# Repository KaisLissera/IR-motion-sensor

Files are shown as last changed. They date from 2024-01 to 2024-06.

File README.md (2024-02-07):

# IR-motion-sensor
*University graduation work*  

Система электронного хронометража для конных соревнований, временные засечки определяются по моменту пересечения луча

## TODO:
### HW
- Заменить SX1276 на аналогичный модуль без интегрированной антенны или RFM95W
- Добавить на плате земляной полигон без маски для тестирования
- ZQ3 - дорожки от кварца должны быть на верхней части платы
- Заменить все резисторы и конденсаторы 0402 на 0603
- Заменить индуктивности в фильтре аналогового питания на дроссели BLM18AG102 0603
### 3d Model
- Переделать отверстие под USB порт
- ~~Подобрать размер кнопки на передней панели~~
- Облегчить корпус

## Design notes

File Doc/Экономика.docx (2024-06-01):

# 5 Организационно-экономическая часть

## 5.1 Расчёт сметных затрат

Разработка системы электронного хронометража состоит из научно-исследовательской (НИР) и опытно-конструкторской частей (ОКР).

В ходе НИР был проведен анализ технических требований. На их основе с учётом имеющихся производственных возможностей сформировано техническое задание и проведены необходимые теоретические исследования.

ОКР по разработке системы электронного хронометража включал в себя три основных этапа – техническое проектирование, изготовление опытного образца и его испытания. В ходе технического проектирования подготовлена конструкторская документация для изготовления опытного образца и разработано необходимое для его работы программное обеспечение. На этапе изготовления опытного образца выполнено физическое производство и настройка изделия. Было интегрировано и отлажено программного обеспечение необходимое для его работы. В ходе испытаний опытного образца проверено его соответствие требуемым техническим требованиям.

После завершения всех этапов НИОКР, расчёт сметных затрат производится по формуле:

| S_(НИОКР) =S_(пр.мат.) +S_(о.т.) +S_(с.в.) +S_(ар.) +S_(накл.) +S_(исп.об.) , | (5.1)

где S_(пр.мат.) – прямые материальные расходы, S_(о.т.) – расходы на оплату труда, S_(с.в.) – расходы на страховые взносы,
S_(о. х.р.) – общехозяйственные расходы, S_(исп.об.) – расходы на амортизацию оборудования.

## 5.2 Прямые материальные расходы

Прямые материальные расходы на проведение НИОКР складываются из стоимости сырья, материалов, радиоэлектронных компонентов (РЭК), используемых для разработки и производства опытных образцов, а также транспортных издержек, связанных с доставкой этих ресурсов.

Расчёт затрат на основные и вспомогательные материалы S_(мат.) производится по формуле:

| S_(мат.) =∑_(i=1)^m X_i ∙M_i , | (5.2)

где X_i – цена покупки единицы i–го вида материальных ресурсов,
M_i – число материальных ресурсов i–го вида, m – число различных материальных ресурсов.

Транспортные затраты рассчитываются с учетом коэффициента транспортных расходов k_(тр) =1,1 . Таким образом прямые материальные расходы рассчитываются по формуле:

| S_(пр.мат.) =k_(тр) ∙S_(мат.) . | (5.3)

Прямые материальные затраты на этапе технического проектирования НИОКР включают в себя расходы, связанные с разработкой конструкторской документации, в соответствии с требованиями к ее комплектности. Затраты на этапе изготовления опытного образца состоят из затрат на радиоэлектронные компоненты, производство печатных плат, изготовление корпуса, крепежные изделия, а также расходные материалы, необходимые для проведения монтажных работ.

Материальные ресурсы, их цена (с учётом НДС) и требуемое количество для этапов технического проектирования и изготовления опытного образца представлены в таблицах 5.1 и 5.2 соответственно.

Таблица 5.1 – Материальные ресурсы этапа технического проектирования

№ п/п | Наименование | Средняя цена за шт., руб. | Кол-во, шт. | Сумма, руб.
1 | Лист формата А4 | 0,8 | 19 | 15,2
2 | Лист формата А3 | 18 | 11 | 198
3 | Лист формата А2 | 30 | 2 | 60
5 | Ручка гелиевая черная 0.5 мм | 50 | 1 | 50
9 | Штрих-корректор | 50 | 1 | 50
| Картридж лазерный для принтера А3 | 1569 | 1 | 1596
| | | Итого: | 1 969,2

Таблица 5.2 – Материальные ресурсы этапа изготовления опытного образца

Наименование | Цена за шт., руб. | Кол-во, шт. | Сумма, руб.

Конденсаторы
1 пФ | 10 | 1 | 10
5,6 пФ | 10 | 3 | 30
18 пФ | 0,4 | 12 | 4,8
100 пФ | 7 | 3 | 21
680 пФ | 0,4 | 1 | 0,4
100 нФ | 0,4 | 42 | 16,8
10 мкФ | 0,4 | 9 | 3,6

Микросхемы
MCP1700-3300 | 9 | 3 | 27
MCP6001 | 33 | 1 | 33
STM32F072RBT6 | 127 | 3 | 381
TSOP4836 | 37 | 1 | 37

Индуктивности
1,2 нГн | 12 | 1 | 12
BLM18AG102SN1D | 3 | 6 | 18

Резисторы
0 Ом | 0,4 | 1 | 0,4
10 Ом | 0,4 | 1 | 0,4
100 Ом | 0,4 | 1 | 0,4
1 кОм | 0,4 | 19 | 7,6
5,1 кОм | 0,4 | 6 | 2,4
10 кОм | 0,4 | 3 | 1,2
100 кОм | 0,4 | 8 | 3,2

Переключатели кнопочные
KLS7-TS6601-5.0-180 | 9 | 3 | 27
KLS7-P8.5x8.5-1 | 21 | 2 | 32

Диоды
USBLC6-2SC6 | 10 | 3 | 30
ESDA5V3L | 10 | 2 | 20
BAT760 | 9 | 3 | 27
SFH213FA | 110 | 1 | 110
SMD05050C6 | 1,1 | 3 | 3,3

Разъёмы
PLS-2R тип D | 1,7 | 3 | 5,1
PLS-6R тип D | 5,1 | 3 | 15,3
USB Type-C 213716-0001 | 17 | 3 | 51

Резонаторы кварцевые
12MHz SMD03225C4 | 9,5 | 3 | 28,5
32.768kHz SMD03215C2 | 18,6 | 3 | 55,8

Прочие РЭК
MF-MSMF050 0,5А | 5 | 3 | 15
HC0905A | 10 | 3 | 30
RFM95W | 350 | 3 | 1050
SI2302A | 4 | 7 | 28
Наименование | Цена за шт., руб. | Кол-во, шт. | Сумма, руб.

Крепёж
Винт М2х5 | 2,2 | 12 | 26,4
Винт М3х5 | 1,4 | 12 | 16,8
Вставка резьбовая М2хL3 | 2,1 | 12 | 25,2
Вставка резьбовая М3хL3 | 2,5 | 12 | 30

Материалы
Провод гибкий 24AWG красный | 1 | 1 шт., 200 мм | 119
Провод гибкий 24AWG чёрный | 1 | 1 шт., 200 мм | 119
Пластик АВС-2802-31 | 1 | 1 шт., 1 кг | 1794
Припой ПОС-61 | 1 | 1 шт., 100 г | 597
Флюс ЛТИ-120 | 1 | 1 шт., 20 мл | 350
Жидкость для очистки бензин «Галоша» | 1 | 1 шт., 500мл | 407

Прочее
Платы печатные | - | 3 | 819
Контакт отрицательный для батареи типа АА | 3,4 | 6 | 20,6
Контакт положительный для батареи типа АА | 3,4 | 6 | 20,6
Элемент питания АА | 70 | 6 | 420
Вилка на кабель HU-02 | 2 | 3 | 6
| | | Итого: | 6 908,8

Согласно формуле 5.2, затраты на основные и вспомогательные материалы на всех этапах НИОКР составляют:

S_(мат.) =S_(мат.(проект.)) +S_(мат.(изготовл.)) =1 969,2+6 908,8=8 878 руб .

С учётом транспортных затрат по формуле 5.3 прямые материальные расходы на НИОКР составят:

S_(пр.мат.) =k_(тр) ∙S_(мат.) =1,1∙8 878=9 765,8.

## 5.3 Расчёт трудоёмкости проекта и расходов на заработную плату

Согласно техническому заданию НИОКР должны быть выполнены в период с 4 марта 2024 года по 31 мая 2024 года, что составляет 60 рабочих дней. При 40-часовой рабочей неделе длительность рабочего дня составляет 8 часов, таким образом на выполнение НИОКР отводится 480 часов.

Трудоёмкость проекта рассчитывается с учётом норм времени, установленных ШИФР 13.01.01 «Типовые нормативы времени на разработку конструкторской документации».

Таблица 5.4 – Перечень разработанной конструкторской документации

Документ | | Формат | Число листов | Норма времени, ч
МГТУ.403443.001 | Спецификация | А4 | 1 | 0,3
МГТУ.403443.001 Э1 | Схема электрическая структурная | А3 | 1 | 3,36
МГТУ.464415.001 | Спецификация | А4 | 2 | 0,7
МГТУ.464415.001 CБ | Чертёж сборочный | А3 | 1 | 1,7
МГТУ.464415.002 | Спецификация | А4 | 3 | 1,6
МГТУ.464415.002 СБ | Чертёж сборочный | А3 | 2 | 2,4
МГТУ.469335.001 | Спецификация | А4 | 5 | 4
МГТУ.469335.001 СБ | Чертёж сборочный | А3 | 2 | 4
МГТУ.469335.001 Э3 | Схема электрическая принципиальная | А2 | 1 | 25,92
МГТУ.469335.001 ПЭ3 | Перечень элементов | А4 | 5 | 4,7
МГТУ.713621.001 | Чертёж | А4 | 1 | 0,53
МГТУ.731146.001 | Чертёж | А3 | 2 | 1,2
МГТУ.741316.001 | Чертёж | А4 | 1 | 0,35
МГТУ.741344.001 | Чертёж | А3 | 2 | 2,92
МГТУ.758741.001 | Чертёж | А3 | 2 | 1,43
| | | Итого: | 55,11

Последовательность этапов НИОКР, исполнитель и длительность приведены в таблице 5.5.

Таблица 5.5 – Последовательность этапов НИОКР

№ этапа | Содержание этапа работ | Исполнитель | Длительность этапа
1 | НИР | | 28% | 136 ч.
1.1 | Разработка технического задания | Инженер-конструктор | 2% | 8
1.2 | Теоретические исследования | Инженер-конструктор | 26% | 128
2 | ОКР | | 72% | 344 ч.
2.1 | Разработка конструкторской документации | Инженер-конструктор | 12% | 56
2.2 | Разработка программного обеспечения | Инженер-программист | 17% | 80
2.3 | Изготовление опытного образца | Монтажник РЭА | 8% | 40
2.4 | Испытания опытного образца | Инженер-конструктор | 10% | 48
2.5 | Оформление расчётно-пояснительной записки | Инженер-конструктор | 25% | 120
Итого | | | 100% | 480 ч.

Требуемые для выполнения этапов НИОКР сотрудники, количество их рабочих часов и приведены в таблице 5.6.

Таблица 5.6 – Требуемые сотрудники

Категория сотрудника | Число сотрудников, чел. | Рабочие часы, ч. | Часовая тарифная ставка, руб./ч.

НИР
Инженер–конструктор | 1 | 136 | 620

ОКР
Инженер–конструктор | 1 | 224 | 620
Инженер-программист | 1 | 80 | 940
Монтажник РЭА и печатных плат | 1 | 40 | 250

Затраты на оплату труда сотрудников S_(о.т.) рассчитываются по формуле:

| S_(о.т.) =S_(з.п.) +S_(з.п.доп) . | (5.4)

где S_(з.п.) – затраты по основной заработной плате, S_(з.п.доп.) – затраты по дополнительной заработной плате.

Затраты по основной заработной плате рассчитываются по формуле:

| S_(з.п.) =∑_(i=1)^k N_i ·T_(р.ч. i) ·L_(ч. i) . | (5.5)

где N_i – число работников, T_(р.ч. i) – число рабочих часов на одного сотрудника, L_(ч. i) – часовая тарифная ставка, k – число различных категорий сотрудников.

Согласно формуле 5.5 затраты по основной заработной плате для реализации каждого из этапов составят:

S_(з.п.(НИР)) =(620∙136) руб.=79 360 руб,

S_(з.п.(ОКР)) =(620∙224+80∙940+40∙250) руб.=224 080 руб,

S_(з.п.) =S_(з.п.(НИР)) +S_(з.п.(ОКР)) =303 440 руб.

Затраты по дополнительной заработной плате вычисляются по формуле:

| S_(з.п.доп) =α·S_(з.п.осн) , | (5.6)

где α –отношение дополнительной заработной платы к основной.

Пусть затраты по дополнительной заработной плате составляют 10% от основной заработной платы, тогда по формуле 5.6 для каждого из этапов затраты составят:

S_(з.п.доп.(НИР)) =(79 360 ·0,1) руб.=7 936 руб,

S_(з.п.доп.(ОКР)) =(224 080 ·0,1) руб.=22 408 руб,

S_(з.п.доп.) =(7 936+22 408) руб.=30 344 руб.

Согласно формуле 5.4 затраты на оплату труда для реализации каждого из этапов и для НИОКР в целом составят:

S_(о.т.(проект.)) =(79 360+7 936) руб=87 296 руб,

S_(о.т.(прозв.)) =(224 080+22 408) руб.=246 488руб,

S_(о.т.) =(303 440+30 344) руб. =333 784 руб.

## 5.4 Расходы на страховые взносы

Страховые взносы состоят из:

- страховых взносов на пенсионное страхование – 22%;
- страховых взносов на медицинское страхование – 5,1%;
- страховые взносы на социальное страхование – 2,9%;
- страховые взносы на случай несчастных случаев и профессиональных заболеваний – 0,2%.

Поскольку разработка системы электронного хронометража — это разовые краткосрочные работы, с работниками можно заключить договор гражданско-правового характера (ГПХ), без оформления их в штат. Оплата труда будет производиться на основании выполненных работ, а не в виде заработной платы. В случае заключения договора ГПХ работодатель не платит страховые взносы на социальное страхование и взносы на случай несчастных случаев и профессиональных заболеваний.

Таким образом суммарно затраты на страховые взносы k_c равны 27,1% от всей заработной платы и рассчитываются по формуле:

S_(с.в.) =k_c ·S_(о.т.) . | (5.7)

Согласно формуле 5.7 суммарные затраты на страховые взносы составят

S_(с.в.) =(0,271∙333 784) руб.=90 456 руб.

## 5.5 Расходы на аренду

Помещение для проведения НИОКР имеет площадь достаточную для размещения рабочих мест для всех работников необходимых для его реализации, площади 25 м^2 достаточно для размещения трёх рабочих мест, план рабочей комнаты приведён в разделе 6. Средняя стоимость аренды одного квадратного метра производственной площади, с учётом коммунальных услуг, в Москве составляет около 12 000 руб. в год или 1 000 руб. в месяц. Учитывая соотношения длительностей этапов, затраты на аренду для реализации каждого из этапов и для НИОКР в целом составят:

S_(ар.(НИР)) =(1 000∙3∙ 0,27∙25) руб.=20 250 руб,

S_(ар.(ОКР)) =(1 000∙3∙0,73∙ 25) руб.=54 750 руб,

S_(ар) =(1 000∙3∙ 25) руб.=75 000 руб.

## 5.6 Накладные расходы

Накладные расходы связаны с организацией, обслуживанием и управлением производством. Они включают в себя расходы на содержание управленческого аппарата, бухгалтерию, юридическое сопровождение, содержание информационной инфраструктуры, закупку офисных принадлежностей. Для обеспечения накладных затрат выделена сумма в 50% от основной заработной платы. Тогда накладные расходы для реализации каждого из этапов и для НИОКР в целом:

S_(накл.(НИР)) =(79 360 ·0,5) руб.=39 680 руб,

S_(накл.(ОКР)) =(224 080 ·0,5) руб.=112 040 руб,

S_(накл.) =(39 680+112 040) руб.=151 720 руб.

## 5.7 Расходы на использование оборудования

Использованное в процессе выполнения НИОКР оборудование приведено в таблице 5.7.

Таблица 5.7 – Используемое оборудование

Наименование | Балансовая стоимость, руб. | Кол-во, шт.
Персональный компьютер | 110 000 | 3
Лазерное МФУ HP LaserJet M442dn | 67 000 | 1
Лабораторный блок питания ELEMENT 1502D | 2 500 | 1
Паяльная станция ELMENT 878D | 5 500 | 1
Цифровой осциллограф FNIRSI 1014D | 13 000 | 1
Мультиметр цифровой DT-830B | 250 | 1
Векторный анализатор цепей NanoRFE VNA6000 | 150 000 | 1

На объекты основных средств стоимостью до 10 000 рублей включительно амортизация не начисляется. На объекты основных средств стоимостью от 10 000 до 100 000 рублей амортизация начисляется в размере 100% первоначальной стоимости при выдаче его в эксплуатацию. Имущество дороже 100 000 рублей со сроком полезного использования (СПИ) более 12 месяцев включается в состав основных средств и амортизируется. СПИ определяется в соответствии с постановлением правительства РФ от 01.01.2002 N 1 (ред. от 18.11.2022) "О Классификации основных средств, включаемых в амортизационные группы". Согласно постановлению СПИ персонального компьютера составляет 3 года, а векторного анализатора цепей 10 лет.

Годовые амортизационные отчисления A_i рассчитываются по формуле:

| A_i =a_i ·Ц_i , | (5.8)

где a_i – норма амортизации, Ц_i – балансовая стоимость оборудования.

По формуле 5.8 амортизационные отчисления за 3 месяца НИОКР составят:

A=3(0,1∙150 000)/12+3(0,33∙110 000)/12=12 825 руб.

Затраты на ремонтное обслуживание примем равными 1,5%, а на электроэнергию – 10% от величины амортизационных отчислений.

Затраты на использование оборудования включают в себя амортизацию, затраты на энергию и ремонт, и для реализации каждого из этапов и для НИОКР в целом составят:

S_(исп.об.) =(1,115∙12 825) руб.=14 300 руб.,

S_(исп.об.(НИР)) =(14 300 ·0,27) руб.=3 861 руб,

S_(исп.об.(ОКР)) =(14 300 ·0,73) руб.=10 439 руб.

## 5.8 Расчёт сметной себестоимости НИОКР

Рассчитанные ранее расходы для реализации каждого из этапов НИОКР сведены в таблицу 5.8.

Таблица 5.8 – Смета затрат на выполнение НИОКР

Статья расходов | Затраты на реализацию НИР, руб. | Затраты на реализацию ОКР, руб.
Прямые материальные расходы | 1 970 | 6 909
Расходы на оплату труда | 87 296 | 246 488
Расходы на страховые взносы | 24 423 | 66 033
Расходы на аренду | 20 250 | 54 750
Накладные расходы | 39 680 | 112 404
Расходы на использование оборудования | 3 861 | 10 439
Итого | 177 480 | 497 023

Затраты на проведение НИОКР составляют:

S_(НИОКР) =S_(НИР) +S_(ОКР) =674 503 руб.

Планируемая цена разработки и изготовления одной единицы системы электронного хронометража рассчитывается с учётом 20% прибыли:

Ц=1,2∙674 503 руб. =773 908 руб.

Ленточный план-график выполнения работ приведён на рисунке 5.1.

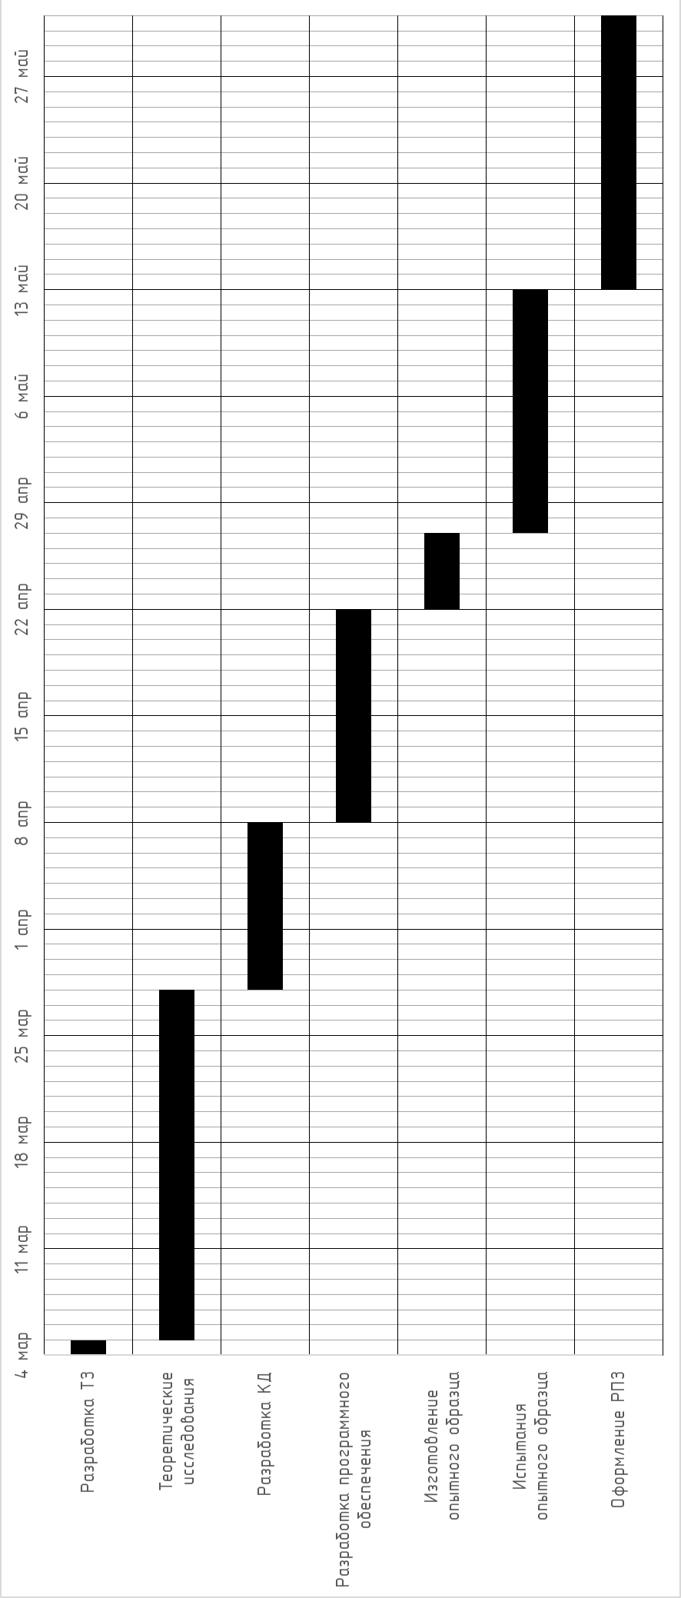
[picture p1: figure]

| Рисунок 5.1 - Ленточный план-график выполнения работ

Подп. и дата Инв. № дубл. Взам. Инв. № Подп. и дата Инв. № подл. ГОСТ 2.106-96 ф. 9а Копировал Формат А4 Изм Лист № докум. Подп. Дата Лист

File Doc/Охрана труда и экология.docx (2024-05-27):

# 6 Охрана труда и экология

## 6.1 Анализ опасных и вредных факторов

Целью выпускной квалификационной работы является разработка системы электронного хронометража. Составной частью разработанной системы является печатная плата с ИК излучателем и радиопередатчиком.

При ручном монтаже и регулировке печатных плат могут возникать потенциально опасные и вредные факторы, воздействие которых на организм человека может принести ему вред и привести к травматизму. Их список приведён в таблице 6.1.

Таблица 6.1 – Перечень основных опасных и вредных факторов

Фактор | Нормирующий документ | Возможные последствия
Чрезмерное загрязнение воздушной среды в зоне дыхания | СанПиН 1.2.3685-21 | Раздражение воздушных путей, отравление
Химическое воздействие на организм человека (токсическое, раздражающее, канцерогенное) | СанПиН 1.2.3685-21 | Ингаляционные и кожные заболевания, аллергические реакции
Микроклиматические параметры среды на местонахождении работающего | СанПиН 1.2.3685-21 | Ухудшение продуктивности и эффективности
Чрезмерно высокая или низкая температура материальных объектов производственной среды, способных вызвать ожоги | СанПиН 1.2.3685-21 | Ожоги
Наличие электромагнитных полей радиодиапазона | СанПиН 1.2.3685-21 | Профессиональные заболевания, электротравмы
Наличие некогерентного инфракрасного излучения | СанПиН 1.2.3685-21 | Ухудшение зрительной функции, профессиональные заболевания
Световая среда и чрезмерные характеристики световой среды, затрудняющие безопасное ведение трудовой и производственной деятельности | СанПиН 1.2.3685-21, СП 52.13330.2016 | Ухудшение зрительной функции, ухудшение продуктивности и эффективности
Электрический ток, вызываемый разницей электрических потенциалов, под действие которого попадает работающий | ГОСТ 12.1.038-82 | Электротравмы
Пожар | ГОСТ 12.1.004-15 | Ожоги, отравление угарным газом

К условиям труда предъявляются требования, предписанные санитарными правилами и нормами (СанПин), санитарными нормами (СН) и ГОСТ. Рассмотрим предписанные ими требования к вредным и потенциально опасным факторам, воздействующим на работника.

Предельно допустимые концентрации загрязняющих веществ в воздухе рабочей зоны их агрегатное состояние и класс опасности в соответствии с СанПин 1.2.3685-21 приведены в таблице 6.2.

Таблица 6.2 – Предельно допустимые концентрации загрязняющих веществ в воздухе рабочей зоны

Наименование вещества | Величина ПДК мг/м³ | Преимущественное агрегатное состояние в воздухе в условиях производства | Класс опасности | Особенности воздействия на организм
Канифоль | 4 | Смесь пара и аэрозоля | 3 | Аллерген
Свинцово-оловянные припои | 0,05 | Аэрозоль | 1 | -
Спирт этиловый | 2000 | Пары | 4 | -
Бензин | 300 | Пары | 4 | -

По уровню энергозатрат монтаж и регулировка печатных плат относится к категории работ Ia с энергозатратами до 139 Вт. Для данной категории работ СанПин 1.2.3685-21 устанавливает следующие параметры микроклимата:

- перепад температуры воздуха по высоте от уровня пола не более 3°С;
- перепад температуры воздуха по горизонтали, а также её изменение в течении смены не должны превышать 4°С.

Допустимые температура воздуха, поверхностей, относительная влажность и скорость движения воздуха на рабочем месте приведены в таблице 6.3.

Таблица 6.3 – Допустимые параметры микроклимата на рабочем месте

Период года | Температура воздуха | Температура поверхностей | Относительная влажность воздуха | Скорость движения воздуха
Холодный | 20-25 | 19,0-26,0 | 15-75 | 0,1
Тёплый | 21-28 | 20,0-29,0 | 15-75 | 0,1

На рабочем месте используется паяльная станция с паяльником, разогретым до температуры 300 градусов, необходимая для осуществления ручного монтажа печатных плат. В таблице 6.4 приведены допустимые величины интенсивности теплового облучения поверхности тела от производственных источников, нагретых до температуры не более 600 °C.

Таблица 6.4 – Допустимые величины интенсивности теплового облучения

Облучаемая поверхность тела, % | Интенсивность теплового облучения, Вт/м2, не более
50 и более | 35
25 - 50 | 70
не более 25 | 100

Система электронного хронометража имеет в своём составе радиопередатчик с печатной антенной, работающий на частоте 868 МГц. При регулировке платы производится согласование антенны и при этом возможно облучение работника электромагнитным полем радиочастотного диапазона. В соответствии с СанПин 1.2.3685-21 предельно допустимый уровень энергетической экспозиции ЭМП для данного диапазона ЭЭ_(ППЭ) =200 мкВт∙ч/см^2 . Энергетическая экспозиция рассчитывается по формуле:

ЭЭ_(ППЭ) =ППЭ∙Т,

где ППЭ – плотность потока энергии мкВт/см^2 , Т – время воздействия за смену, ч.

Для кратковременных воздействий плотность потока энергии не должна превышать предельно допустимые уровни плотности потока энергии электромагнитного поля, для данного диапазона частот это 1000 мкВт/см^2 , или в случае локального облучения кистей рук 5000 мкВт/см^2 .

В случае локального облучения рук при работе с микрополосковыми устройствами предельно допустимый уровень плотности потока энергии для соответствующего времени облучения (ППЭпду) рассчитывается по формуле:

ППЭ_(ПДУ) =К∙ЭЭ_(ПДУ) /Т,

где К=12,5 – коэффициент снижения биологической активности воздействия, Т – время воздействия за смену, ч.

Печатный узел, использующийся в системе электронного хронометража, содержит ИК излучатель, работающий с длиной волны 940 нм. СанПин 1.2.3685-21 содержит требования к значения энергетической экспозиции Н_(ПДУ) и энергетической освещенности Е_(ПДУ) ИК-излучения в зависимости от длительности воздействия на глаза и кожу, приведённые в таблице 6.5.

Таблица 6.5 - Предельные значения энергетической экспозиции и освещенности рассеянного ИК-излучения длиной волны 940 нм

Время действия Т, с | Н_(ПДУ) , Дж/м^2 | Е_(ПДУ) , Вт/м^2
10^(-10) <Т≤ 1 | 2·10^4 ·⁵√Т | -
10^(-10) <Т≤ 1 | - | 2·10^4 /⁵√(Т^4)
10^(-10) <Т≤ 1 | - | 5∙10^2

Рассмотрим нормативные показатели световой среды согласно СанПин 1.2.3685-21. Площадь рабочей поверхности при пайке больше 0,1 м^2 , при этом наибольшая допустимая яркость рабочей поверхности составляет 500 кд/м^2 . Работы по монтажу печатных плат относятся к III разряду зрительной работы (работы высокой точности), поскольку наименьший размер объекта различения находится в диапазоне 0,3..0,5 мм. Установленные требования к освещённости рабочих мест на промышленных предприятиях для данного класса работ приведены в таблице 6.6.

Таблица 6.6 - Требования к освещению рабочего места

Подразряд зрительной работы | Контраст объекта с фоном | Характеристика фона | Освещенность, лк
| | | Комбинированное освещение | | Общее освещение
| | | всего | от общего
а | малый | тёмный | 2000-1500 | 200 | 500-400
б | малый | средний | 1000-750 | 200 | 300-200
| средний | тёмный
в | малый | светлый | 750-600 | 200 | 300-200
| средний | средний
| большой | тёмный
г | средний | светлый | 400 | 200 | 200
| большой | светлый
| большой | средний

Коэффициент пульсации освещённости не должен превышать 15 %, в случае если рабочее место оборудовано ПЭВМ не должен превышать 5 %. Объединенный показатель дискомфорта, UGR, не более 22. Для общего искусственного освещения следует использовать источники света с индексом цветопередачи Ra ≥ 85%.

Напряжения прикосновения и токи, протекающие через тело человека при нормальном (неаварийном) режиме электроустановок, устанавливаются ГОСТ 12.1.038-82 и не должны превышать значений, указанных в таблице 6.7.

Таблица 6.7 – Предельно допустимые значения напряжений прикосновения и токов

Род тока | U, В | I, мА
| не более
Переменный, 50Гц | 2,0 | 0,3
Переменный, 400Гц | 3,0 | 0,4
Постоянный | 8,0 | 1,0

## 6.2 Расчёт искусственного освещения

Для расчёта искусственного освещения использовался программный пакет позволяющий создать модель производственного помещения с использованием существующих коммерческих моделей светильников. Модель помещения с учётом расстановки мебели приведена на рисунке 6.1.

Для освещения используются светодиодные светильники, поскольку они обеспечивают низкое энергопотребление, высокую долговечность и экологичность. В рабочем помещении используются встраиваемые потолочные светильники для общего освещения и подвесной светильник для создания дополнительной освещённости в зоне проведения электромонтажных работ. Характеристики использованных светильников приведены на рисунке 6.2.

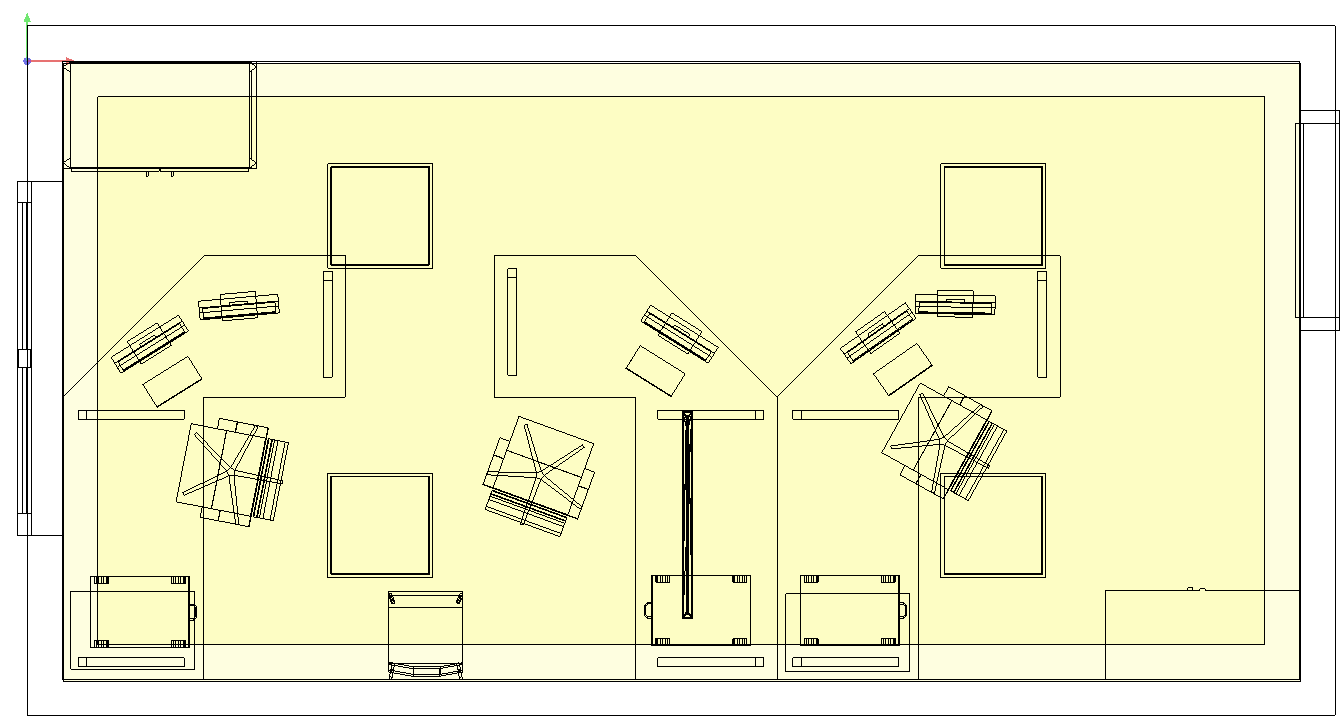
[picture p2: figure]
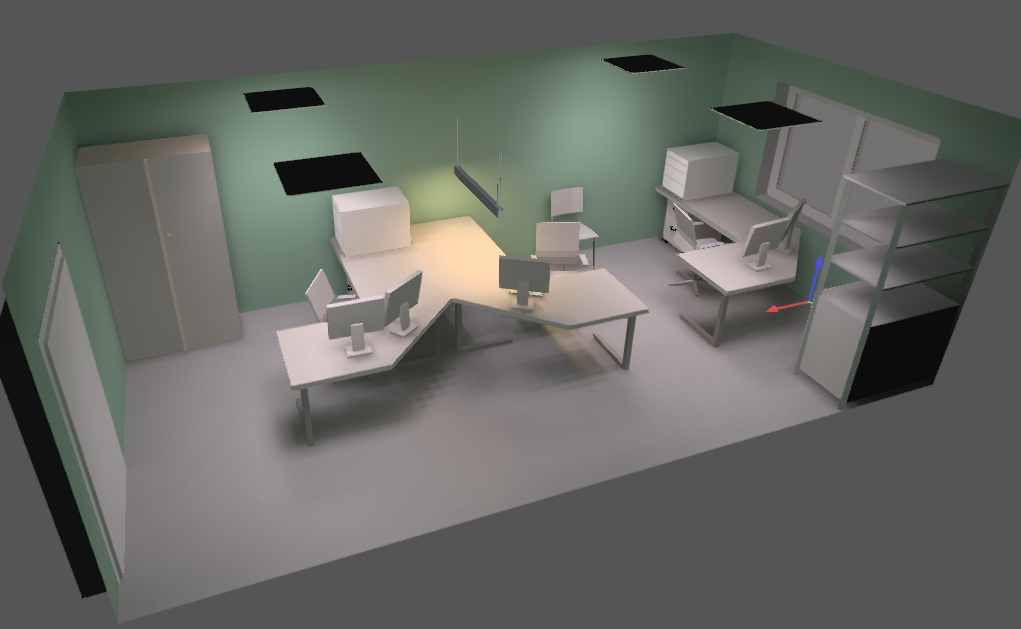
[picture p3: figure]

Рисунок 6.1 – Модель исследуемого помещения и её трёхмерный вид

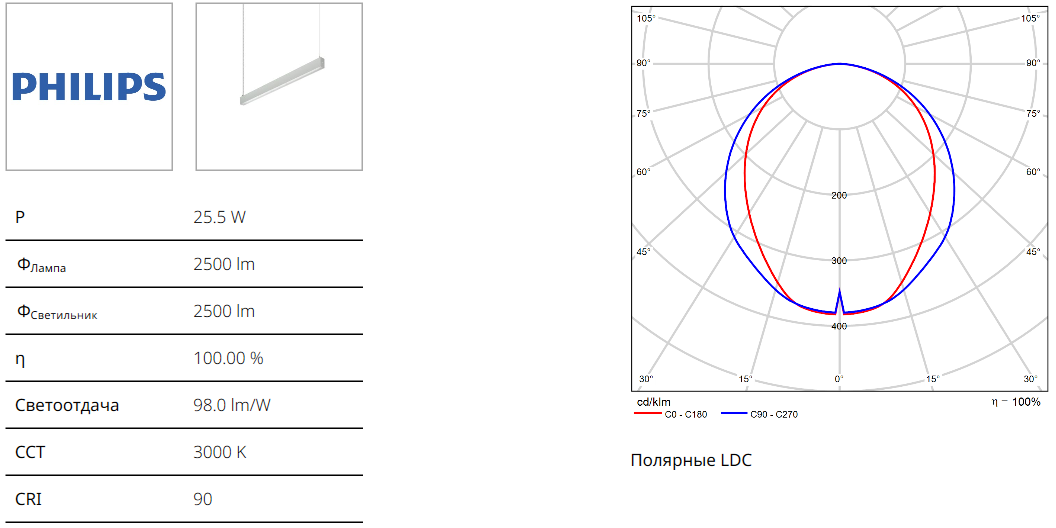
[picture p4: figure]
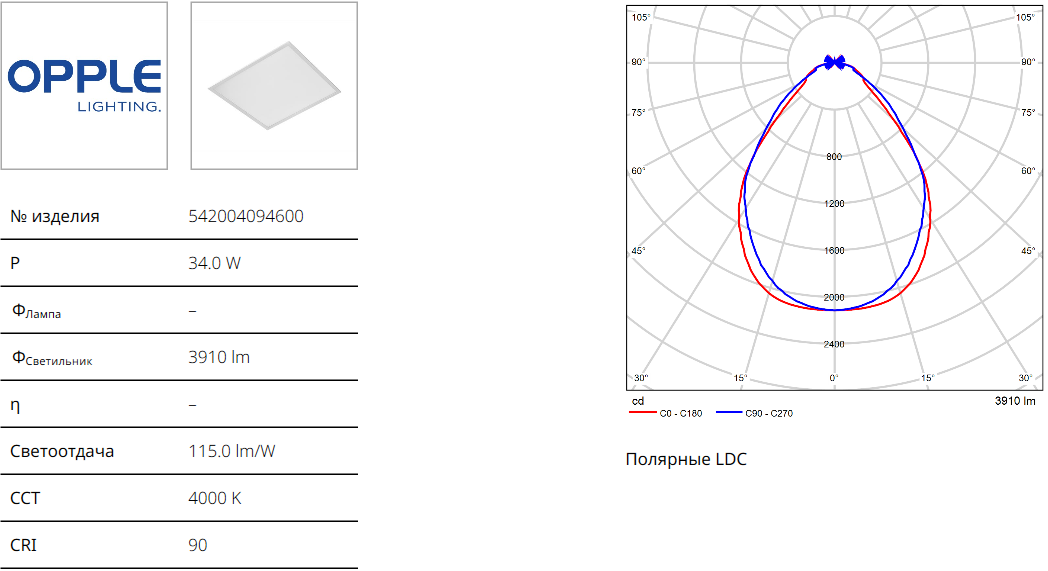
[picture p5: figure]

Рисунок 6.2 – Характеристики выбранных светильников

Основные параметры освещённости, полученные после расчёта приведены в таблице 6.8.

Таблица 6.8 – Параметры освещённости

Поверхность | Е_(ср) , лк | Е_(мин) , лк | Е_(макс) , лк | Е_(мин) /Е_(ср)
Помещение | 531 | 0,6 | 1511 | 0
Зона электромонтажных работ | 1116 | 750 | 1394 | 0,67
Пол | 260 | 0,11 | 558 | 0

В результате моделирования в получено распределение освещённости рабочего помещения. На рисунке 6.3 показано распределение изолиний освещенности в горизонтальной плоскости на уровне рабочей поверхности, а на рисунке 6.4 – в зоне проведения монтажа печатных плат.

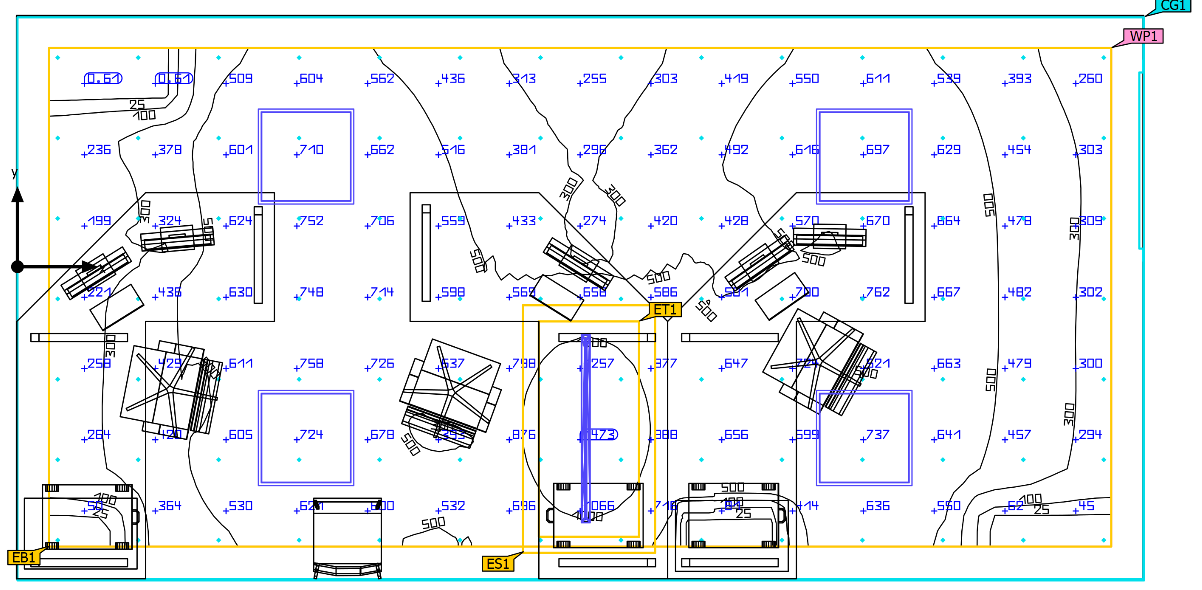
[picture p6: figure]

Рисунок 6.3 – Общий вид комнаты, уровень освещённости на уровне рабочих поверхностей

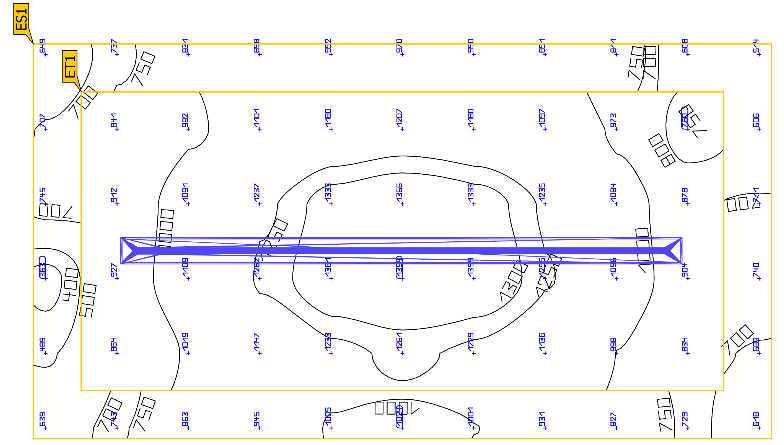
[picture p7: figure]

Рисунок 6.4 – Уровень освещённости в зоне проведения электромонтажных работ

Потребляемая для освещения помещения мощность 162 Вт, удельная мощность освещения 6,6 Вт/м^2 .

## 6.3 Экологическая экспертиза проекта

Целью экологической экспертизы является оценка возможного воздействия на окружающую среду в процессе разработки и изготовления системы электронного хронометража. Основное воздействие на окружающую среду связано с производственным процессом:

- электропотребление оборудования на этапе изготовления опытного образца;
- отходы производства: электронные компоненты, бракованные печатные платы, промывочная жидкость, обтирочная ветошь.

Федеральный закон от 24.06.1998 N 89-ФЗ "Об отходах производства и потребления" устанавливает общие требования к обращению с отходами, включая порядок их сбора, накопления, транспортирования, обработки, утилизации, обезвреживания и размещения. Дополняет его Федеральный классификационный каталог отходов (ФККО), содержащий единую систему классификации и кодирования отходов. Класс опасности и коды ФККО для отходов, возникающих при производстве перечислены в таблице 6.9.

Таблица 6.9 – Основные отходы производства

Наименование | Код ФККО | Класс опасности
Светодиодные лампы | 4 82 415 01 52 4 Светодиодные лампы, утратившие потребительские свойства | IV
Остатки флюсов | 3 71 122 31 10 4 Воды промывки печатных плат после их химической и гальванической обработки | III
Промывочная жидкость | 3 71 122 43 10 3 Спирт этиловый, загрязненный канифолью при обезжиривании печатных плат после пайки в их производстве | III
Обтирочная ветошь | 3 71 125 12 60 3 Обтирочный материал, загрязненный свинцом и оловом при изготовлении печатных плат | III

Подп. и дата Инв. № дубл. Взам. Инв. № Подп. и дата Инв. № подл. ГОСТ 2.106-96 ф. 9а Копировал Формат А4 Изм Лист № докум. Подп. Дата Лист

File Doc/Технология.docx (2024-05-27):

# 3 Технологическая часть

## 3.1 Разработка стенда проверки характеристик радиоподсистемы устройств системы электронного хронометража

Одной из важнейших подсистем устройств системы электронного хронометража является радиоподсистема. С помощью радиосвязи устройства системы обмениваются данными между собой, и от характеристик радиоподсистемы этих устройств зависит качество передачи данных.

Для проверки технических характеристик радиоподсистемы устройств необходим специальный стенд. В рамках технологической части выпускной квалификационной работы разработан стенд для проверки характеристик радиоподсистемы устройств.

Структурная схема стенда представлена на рисунке 3.1.

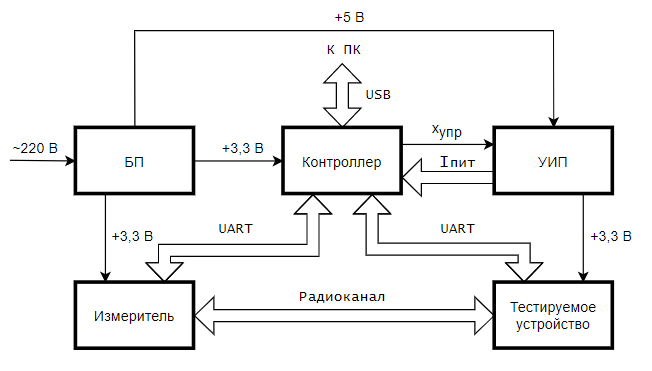
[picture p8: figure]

Рисунок 3.1 – Структурная схема стенда

На рисунке 3.1 присутствуют следующие обозначения: БП – блок питания, УИП – управляемый источник питания, ПК – персональный компьютер.

В состав стенда входят:

● блок питания (БП), подключенный к сети 220 В;

● контроллер;

● управляемый источник питания (УИП);

● измеритель;

● тестируемое устройство.

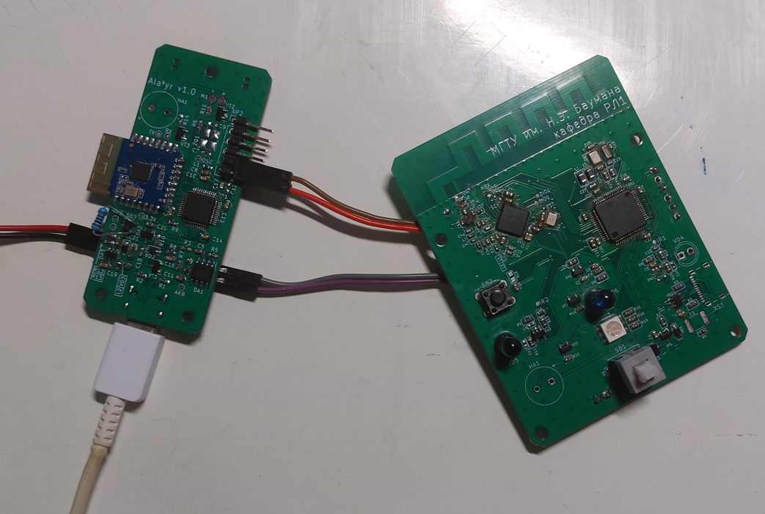
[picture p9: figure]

Рисунок 3.2 – Тестируемое устройство подключённое к контроллеру

Головным элементом стенда является контроллер, который основан на микроконтроллере STM32 и управляет всем стендом. Устройство контроллер подключено к ПК через USB. На компьютере может быть написана специальная программа для управления стендом. Также можно использовать обычный терминал, посылая по USB на контроллер символьные команды, а в ответ получая результаты проверки характеристик радиоподсистемы тестируемых устройств. Основа взаимодействия ПК и контроллера заключается в обмене командами и данными между ними.

Контроллер управляет УИП, управляющим воздействием x_(упр) , и получает от него значение потребляемого тока I_(пит) тестируемым устройством. УИП питает напряжением 3,3 В тестируемое устройство. Контроллер может отключать питание тестируемого устройства, если потребляемый ток является слишком низким или слишком высоким. В таких критических ситуациях контроллер сигнализирует о неисправности, отправляя на ПК ошибку или уведомление.

Измерителем является откалиброванное устройство, основанное на плате, используемой в устройствах системы электронного хронометража

Измеритель подключен к контроллеру по интерфейсу UART. Контроллер может отправлять команды на измеритель (команда на излучение контрольного радиосообщения, прием сигнала от тестируемого устройства и т.д.) и получать от него измеренные данные, например, уровень мощности принимаемого сигнала от тестируемого устройства или корректность принятых данных.

Контроллер, измеритель и УИП получают питание от БП. Необходим такой блок питания, который имеет несколько выходных клемм и регулируемое выходное напряжение, так как для измерителя и контроллера требуется напряжение питания 3,3 В, а для управляемого источника питания требуется 5 В.

Также контроллер подключается по интерфейсу UART к тестируемому устройству. Для включения режима тестирования отправляется специальная команда на устройство. После чего могут быть отправлены команды на излучение или прием контрольного радиосообщения мощности 0,1 мВт. При излучении тестируемым устройством радиосигнала измеритель отправляет данные об уровне принятого сигнала на контроллер, т.е. измеряется исправность радиотракта на излучение. При приеме тестируемым устройством радиосигнала проверяется чувствительность трансивера СС1101, и данные отправляются на контроллер для последующего анализа.

Полный алгоритм работы стенда описан в пункте 3.1.2.

Стенд помещен в мини-камеру с радиопоглощающим покрытием. Такая мини-камера необходима для более точного измерения уровня принимаемого сигнала как измерителем, так и тестируемым устройством, так как будут минимизированы отражения излучаемого сигнала и внешние помехи.

Внешний вид мини-камеры представлен на рисунке 3.2.

Внутри мини-камеры устанавливается неподвижно измеритель с одной стороны и тестируемое устройство с специальный держатель с другой стороны параллельно друг другу на одинаковой высоте. Если измеритель, контроллер и УИП не соединены жестко между собой и не являются одним устройством, то контроллер и УИП могут быть расположены вне мини-камеры и соединяться с измерителем и тестируемым устройством с помощью гибких проводов через отверстия в мини-камере. Блок питания обычно имеет немаленькие размеры и металлический корпус, поэтому он располагается вне мини-камеры. Тестируемое устройство устанавливается в стенд без корпуса, только плата.

## 3.1.2 Разработка алгоритма работы стенда проверки технических характеристик радиоподсистемы устройств

Последовательный алгоритм работы стенда:

1) Подключение контроллера стенда к персональному компьютеру по USB;

2) Включение питания контроллера, измерителя и управляемого источника питания от блока питания;

3) Установка тестируемого устройства на специальный держатель внутрь мини-камеры с радиопоглощающим покрытием и подключение тестируемого устройства к контроллеру и к УИП;

4) Отправка управляющего воздействия x_(упр) , сигнализирующего о необходимости включения питания тестируемого устройства, на УИП и измерение тока питания I_(пит) тестируемого устройства, обработка полученного значения тока питания: если значение тока превышает граничное значение, т.е. присутствует короткое замыкание, то незамедлительное отключение питания тестируемого устройства, также отключается устройство от питания, если значение потребляемого тока ниже граничного или равно нулю, окончание проверки, вывод отчета о проведенной проверке характеристик радиоподсистемы устройства на компьютер;

5) Закрытие мини-камеры крышкой и подключение контроллера к тестируемому устройству по UART, а при отсутствии подключения или некорректной работе окончание проверки, вывод отчета о проведенной проверке характеристик радиоподсистемы устройства на компьютер;

6) Отправка по UART на измеритель команды включения режима приема радиосообщения, а на тестируемое устройство передается по UART команда включения режима отправки контрольного радиосообщения мощностью 0,1 мВт, получение результатов измерения уровня мощности принимаемого радиосообщения и его обработка;

7) Отправка на измеритель команды включения режима отправки контрольного радиосообщения мощностью 0,1 мВт, а на тестируемое устройство отправляется команда включения режима приема радиосообщения, получение результатов измерения чувствительности трансивера тестируемого устройства и его обработка;

8) Отправка на измеритель и тестируемое устройство команды перехода в обычный режим работы, обработка результатов тестирования и вывод на экран персонального компьютера отчета о проведенной проверке характеристик радиоподсистемы устройства;

9) При окончании проверки отключение контроллера от тестируемого устройства по UART и отправка управляющего воздействия на УИП с целью отключения питания тестируемого устройства, отключение контроллера от ПК, отключение питания от БП всех устройств стенда, окончание тестирования.

В отчете о проведенной проверке характеристик радиоподсистемы устройств представляется заключение с результатами проверки с измеренными значениями уровня мощности принятого контрольного радиосообщения (по этому уровню судится качество излучаемой способности тестируемого устройства) и чувствительности трансивера в дБ. Если результаты проверки не соответствуют требуемым, в отчете представляется заключение об этом факте с измеренными значениями уровня мощности принятого контрольного радиосообщения и чувствительности трансивера и с предполагаемыми неисправностями, описанными в таблице 3.1.

Таблица 3.1 – Предполагаемые неисправности радиоподсистемы устройств

Описание проблемы | Предполагаемая неисправность
Отсутствие потребляемого тока | Возможное отсутствие компонентов в цепях питания, отсутствие контакта выводов элементов питания с контактными площадками, неисправность компонентов.
Слишком высокий потребляемый ток | Короткое замыкание.
Отсутствие подключения по UART к устройству | Неисправность микроконтроллера, отсутствие контакта выводов микроконтроллера к контактным площадкам, неисправность разъема.
Некорректная работа UART | Возможна проблема с питанием микроконтроллера, установлены компоненты с несоответствующими номиналами в цепях питания.
Несоответствующий уровень излучаемого устройством радиосигнала или его отсутствие | Неисправность трансивера СС1101, отсутствие компонентов радиотракта, отсутствие контакта выводов компонентов радиотракта с контактными площадками.
Несоответствующий уровень чувствительности трансивера устройства | Неисправность трансивера СС1101

Обобщенный алгоритм работы стенда представлен на рисунке 3.3.

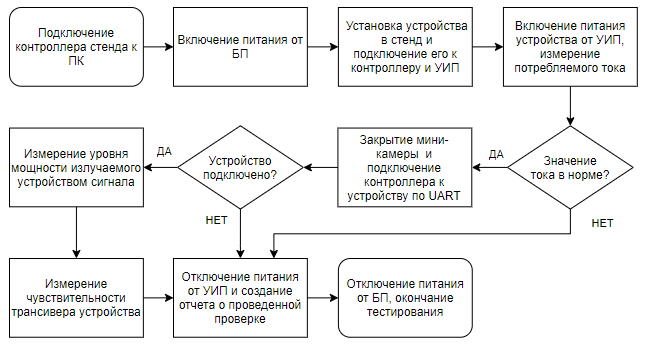
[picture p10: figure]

Рисунок 3.3 – Обобщенный алгоритм работы стенда

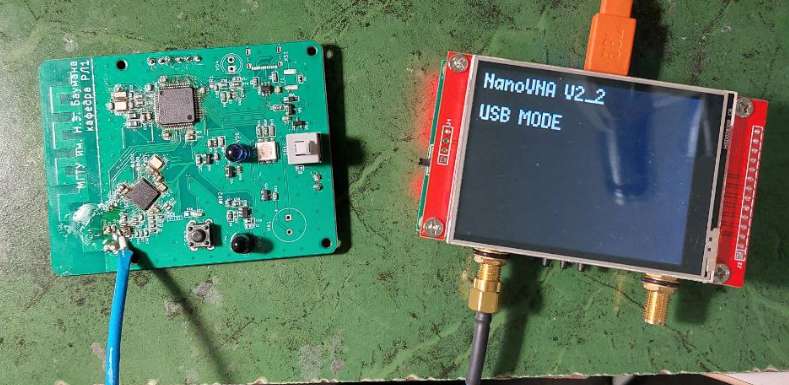
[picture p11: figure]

Рисунок 3.4 – Стенд для тестирования и настройки радиопередатчика устройства

Таким образом, разработан стенд для проверки характеристик радиоподсистемы устройств системы электронного хронометража. Разработаны структурная схема и алгоритм работы стенда. Даны типичные неисправности, которые могут возникнуть в ходе проверки устройств на стенде.

Подп. и дата Инв. № дубл. Взам. Инв. № Подп. и дата Инв. № подл. ГОСТ 2.106-96 ф. 9а Копировал Формат А4 Изм Лист № докум. Подп. Дата Лист

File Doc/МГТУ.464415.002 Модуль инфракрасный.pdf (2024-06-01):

Формат
Кол.
А3 | | МГТУ.464415.002 СБ | Чертёж сборочный
* | | МГТУ.713621.001 МД | Модель детали электронная | | *)CD
| * | | | МГТУ.731146.001-01 МД | Модель детали электронная | *)CD
| * | | | МГТУ.741316.001 МД | Модель детали электронная | *)CD
А4 | 1 | МГТУ.713621.001 | Кнопка | 1
А3 | 2 | МГТУ.731146.001-01 | Корпус | 1
А4 | 3 | МГТУ.741316.001 | Крышка задвижная | 1
4 | Винт с цилиндрической головкой | 4
| и шестигранным углублением
| под ключ
| | | ГОСТ Р ИСО 4762-2012-М2х5
| 5 | | Винт с цилиндрической головкой | 4
| | | и шестигранным углублением
| | | под ключ
| | | ГОСТ Р ИСО 4762-2012-М3х5
Изм. | Лист | № докум. | Подп. | Дата
| | Разраб. | | | Спецификация | Лит. | Лист | Листов
Пров. | | | | | | | | 3

# МГТУ.464415.002

Подп. и дата Взам. инв. №

Инв. № подл.
МГТУ им Н.Э. Баумана
кафедра РЛ1

Н. контр.
Утв. | Круглов

### 1 Модуль инфракрасный

Инв. № дубл. Подп. дата

Документация

Зона
Обозначение

Наименование

Примечание

Стандартные изделия

| Детали

Краснинский Поз.

Перв. примен.

МГТУ.403443.001

Справ. №

Копировал

Формат А4

Прочие изделия

6 | Вставка резьбовая | 4
| термоустановочная М2хL3xOD3
7 | Вставка резьбовая | 4
| термоустановочная М3хL3xOD4
8 | Контакт отрицательный для | 3
| батареи типа АА
9 | Контакт положительный для | 3
| батареи типа АА
10 | Розетка на кабель HU-2 | 1
| Connfly
11 | Провод гибкий 24AWG (0,2 мм кв) | 1 | 100мм
| красный ГОСТ 22483-2012
12 | Провод гибкий 24AWG (0,2 мм кв) | 1 | 100мм
| чёрный ГОСТ 22483-2012
Переменные данные | для исполнений
| | МГТУ.463415.002-00

Документация

* | Модель детали электронная
| Сборочные единицы
А3 | 13 | МГТУ.469335.001-01 | Узел печатный | 1
| | | | МГТУ.463415.002 | Лист 2
Подп. | Дата
Копировал

Приме-

Формат А4

*)CD

№ докум.

Обозначение

Материалы

Поз.

Инв. № подл.

# Изм. Лист Зона

Подп. и дата Взам. инв. № Инв. № дубл. Подп. дата

МГТУ.741344.001-01 МД

Детали

А3 | Крышка | 1
| МГТУ.463415.002-01
| Документация
* | Модель детали электронная
| Сборочные единицы
А3 | Узел печатный | 1
| Детали
А3 | Крышка | 1
Лист | № докум. | Подп. | Дата
Копировал | Формат А4
МГТУ.463415.002 | Лист 3 Изм.

Взам. инв. № Подп. и дата Инв. № подл.

Инв. № дубл. Подп. дата
14 | МГТУ.741344.001-02
13 | МГТУ.469335.001-02
МГТУ.741344.001-02 МД | *)CD

Зона
Поз.
Обозначение | Приме-
14 | МГТУ.741344.001-01

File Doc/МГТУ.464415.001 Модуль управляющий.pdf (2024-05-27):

Формат
Кол.
А3 | | МГТУ.464415.001 СБ | Чертёж сборочный
* | | МГТУ.731146.001-00 МД | Модель детали электронная | | *)CD
| * | | | МГТУ.741344.001-00 МД | Модель детали электронная | *)CD
А3 | 1
А3 | 2 | МГТУ.731146.001-00 | Корпус | 1
А3 | 3 | МГТУ.741344.001-00 | Крышка | 1
4 | Винт с цилиндрической головкой | 4
| | | и шестигранным углублением
| | | под ключ
| | | ГОСТ Р ИСО 4762-2012-М2х5
| 5 | | Винт с цилиндрической головкой | 4
| | | и шестигранным углублением
| | | под ключ
| | | ГОСТ Р ИСО 4762-2012-М3х5
Изм. | Лист | № докум. | Подп. | Дата
| | Разраб. | Краснинский | | Спецификация | Лит. | Лист | Листов
Пров. | | | | | | | | 2

Перв. примен.

МГТУ.403443.001

Справ. №

Копировал
Формат А4

Примечание

Зона
Обозначение

Наименование

Документация

Узел печатный

Детали

Сборочные единицы

Поз.

МГТУ.469335.001-00

Инв. № дубл. Подп. дата

1

Инв. № подл.
МГТУ им Н.Э. Баумана
кафедра РЛ1

Н. контр.
Утв. | Круглов

### 1 Модуль управляющий

Подп. и дата Взам. инв. №

# МГТУ.464415.001

Стандартные изделия

Формат
Наименование

Кол.

Прочие изделия

6 | Вставка резьбовая | 4
| термоустановочная М2хL3xOD3
7 | Вставка резьбовая | 4
| термоустановочная М3хL3xOD4
Подп. | Дата
Копировал

Зона

Подп. и дата Взам. инв. № Инв. № дубл. Подп. дата Инв. № подл.

Изм. Лист

Поз.
Обозначение

Формат А4

№ докум.

# МГТУ.464415.001 2

Примечание

Лист

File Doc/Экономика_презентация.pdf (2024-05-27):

Прямые материальные расходы 1%

Расходы на оплату труда
50% Расходы на страховые
взносы
13%

Расходы на аренду
11%

Накладные расходы
23%

Расходы на использование оборудования 2%

Н. Контр. Н. Контр. Н. Контр.
Утвердил Утвердил Утвердил | Круглов Г.В.

Инв. № подл. Подп. И дата Взам. инв.

№ Инв. № дубл. Справочный

№ Перв. примен.

Инв. № подл. Подп. И дата Взам. инв.

№ Инв. № дубл. Справочный

№ Перв. примен. Подп. И дата

Инв. № подл. Подп. И дата Взам. инв.

№ Инв. № дубл. Справочный

№ Перв. примен. Подп. И дата

4 мар 11 мар 18 мар 25 мар 1 апр 8 апр 15 апр 22 апр 29 апр 6 май 13 май 20 май 27 май

1.1
1.2
2.1
2.2
2.3
2.4

Номер этапа согласно

# 2.5 таблице ¹

Ленточный план-график выполнения НИОКР

| | | Таблица 1 – Последовательность выполнения НИОКР
№ этапа | Содержание этапа работ | Исполнитель | Дата начала этапа | Длительность этапа
1 | НИР | 04.03.24 | 28% | 136 ч.
1.1 | Разработка технического задания | Инженер-конструктор | 04.03.24 | 2% | 8
1.2 | Теоретические исследования | Инженер-конструктор | 05.03.2024 | 26% | 128
2 | ОКР | | 28.03.2024 | 72% | 344 ч.
2.1 | Разработка конструкторской документации | Инженер-конструктор | 28.03.2024 | 12% | 56
2.2 | Разработка программного обеспечения | Инженер-программист | 08.04.2024 | 17% | 80
2.3 | Изготовление опытного образца | Монтажник РЭА | 22.04.2024 | 8% | 40
2.4 | Испытания опытного образца | Инженер-конструктор | 27.04.2024 | 10% | 48
2.5 | Оформление расчётно-пояснительной записки | Инженер-конструктор | 13.05.2024 | 25% | 120
Итого | | | | 100% | 480 ч.

Таблица 2 – Смета затрат на выполнение НИОКР

Статья расходов | Затраты на реализацию НИР, руб. | Затраты на реализацию ОКР, руб.
Прямые материальные расходы | 1 970 | 6 909
Расходы на оплату труда | 87 296 | 246 488
Расходы на страховые взносы | 24 423 | 66 033
Расходы на аренду | 20 250 | 54 750
Накладные расходы | 39 680 | 112 404
Расходы на использование оборудования | 3 861 | 10 439
Итого | 177 480 | 497 023
| | | | Организационно-экономическая часть
| | | | Система электронного хронометража | Лит. Лит. Лит. | Масса Масса Масса | Масштаб Масштаб Масштаб
Изм Изм Изм | Лист Лист Лист | № докум. № докум. № докум. | Подпись Дата Подпись Дата Подпись Дата
Разраб. Разраб. Разраб. | | Краснинский К.А.
Проверил Проверил Проверил | | Сажин Ю.Б.
Т. Контр. Т. Контр. Т. Контр. | | | | Лист Лист Лист | Листов Листов Листов
| | | | МГТУ им. Н.Э. Баумана кафедра РЛ1

Сроки выполнения НИОКР: 04.03.2024г. – 11.06.2024г. или 60 рабочих дней, 480 рабочих часов при 40-дневной рабочей неделе.
Исполнители НИОКР: Инженер-конструктор, инженер-программист и монтажник РЭА.

Расходы на проведение НИОКР: 674 503 руб.
Цена проведения НИОКР: 773 908 руб.
Себестоимость производства опытного образца: 19 619 руб.

Применимость устройства: использование в качестве замены импортному оборудованию при проведении соревнований и сдаче нормативов по беговым дисциплинам лёгкой атлетики, при проведении конных соревнований.
Заказчик: конно-спортивный клуб «Созвездие»

Диаграмма расходов

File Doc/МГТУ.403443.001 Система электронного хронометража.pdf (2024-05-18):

Формат
Кол.
А3 | МГТУ.403443.001 Э1 | Схема электрическая
| | структурная
А3 | 1 | МГТУ.464415.001 | Модуль управляющий | 1
А3 | Краснинский Поз. 2 | МГТУ.464415.002-00 | Модуль инфракрасный | 1
А3 | 3 | МГТУ.464415.002-01 | Модуль инфракрасный | 1
Изм. | Лист | № докум. | Подп. | Дата
| | Разраб. | | | Система электронного хронометража Спецификация | Лит. | Лист | Листов
Пров. | | | | | | | 1 | 1

# МГТУ.403443.001

Подп. и дата

Взам. инв. №

Инв. № подл.
МГТУ им Н.Э. Баумана
кафедра РЛ1

Н. контр.
Утв. | Круглов

Инв. № дубл. Подп. дата

Документация

Зона
Обозначение | Наименование

Сборочные единицы

Примечание

Перв. примен. Справ. №

Копировал

Формат А4

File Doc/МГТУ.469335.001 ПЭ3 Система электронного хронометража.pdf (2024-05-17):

Изм. Лист | № докум. | Подп. | Дата
| Разраб. | Краснинский | | Система электронного хронометража Перечень элементов | Лит. | Лист | Листов
Пров. | | | | | | 1 | 5

Подп. и дата Взам. инв. №

Формат А4

Инв. № подл.

МГТУ им Н.Э. Баумана
кафедра РЛ1

Н. контр.
Утв. | Круглов
Копировал

1

HL1 SMD05050C6

# МГТУ.469335.001 ПЭ3

Поз. | Наименование

Светодиоды

C1-C5 | К10-90-1608-10В-100нФ+-10%-Н30 | 5 | Кулон
C8-C15 | К10-90-1608-10В-100нФ+-10%-Н30 | 8 | Кулон
| | C16-C18 | К10-90-1608-10В-10мкФ+-10%-Н30 | 3 | Кулон
| | C19 | К10-90-1608-50В-100пФ+-5%-МП0 | 1 | Кулон
| | | ШУКР.673511.002 ТУ
| | C20* | 04025U5R6CAT2A 5,6пФ+-0,25пФ 50В NP0 | 1 | AVX
| | C21* | 04025U1CAT2A 1пФ+-0,25пФ 50В NP0 | 1 | AVX
| | C23-C26 | 06032U18CAT2A 18пФ+-0,25пФ 200В NP0 | 4 | AVX
Кол. | Примечание

Микросхемы

Инв. № дубл. Подп. дата

МГТУ.469335.001
Перв. примен. Справ. №

Предохранители

DA2 | MCP1700T-3300E/TT | 1 | Microchip
DD1 | STM32F072RBT6 | 1 | STM

Конденсаторы

1

HA1 | HC0905A | | JL World
F1 | MF-MSMF050 0,5А 1812 | 1 | Bourns
| Приборы звуковой сигнализации

Изм. Лист | Подп. | Дата
L1* | КИК 1005-1,2 нГн +-5% О-Л | 1 | Эркон
| РКМУ.671340.002 ТУ
L2,L3 | BLM18AG102SN1D, 0603 | 2 | Murata
Поз. | Наименование | Кол. | Примечание
| Катушки индуктивности

Резисторы

R1,R2 | Р1-8В-0,1-5,1 кОм+-10% Л-П-М | 2 | Эркон
R3 | Р1-8В-0,1-10 кОм+-10% Л-П-М | 1 | Эркон
R6,R7 | Р1-8В-0,1-100 кОм+-10% Л-П-М | 2 | Эркон
R9-R14 | Р1-8В-0,1-1 кОм+-10% Л-П-М | 6 | Эркон
| ОЖО.467.164 ТУ

Выключатели кнопочные

Подп. дата

SB2 | KLS7-TS6601-5.0-180 | 1 | KLS Electronics

Инв. № дубл.

U1 | RFM95W 868МГц | 1 | Hope RF

Модуляторы

Диоды

Взам. инв. №
VD1 | USBLC6-2SC6 | 1 | STM
VD2 | BAT760 | 1 | NXP
VT1, VT3 | SI2302A | 2 | UMV

Подп. и дата

Транзисторы

Копировал | Формат А4
№ докум. | 2

Инв. № подл.

# МГТУ.469335.001 ПЭ3 Лист

Инв. № дубл. Подп. дата

R17 | Р1-8В-0,1-0 Ом+-10% Л-П-М | 1 | Эркон
| ОЖО.467.164 ТУ

Резонаторы кварцевые

Розетки

Ruichi

BL1 | SFH213FA | 1 | Osram
BL2 | TSOP4836 | 1 | Vishay

№ докум.

ZQ1 | 12MHz SMD03225C4 | 1
ZQ2 | 32.768kHz SMD03215C2 | 1

Вилки

XS1 | USB Type-C 213716-0001 16pin | 1

Переменные данные для исполнений МГТУ.464415.001-00

Резисторы

Формат А4

3

Копировал

XP1 | PLS-2R тип D | 1 | Connfly
XP2 | PLS-6R тип D | 1 | Connfly

Лист

Инв. № подл. Взам. инв. №

Фотоэлементы

МГТУ.464415.001-01

Подп. и дата

# МГТУ.469335.001 ПЭ3

Конденсаторы

C6,C7 | К10-90-1608-10В-100нФ+-10%-Н30 | 2 | Кулон
C22 | К10-90-1608-6,3В-680пФ+-10%-Н30 | 1 | Кулон
| ШУКР.673511.002 ТУ
C27* | 04025U1CAT2A 1пФ+-0,25пФ 50В NP0 | 1 | AVX
DA1 | MCP6001RT-I/OT | 1 | Microchip

Микросхемы

R4,R5 | Р1-8В-0,1-100 кОм+-10% Л-П-М | 2 | Эркон
R8 | Р1-8В-0,1-1 кОм+-10% Л-П-М | 1 | Эркон
R15 | Р1-8В-0,1-100 Ом+-10% Л-П-М | 1 | Эркон
| ОЖО.467.164 ТУ

Резисторы

Подп. дата

Инв. № дубл.
SB1 | KLS7-P8.5x8.5-1 | 1 | KLS Electronics
| Выключатели кнопочные
VD3 | ESDA5V3L | 1 | STM

Взам. инв. №

Диоды

Подп. и дата

Инв. № подл.

МГТУ.464415.001-02

R16 | Р1-8В-0,1-10 Ом+-10% Л-П-М | 1 | Эркон
| ОЖО.467.164 ТУ

Резисторы

SB1 | KLS7-P8.5x8.5-1 | 1 | KLS Electronics
| Выключатели кнопочные
| Диоды
VD3 | ESDA5V3L | 1 | STM
VD4 | TSAL6200 | 1 | Vishay

Подп. дата

Транзисторы

Инв. № дубл.

VT2 | SI2302A | 1 | UMV

Взам. инв. № Подп. и дата

Инв. № подл.

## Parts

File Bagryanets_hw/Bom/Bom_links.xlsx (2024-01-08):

Обозначение | Наименование | Примечание | На плате | Всего | Заказ | Цена | Стоимость | Ссылка
Количество плат: |  | 5
C11, C12 | Настройка | 0402 - не паять | 0 | 0 |  |  | 0.00
C45, C46 | Настройка | 0402 - не паять | 0 | 0 |  |  | 0.00
C35 | 1.5 пФ | 0402 | 1 | 5 | 10 | 7.00 | 70.00 | https://www.chipdip.ru/product/grm1535c1h1r5c
C41 | 1.8 пФ | 0402 | 1 | 5 | 10 | 5.00 | 50.00 | https://www.chipdip.ru/product/grm1535c1h1r8c
C37 | 3 пФ | 0402 | 1 | 5 |  |  | 0.00
C40 | 4.7 пФ | 0402 | 1 | 5 |  |  | 0.00
C38 | 6.2 пФ | 0402 | 1 | 5 |  |  | 0.00
C19, C24, C9, C14 | 8.2 пФ | 0402 | 4 | 20 |  |  | 0.00
C18, C23 | 9.1 пФ | 0402 | 2 | 10 |  |  | 0.00
C36 | 33 пФ | 0402 | 1 | 5 | 10 | 7.00 | 70.00 | https://www.chipdip.ru/product/grm1535c1h330j
C39 | 39 пФ | 0402 | 1 | 5 | 10 | 7.00 | 70.00 | https://www.chipdip.ru/product/grm1535c1h390j
C33 | 47 пФ | 0402 | 1 | 5 | 10 | 7.00 | 70.00 | https://www.chipdip.ru/product/grm1535c1h470j
C44 | 100 пФ | 0402 | 1 | 5 | 10 | 7.00 | 70.00 | https://www.chipdip.ru/product/grm1555c1h101ja01d
C15, C16 | 680 пФ | 0402 | 2 | 10 | 20 | 7.00 | 140.00 | https://www.chipdip.ru/product/grm1535c1h681j
C42, C43 | 1 нФ | 0402 | 2 | 10 | 20 | 7.00 | 140.00 | https://www.chipdip.ru/product/grm1555c1h102j
C29, C34 | 10 нФ | 0402 | 2 | 10 | 20 | 6.00 | 120.00 | https://www.chipdip.ru/product/grm155r71c103ka01d
C1, C2, C3, C5, C6, C8, C10, C13, C17, C20, C22, C25, C26, C28, C30, C31, C32 | 100 нФ | 0402 | 17 | 85 | 100 | 0.60 | 60.00 | https://www.chipdip.ru/product0/8016016068
C4, C7, C21, C27 | 10 мкФ | 0603 | 4 | 20 | 50 | 3 | 150.00 | https://www.chipdip.ru/product0/8016016313
R4, R5 | 0 Ом | 0402 - не паять | 0 | 0 |  |  | 0.00
R18 | 10 Ом | 0402 - исправить в новой версии | 1 | 5 | 20 | 6.00 | 120.00 | https://www.chipdip.ru/product/0.062w-0402-10-om-5
R22 | 510 Ом | 0402 - исправить в новой версии | 1 | 5 | 20 | 6.00 | 120.00 | https://www.chipdip.ru/product/0.062w-0402-510-om-5
R17 | 1 кОм | 0402 | 1 | 5 | 20 | 6.00 | 120.00 | https://www.chipdip.ru/product/0.062w-0402-1-kom-1
R12, R13, R14, R15, R19, R20, R21 | 1 кОм | 0603 | 7 | 35 | 60 | 6.00 | 360.00 | https://www.chipdip.ru/product/0.1w-0603-1-kom-5
R2, R3 | 5.1 кОм | 0603 | 2 | 10 | 40 | 6.00 | 240.00 | https://www.chipdip.ru/product/0.1w-0603-5.1-kom-5
R1 | 10 кОм | 0603 | 1 | 5 | 40 | 6.00 | 240.00 | https://www.chipdip.ru/product/0.1w-0603-10-kom-5
R16 | 10 кОм | 0603 - не паять | 0 | 0 |  |  | 0.00
R6, R7, R8, R9, R10, R11 | 100 кОм | 0603 | 6 | 30 | 40 | 6.00 | 240.00 | https://www.chipdip.ru/product/0.1w-0603-100-kom-5
F1 | 500 мА | 1812 - предохранитель | 1 | 5 | 5 | 44.00 | 220.00 | https://www.chipdip.ru/product/mf-msmf050
L8 | Настройка | 0402 - не паять | 0 | 0 |  |  | 0.00
L7 | 7.5 нГн | 0402 | 1 | 5 | 10 | 7.00 | 70.00 | https://www.chipdip.ru/product/lqg15hn7n5j
L6 | 8.2 нГн | 0402 | 1 | 5 | 10 | 3.00 | 30.00 | https://www.chipdip.ru/product/lqg15hn8n2j02d
L4 | 9.1 нГн | 0402 | 1 | 5 | 10 | 3.00 | 30.00 | https://www.chipdip.ru/product/lqg15hn9n1j02d
L5 | 12 нГн | 0402 | 1 | 5 | 10 | 8.00 | 80.00 | https://www.chipdip.ru/product/lqg15hn12nj
L3 | 33 нГн | 0402 | 1 | 5 | 10 | 22.00 | 220.00 | https://www.chipdip.ru/product/lqg15hn33nj
L1, L2 | 10 мкГн | 0805 | 2 | 10 | 10 | 15.00 | 150.00 | https://www.chipdip.ru/product/lqm21fn100n
VD1 | PMEG3010BEA | SOD323 диод Шоттки | 1 | 5 | 10 | 9.00 | 90.00 | https://www.chipdip.ru/product/bat760-slkor
VD2 | USBLC6-2SC6 | SOT23-6 | 1 | 5 | 10 | 10.00 | 100.00 | https://www.chipdip.ru/product/usblc6-2sc6-umw
VD3 | ESDA5V3L | SOT-23 | 1 | 5 | 5 | 22.00 | 110.00 | https://www.chipdip.ru/product/esda5v3l-2
VD4 | TSAL6200 | 5 мм - ИК светодиод | 1 | 5 |  |  | 0.00 | В наличии 50 шт
VD4, VD5 | SFH213 | 5мм - ИК фотодиод | 2 | 10 |  |  | 0.00 | В наличии 50 шт
VD6 |  | 5050 - RGB LED | 1 | 5 |  |  | 0.00 | KL
VT1, VT2, VT3 | SI2302 | SOT23-3 - MOSFET, управление логическим уровнем I>500мА | 3 | 15 | 20 | 4.00 | 80.00 | https://www.chipdip.ru/product/si2302a
U1 | SX1276 | QFN28 - LoRa | 1 | 5 |  |  | 0.00 | KL
DA1 | MCP-1700-3302 | SOT23-3 - Линейный стабилизатор 3.3 В | 1 | 5 |  |  | 0.00 | В наличии 5 шт/KL
DA2, DA3 | LMV721 | SOT23-5 - ОУ Rail-to-rail | 2 | 10 | 10 | 48.00 | 480.00 | https://www.chipdip.ru/product/lmv721m5x-p
DA4 | PE4259 | SC70 - ВЧ переключатель | 1 | 5 |  |  | 0.00 | https://aliexpress.ru/item/32967855337.html
DD1 | STM32F072R8T6 | LQFP64 - Микроконтроллер | 1 | 5 |  |  | 0.00 | KL
ZQ1 | 32 МГц | 03225C4 | 1 | 5 | 10 | 20.00 | 200.00 | https://www.chipdip.ru/product0/8010532100
ZQ2 | 32.768 кГц | 03215 | 1 | 5 | 2 | 98.00 | 196.00 | https://www.chipdip.ru/product/32.768-khz-smd-3.2mmx1.5mm
ZQ3 | 24 МГц | 03225C4 | 1 | 5 | 5 | 15.00 | 75.00 | https://www.chipdip.ru/product0/9001130951
SB1 | KLS7 | 8.5х8.5 мм - Кнопка с фиксацией | 1 | 5 | 5 | 21.00 | 105.00 | https://www.chipdip.ru/product/ps850l-pb22e09
SB2 |  | 6мм - тактовая кнопка | 1 | 5 | 10 | 9.00 | 90.00 | https://www.chipdip.ru/product/kls7-ts6601-5.0-180
HA1 | HC0903A | 9.5 мм - Спикер без генератора | 1 | 5 | 5 | 44.00 | 220.00 | https://www.promelec.ru/product/325804/
XS1 | USB-C 10PF-074 | USB-C 10PF-074 - 16 контактный USB-C | 1 | 5 |  |  | 0.00 | KL
XP1 | PLS-6 | PLS-6 |  | 0 |  |  | 0.00 | В наличии
XP2 | PLS-2 | PLS-2 |  | 0 |  |  | 0.00 | В наличии
Итог: |  |  |  |  |  |  | 4996.00

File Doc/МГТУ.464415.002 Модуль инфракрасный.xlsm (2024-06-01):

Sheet: С Л1
Перв. примен. | МГТУ.403443.001 | Формат | Зона |  | Поз. |  | Обозначение |  |  |  | Наименование |  |  | Кол. | Приме- чание
 |  |  |  |  |  |  |  |  |  |  | Документация
 |  | А3 |  |  |  |  | МГТУ.464415.002 СБ |  |  |  | Чертёж сборочный
 |  | * |  |  |  |  | МГТУ.713621.001 МД |  |  |  | Модель детали электронная |  |  |  | *)CD
Справ. № |  | * |  |  |  |  | МГТУ.731146.001-01 МД |  |  |  | Модель детали электронная |  |  |  | *)CD
 |  | * |  |  |  |  | МГТУ.741316.001 МД |  |  |  | Модель детали электронная |  |  |  | *)CD
 |  |  |  |  |  |  |  |  |  |  | Детали
 |  | А4 |  |  | 1 |  | МГТУ.713621.001 |  |  |  | Кнопка |  |  | 1
 |  | А3 |  |  | 2 |  | МГТУ.731146.001-01 |  |  |  | Корпус |  |  | 1
 |  | А4 |  |  | 3 |  | МГТУ.741316.001 |  |  |  | Крышка задвижная |  |  | 1
 |  |  |  |  |  |  |  |  |  |  | Стандартные изделия
Подп. дата
 |  |  |  |  | 4 |  |  |  |  |  | Винт с цилиндрической головкой |  |  | 4
 |  |  |  |  |  |  |  |  |  |  | и шестигранным углублением
 |  |  |  |  |  |  |  |  |  |  | под ключ
Инв. № дубл. |  |  |  |  |  |  |  |  |  |  | ГОСТ Р ИСО 4762-2012-М2х5
 |  |  |  |  | 5 |  |  |  |  |  | Винт с цилиндрической головкой |  |  | 4
 |  |  |  |  |  |  |  |  |  |  | и шестигранным углублением
 |  |  |  |  |  |  |  |  |  |  | под ключ
Взам. инв. №
 |  |  |  |  |  |  |  |  |  |  | ГОСТ Р ИСО 4762-2012-М3х5
Подп. и дата
 |  |  |  |  |  |  |  |  |  | МГТУ.464415.002
 |  | Изм. |  | Лист |  | № докум. |  | Подп. | Дата
Инв. № подл. |  | Разраб. |  |  |  | Краснинский |  |  |  | Модуль инфракрасный |  | Лит. | Лист |  |  | Листов
 |  | Пров. |  |  |  |  |  |  |  |  |  |  | 1 |  |  | 3
 |  |  |  |  |  |  |  |  |  |  |  | МГТУ им Н.Э. Баумана кафедра РЛ1
 |  | Н. контр.
 |  | Утв. |  |  |  | Круглов |  |  |  | Спецификация
 |  |  |  |  |  |  |  |  |  | Копировал |  | Формат А4

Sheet: С Л2
 | Формат | Зона |  | Поз. |  | Обозначение |  |  |  | Наименование | Кол. | Приме- чание
 |  |  |  |  |  |  |  |  |  | Прочие изделия
 |  |  |  | 6 |  |  |  |  |  | Вставка резьбовая | 4
 |  |  |  |  |  |  |  |  |  | термоустановочная М2хL3xOD3
 |  |  |  | 7 |  |  |  |  |  | Вставка резьбовая | 4
 |  |  |  |  |  |  |  |  |  | термоустановочная М3хL3xOD4
 |  |  |  | 8 |  |  |  |  |  | Контакт отрицательный для | 3
 |  |  |  |  |  |  |  |  |  | батареи типа АА
 |  |  |  | 9 |  |  |  |  |  | Контакт положительный для | 3
 |  |  |  |  |  |  |  |  |  | батареи типа АА
 |  |  |  | 10 |  |  |  |  |  | Розетка на кабель HU-2 | 1
 |  |  |  |  |  |  |  |  |  | Connfly
 |  |  |  |  |  |  |  |  |  | Материалы
Подп. дата
 |  |  |  | 11 |  |  |  |  |  | Провод гибкий 24AWG (0,2 мм кв) | 1 | 100мм
 |  |  |  |  |  |  |  |  |  | красный ГОСТ 22483-2012
 |  |  |  | 12 |  |  |  |  |  | Провод гибкий 24AWG (0,2 мм кв) | 1 | 100мм
Инв. № дубл.
 |  |  |  |  |  |  |  |  |  | чёрный ГОСТ 22483-2012
 |  |  |  |  |  | Переменные данные |  |  |  | для исполнений
Взам. инв. № |  |  |  |  |  |  |  |  |  | МГТУ.463415.002-00
 |  |  |  |  |  |  |  |  |  | Документация
Подп. и дата
 | * |  |  |  |  | МГТУ.741344.001-01 МД |  |  |  | Модель детали электронная |  | *)CD
 |  |  |  |  |  |  |  |  |  | Сборочные единицы
Инв. № подл.
 | А3 |  |  | 13 |  | МГТУ.469335.001-01 |  |  |  | Узел печатный | 1
 |  |  |  |  |  |  |  |  | МГТУ.463415.002 |  |  |  | Лист
 |  |  |  |  |  |  |  |  |  |  |  |  | 2
 | Изм. |  | Лист |  | № докум. |  | Подп. | Дата
 |  |  |  |  |  |  |  |  | Копировал | Формат А4

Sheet: С Л3
 | Формат | Зона |  | Поз. |  | Обозначение |  |  |  | Наименование | Кол. | Приме- чание
 |  |  |  |  |  |  |  |  |  | Детали
 | А3 |  |  | 14 |  | МГТУ.741344.001-01 |  |  |  | Крышка | 1
 |  |  |  |  |  |  |  |  |  | МГТУ.463415.002-01
 |  |  |  |  |  |  |  |  |  | Документация
 | * |  |  |  |  | МГТУ.741344.001-02 МД |  |  |  | Модель детали электронная |  | *)CD
 |  |  |  |  |  |  |  |  |  | Сборочные единицы
 | А3 |  |  | 13 |  | МГТУ.469335.001-02 |  |  |  | Узел печатный | 1
Подп. дата
 |  |  |  |  |  |  |  |  |  | Детали
 | А3 |  |  | 14 |  | МГТУ.741344.001-02 |  |  |  | Крышка | 1
Инв. № дубл.
Взам. инв. №
Подп. и дата
Инв. № подл.
 |  |  |  |  |  |  |  |  | МГТУ.463415.002 |  |  |  | Лист
 |  |  |  |  |  |  |  |  |  |  |  |  | 3
 | Изм. |  | Лист |  | № докум. |  | Подп. | Дата
 |  |  |  |  |  |  |  |  | Копировал | Формат А4

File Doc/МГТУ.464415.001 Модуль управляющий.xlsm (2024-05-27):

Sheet: С Л1
Перв. примен. | МГТУ.403443.001 | Формат | Зона |  | Поз. |  | Обозначение |  |  |  | Наименование |  |  | Кол. | Приме- чание
 |  |  |  |  |  |  |  |  |  |  | Документация
 |  | А3 |  |  |  |  | МГТУ.464415.001 СБ |  |  |  | Чертёж сборочный
 |  | * |  |  |  |  | МГТУ.731146.001-00 МД |  |  |  | Модель детали электронная |  |  |  | *)CD
Справ. № |  | * |  |  |  |  | МГТУ.741344.001-00 МД |  |  |  | Модель детали электронная |  |  |  | *)CD
 |  |  |  |  |  |  |  |  |  |  | Сборочные единицы
 |  | А3 |  |  | 1 |  | МГТУ.469335.001-00 |  |  |  | Узел печатный |  |  | 1
 |  |  |  |  |  |  |  |  |  |  | Детали
 |  | А3 |  |  | 2 |  | МГТУ.731146.001-00 |  |  |  | Корпус |  |  | 1
 |  | А3 |  |  | 3 |  | МГТУ.741344.001-00 |  |  |  | Крышка |  |  | 1
Подп. дата
 |  |  |  |  |  |  |  |  |  |  | Стандартные изделия
 |  |  |  |  | 4 |  |  |  |  |  | Винт с цилиндрической головкой |  |  | 4
Инв. № дубл. |  |  |  |  |  |  |  |  |  |  | и шестигранным углублением
 |  |  |  |  |  |  |  |  |  |  | под ключ
 |  |  |  |  |  |  |  |  |  |  | ГОСТ Р ИСО 4762-2012-М2х5
 |  |  |  |  | 5 |  |  |  |  |  | Винт с цилиндрической головкой |  |  | 4
Взам. инв. №
 |  |  |  |  |  |  |  |  |  |  | и шестигранным углублением
 |  |  |  |  |  |  |  |  |  |  | под ключ
 |  |  |  |  |  |  |  |  |  |  | ГОСТ Р ИСО 4762-2012-М3х5
Подп. и дата
 |  |  |  |  |  |  |  |  |  | МГТУ.464415.001
 |  | Изм. |  | Лист |  | № докум. |  | Подп. | Дата
Инв. № подл. |  | Разраб. |  |  |  | Краснинский |  |  |  | Модуль управляющий |  | Лит. | Лист |  |  | Листов
 |  | Пров. |  |  |  |  |  |  |  |  |  |  | 1 |  |  | 2
 |  |  |  |  |  |  |  |  |  |  |  | МГТУ им Н.Э. Баумана кафедра РЛ1
 |  | Н. контр.
 |  | Утв. |  |  |  | Круглов |  |  |  | Спецификация
 |  |  |  |  |  |  |  |  |  | Копировал |  | Формат А4

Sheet: С Л2
 | Формат | Зона |  | Поз. |  | Обозначение |  |  |  | Наименование | Кол. | Приме- чание
 |  |  |  |  |  |  |  |  |  | Прочие изделия
 |  |  |  | 6 |  |  |  |  |  | Вставка резьбовая | 4
 |  |  |  |  |  |  |  |  |  | термоустановочная М2хL3xOD3
 |  |  |  | 7 |  |  |  |  |  | Вставка резьбовая | 4
 |  |  |  |  |  |  |  |  |  | термоустановочная М3хL3xOD4
Подп. дата
Инв. № дубл.
Взам. инв. №
Подп. и дата
Инв. № подл.
 |  |  |  |  |  |  |  |  | МГТУ.464415.001 |  |  |  | Лист
 |  |  |  |  |  |  |  |  |  |  |  |  | 2
 | Изм. |  | Лист |  | № докум. |  | Подп. | Дата
 |  |  |  |  |  |  |  |  | Копировал | Формат А4

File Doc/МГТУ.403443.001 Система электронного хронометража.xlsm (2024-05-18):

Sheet: С Л1
Перв. примен. | Формат | Зона |  | Поз. |  | Обозначение |  |  |  | Наименование |  |  | Кол. | Приме- чание
 |  |  |  |  |  |  |  |  |  | Документация
 | А3 |  |  |  |  | МГТУ.403443.001 Э1 |  |  |  | Схема электрическая
 |  |  |  |  |  |  |  |  |  | структурная
Справ. №
 |  |  |  |  |  |  |  |  |  | Сборочные единицы
 | А3 |  |  | 1 |  | МГТУ.464415.001 |  |  |  | Модуль управляющий |  |  | 1
 | А3 |  |  | 2 |  | МГТУ.464415.002-00 |  |  |  | Модуль инфракрасный |  |  | 1
 | А3 |  |  | 3 |  | МГТУ.464415.002-01 |  |  |  | Модуль инфракрасный |  |  | 1
Подп. дата
Инв. № дубл.
Взам. инв. №
Подп. и дата
 |  |  |  |  |  |  |  |  | МГТУ.403443.001
 | Изм. |  | Лист |  | № докум. |  | Подп. | Дата
Инв. № подл. | Разраб. |  |  |  | Краснинский |  |  |  | Система электронного хронометража |  | Лит. | Лист |  |  | Листов
 | Пров. |  |  |  |  |  |  |  |  |  |  | 1 |  |  | 1
 |  |  |  |  |  |  |  |  |  |  | МГТУ им Н.Э. Баумана кафедра РЛ1
 | Н. контр.
 | Утв. |  |  |  | Круглов |  |  |  | Спецификация
 |  |  |  |  |  |  |  |  | Копировал |  | Формат А4

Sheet: С Л2
 | Формат | Зона |  | Поз. |  | Обозначение |  |  |  | Наименование | Кол. | Приме- чание
Подп. дата
Инв. № дубл.
Взам. инв. №
Подп. и дата
Инв. № подл.
 |  |  |  |  |  |  |  |  | МГТУ.403443.001 |  |  |  | Лист
 |  |  |  |  |  |  |  |  |  |  |  |  | 2
 | Изм. |  | Лист |  | № докум. |  | Подп. | Дата
 |  |  |  |  |  |  |  |  | Копировал | Формат А4

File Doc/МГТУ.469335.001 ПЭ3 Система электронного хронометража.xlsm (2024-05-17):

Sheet: ПЭ Л1
Перв. примен. | МГТУ.469335.001 | Поз. |  |  | Наименование |  |  |  | Кол. |  | Примечание
 |  |  |  |  | Конденсаторы
 |  | C1-C5 |  |  | К10-90-1608-10В-100нФ+-10%-Н30 |  |  |  | 5 |  | Кулон
 |  | C8-C15 |  |  | К10-90-1608-10В-100нФ+-10%-Н30 |  |  |  | 8 |  | Кулон
Справ. № |  | C16-C18 |  |  | К10-90-1608-10В-10мкФ+-10%-Н30 |  |  |  | 3 |  | Кулон
 |  | C19 |  |  | К10-90-1608-50В-100пФ+-5%-МП0 |  |  |  | 1 |  | Кулон
 |  |  |  |  | ШУКР.673511.002 ТУ
 |  | C20* |  |  | 04025U5R6CAT2A 5,6пФ+-0,25пФ 50В NP0 |  |  |  | 1 |  | AVX
 |  | C21* |  |  | 04025U1CAT2A 1пФ+-0,25пФ 50В NP0 |  |  |  | 1 |  | AVX
 |  | C23-C26 |  |  | 06032U18CAT2A 18пФ+-0,25пФ 200В NP0 |  |  |  | 4 |  | AVX
 |  |  |  |  | Микросхемы
 |  | DA2 |  |  | MCP1700T-3300E/TT |  |  |  | 1 |  | Microchip
 |  | DD1 |  |  | STM32F072RBT6 |  |  |  | 1 |  | STM
Подп. дата
 |  |  |  |  | Предохранители
 |  | F1 |  |  | MF-MSMF050 0,5А 1812 |  |  |  | 1 |  | Bourns
Инв. № дубл.
 |  |  |  |  | Приборы звуковой сигнализации
 |  | HA1 |  |  | HC0905A |  |  |  | 1 |  | JL World
Взам. инв. №
 |  |  |  |  | Светодиоды
Подп. и дата
 |  | HL1 |  |  | SMD05050C6 |  |  |  | 1
 |  |  |  |  |  |  |  | МГТУ.469335.001 ПЭ3
 |  | Изм. | Лист | № докум. |  | Подп. | Дата
Инв. № подл. |  | Разраб. |  | Краснинский |  |  |  | Система электронного хронометража |  | Лит. |  | Лист | Листов
 |  | Пров. |  |  |  |  |  |  |  |  |  | 1 | 5
 |  |  |  |  |  |  |  |  |  | МГТУ им Н.Э. Баумана кафедра РЛ1
 |  | Н. контр.
 |  | Утв. |  | Круглов |  |  |  | Перечень элементов
 |  |  |  |  |  |  |  | Копировал |  | Формат А4

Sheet: ПЭ Л2
 | Поз. |  |  | Наименование |  |  |  | Кол. |  | Примечание
 |  |  |  | Катушки индуктивности
 | L1* |  |  | КИК 1005-1,2 нГн +-5% О-Л |  |  |  | 1 |  | Эркон
 |  |  |  | РКМУ.671340.002 ТУ
 | L2,L3 |  |  | BLM18AG102SN1D, 0603 |  |  |  | 2 |  | Murata
 |  |  |  | Резисторы
 | R1,R2 |  |  | Р1-8В-0,1-5,1 кОм+-10% Л-П-М |  |  |  | 2 |  | Эркон
 | R3 |  |  | Р1-8В-0,1-10 кОм+-10% Л-П-М |  |  |  | 1 |  | Эркон
 | R6,R7 |  |  | Р1-8В-0,1-100 кОм+-10% Л-П-М |  |  |  | 2 |  | Эркон
 | R9-R14 |  |  | Р1-8В-0,1-1 кОм+-10% Л-П-М |  |  |  | 6 |  | Эркон
 |  |  |  | ОЖО.467.164 ТУ
 |  |  |  | Выключатели кнопочные
Подп. дата
 | SB2 |  |  | KLS7-TS6601-5.0-180 |  |  |  | 1 |  | KLS Electronics
 |  |  |  | Модуляторы
Инв. № дубл.
 | U1 |  |  | RFM95W 868МГц |  |  |  | 1 |  | Hope RF
 |  |  |  | Диоды
Взам. инв. №
 | VD1 |  |  | USBLC6-2SC6 |  |  |  | 1 |  | STM
 | VD2 |  |  | BAT760 |  |  |  | 1 |  | NXP
Подп. и дата
 |  |  |  | Транзисторы
 | VT1, VT3 |  |  | SI2302A |  |  |  | 2 |  | UMV
Инв. № подл.
 |  |  |  |  |  |  | МГТУ.469335.001 ПЭ3 |  |  |  | Лист
 |  |  |  |  |  |  |  |  |  |  | 2
 | Изм. | Лист | № докум. |  | Подп. | Дата
 |  |  |  |  |  |  | Копировал |  | Формат А4

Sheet: ПЭ Л3
 | Поз. |  |  | Наименование |  |  |  | Кол. |  | Примечание
 |  |  |  | Вилки
 | XP1 |  |  | PLS-2R тип D |  |  |  | 1 |  | Connfly
 | XP2 |  |  | PLS-6R тип D |  |  |  | 1 |  | Connfly
 |  |  |  | Розетки
 | XS1 |  |  | USB Type-C 213716-0001 16pin |  |  |  | 1 |  | Ruichi
 |  |  |  | Резонаторы кварцевые
 | ZQ1 |  |  | 12MHz SMD03225C4 |  |  |  | 1
 | ZQ2 |  |  | 32.768kHz SMD03215C2 |  |  |  | 1
 |  |  |  | Переменные данные для исполнений
Подп. дата
 |  |  |  | МГТУ.464415.001-00
 |  |  |  | Резисторы
Инв. № дубл.
 | R17 |  |  | Р1-8В-0,1-0 Ом+-10% Л-П-М |  |  |  | 1 |  | Эркон
 |  |  |  | ОЖО.467.164 ТУ
Взам. инв. № |  |  |  | МГТУ.464415.001-01
 |  |  |  | Фотоэлементы
Подп. и дата
 | BL1 |  |  | SFH213FA |  |  |  | 1 |  | Osram
 | BL2 |  |  | TSOP4836 |  |  |  | 1 |  | Vishay
Инв. № подл.
 |  |  |  |  |  |  | МГТУ.469335.001 ПЭ3 |  |  |  | Лист
 |  |  |  |  |  |  |  |  |  |  | 3
 | Изм. | Лист | № докум. |  | Подп. | Дата
 |  |  |  |  |  |  | Копировал |  | Формат А4

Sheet: ПЭ Л4
 | Поз. |  |  | Наименование |  |  |  | Кол. |  | Примечание
 |  |  |  | Конденсаторы
 | C6,C7 |  |  | К10-90-1608-10В-100нФ+-10%-Н30 |  |  |  | 2 |  | Кулон
 | C22 |  |  | К10-90-1608-6,3В-680пФ+-10%-Н30 |  |  |  | 1 |  | Кулон
 |  |  |  | ШУКР.673511.002 ТУ
 | C27* |  |  | 04025U1CAT2A 1пФ+-0,25пФ 50В NP0 |  |  |  | 1 |  | AVX
 |  |  |  | Микросхемы
 | DA1 |  |  | MCP6001RT-I/OT |  |  |  | 1 |  | Microchip
 |  |  |  | Резисторы
 | R4,R5 |  |  | Р1-8В-0,1-100 кОм+-10% Л-П-М |  |  |  | 2 |  | Эркон
 | R8 |  |  | Р1-8В-0,1-1 кОм+-10% Л-П-М |  |  |  | 1 |  | Эркон
Подп. дата
 | R15 |  |  | Р1-8В-0,1-100 Ом+-10% Л-П-М |  |  |  | 1 |  | Эркон
 |  |  |  | ОЖО.467.164 ТУ
 |  |  |  | Выключатели кнопочные
Инв. № дубл.
 | SB1 |  |  | KLS7-P8.5x8.5-1 |  |  |  | 1 |  | KLS Electronics
Взам. инв. № |  |  |  | Диоды
 | VD3 |  |  | ESDA5V3L |  |  |  | 1 |  | STM
Подп. и дата
Инв. № подл.
 |  |  |  |  |  |  | МГТУ.469335.001 ПЭ3 |  |  |  | Лист
 |  |  |  |  |  |  |  |  |  |  | 4
 | Изм. | Лист | № докум. |  | Подп. | Дата
 |  |  |  |  |  |  | Копировал |  | Формат А4

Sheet: ПЭ Л5
 | Поз. |  |  | Наименование |  |  |  | Кол. |  | Примечание
 |  |  |  | МГТУ.464415.001-02
 |  |  |  | Резисторы
 | R16 |  |  | Р1-8В-0,1-10 Ом+-10% Л-П-М |  |  |  | 1 |  | Эркон
 |  |  |  | ОЖО.467.164 ТУ
 |  |  |  | Выключатели кнопочные
 | SB1 |  |  | KLS7-P8.5x8.5-1 |  |  |  | 1 |  | KLS Electronics
 |  |  |  | Диоды
 | VD3 |  |  | ESDA5V3L |  |  |  | 1 |  | STM
 | VD4 |  |  | TSAL6200 |  |  |  | 1 |  | Vishay
Подп. дата
 |  |  |  | Транзисторы
 | VT2 |  |  | SI2302A |  |  |  | 1 |  | UMV
Инв. № дубл.
Взам. инв. №
Подп. и дата
Инв. № подл.
 |  |  |  |  |  |  | МГТУ.469335.001 ПЭ3 |  |  |  | Лист
 |  |  |  |  |  |  |  |  |  |  | 5
 | Изм. | Лист | № докум. |  | Подп. | Дата
 |  |  |  |  |  |  | Копировал |  | Формат А4

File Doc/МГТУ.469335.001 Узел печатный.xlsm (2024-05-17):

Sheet: С Л1
Перв. примен. | МГТУ.464415.001 | Формат | Зона |  | Поз. |  | Обозначение |  |  |  | Наименование |  |  | Кол. | Приме- чание
 |  |  |  |  |  |  |  |  |  |  | Документация
 |  | А3 |  |  |  |  | МГТУ.469335.001 СБ |  |  |  | Сборочный чертёж
 |  | А2 |  |  |  |  | МГТУ.469335.001 Э3 |  |  |  | Схема электрическая
Справ. № |  |  |  |  |  |  |  |  |  |  | принципиальная
 |  | А4 |  |  |  |  | МГТУ.469335.001 ПЭ3 |  |  |  | Перечень элементов
 |  | * |  |  |  |  | МГТУ.758741.001 ДЗЗ |  |  |  | Данные проектирования |  |  |  | *)CD
 |  |  |  |  |  |  |  |  |  |  | Детали
 |  | А3 |  |  | 1 |  | МГТУ.758741.001 |  |  |  | Плата печатная |  |  | 1
 |  |  |  |  |  |  |  |  |  |  | Прочие изделия
Подп. дата
 |  |  |  |  |  |  |  |  |  |  | Конденсаторы
 |  |  |  |  | 2 |  |  |  |  |  | 04025U1CAT2A |  |  | 1 | С21*
 |  |  |  |  |  |  |  |  |  |  | 1пФ+-0,25пФ 50В NP0
 |  |  |  |  | 3 |  |  |  |  |  | 04025U5R6CAT2A |  |  | 1 | С20*
Инв. № дубл. |  |  |  |  |  |  |  |  |  |  | 5,6пФ+-0,25пФ 50В NP0
 |  |  |  |  | 4 |  |  |  |  |  | 06032U18CAT2A |  |  | 4 | С23-С26
 |  |  |  |  |  |  |  |  |  |  | 18пФ+-0,25пФ 200В NP0
 |  |  |  |  |  |  |  |  |  |  | AVX Corporation
Взам. инв. №
 |  |  |  |  | 5 |  |  |  |  |  | К10-90-1608-50В-100пФ+-5%-МП0 |  |  | 1 | С19
 |  |  |  |  | 6 |  |  |  |  |  | К10-90-1608-10В-100нФ+-10%-Н30 |  |  | 13 | C1-C5,C8-C15
 |  |  |  |  | 7 |  |  |  |  |  | К10-90-1608-10В-10мкФ+-10%-Н30 |  |  | 3 | C16-C18
Подп. и дата
 |  |  |  |  |  |  |  |  |  |  | ШУКР.673511.002 ТУ
 |  |  |  |  |  |  |  |  |  | МГТУ.469335.001
 |  | Изм. |  | Лист |  | № докум. |  | Подп. | Дата
Инв. № подл. |  | Разраб. |  |  |  | Краснинский |  |  |  | Узел печатный |  | Лит. | Лист |  |  | Листов
 |  | Пров. |  |  |  |  |  |  |  |  |  |  | 1 |  |  | 5
 |  |  |  |  |  |  |  |  |  |  |  | МГТУ им Н.Э. Баумана кафедра РЛ1
 |  | Н. контр.
 |  | Утв. |  |  |  | Круглов |  |  |  | Спецификация
 |  |  |  |  |  |  |  |  |  | Копировал |  | Формат А4

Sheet: С Л2
 | Формат | Зона |  | Поз. |  | Обозначение |  |  |  | Наименование | Кол. | Приме- чание
 |  |  |  |  |  |  |  |  |  | Микросхемы
 |  |  |  | 8 |  |  |  |  |  | MCP1700T-3300E/TT | 1 | DA1
 |  |  |  |  |  |  |  |  |  | Microchip Technology
 |  |  |  | 9 |  |  |  |  |  | STM32F072RBT6 | 1 | DD1
 |  |  |  |  |  |  |  |  |  | STMicroelectronics
 |  |  |  |  |  |  |  |  |  | Предохранители
 |  |  |  | 10 |  |  |  |  |  | MF-MSMF050 0,5А, Bourns | 1 | F1
 |  |  |  |  |  |  |  |  |  | Приборы звуковой
 |  |  |  |  |  |  |  |  |  | сигнализации
 |  |  |  | 11 |  |  |  |  |  | HC0905A, JL World | 1 | HA1
 |  |  |  |  |  |  |  |  |  | Светодиоды
Подп. дата
 |  |  |  | 12 |  |  |  |  |  | SMD05050C6 | 1 | HL1
 |  |  |  |  |  |  |  |  |  | Индуктивности
 |  |  |  | 13 |  |  |  |  |  | КИК 1005-1,2 нГн +-5% О-Л | 1 | L1*
Инв. № дубл.
 |  |  |  |  |  |  |  |  |  | РКМУ.671340.002 ТУ
 |  |  |  | 14 |  |  |  |  |  | BLM18AG102SN1D, Murata | 2 | L2,L3
Взам. инв. № |  |  |  |  |  |  |  |  |  | Резисторы
 |  |  |  | 15 |  |  |  |  |  | Р1-8В-0,1-1 кОм+-10% Л-П-М | 6 | R9-R14
 |  |  |  | 16 |  |  |  |  |  | Р1-8В-0,1-5,1 кОм+-10% Л-П-М | 2 | R1,R2
 |  |  |  | 17 |  |  |  |  |  | Р1-8В-0,1-10 кОм+-10% Л-П-М | 1 | R3
Подп. и дата
 |  |  |  | 18 |  |  |  |  |  | Р1-8В-0,1-100 кОм+-10% Л-П-М | 2 | R6,R7
 |  |  |  |  |  |  |  |  |  | ОЖО.467.164 ТУ
Инв. № подл.
 |  |  |  |  |  |  |  |  | МГТУ.469335.001 |  |  |  | Лист
 |  |  |  |  |  |  |  |  |  |  |  |  | 2
 | Изм. |  | Лист |  | № докум. |  | Подп. | Дата
 |  |  |  |  |  |  |  |  | Копировал | Формат А4

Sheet: С Л3
 | Формат | Зона |  | Поз. |  | Обозначение |  |  |  | Наименование | Кол. | Приме- чание
 |  |  |  |  |  |  |  |  |  | Выключатели кнопочные
 |  |  |  | 19 |  |  |  |  |  | KLS7-P8.5x8.5-1 | 1 | SB1
 |  |  |  |  |  |  |  |  |  | Модуляторы
 |  |  |  | 20 |  |  |  |  |  | RFM95W 868МГц, Hope RF | 1 | U1
 |  |  |  |  |  |  |  |  |  | Диоды
 |  |  |  | 21 |  |  |  |  |  | BAT760, NXP | 1 | VD2
 |  |  |  | 22 |  |  |  |  |  | USBLC6-2SC6, STMicroelectronics | 1 | VD1
 |  |  |  |  |  |  |  |  |  | Транзисторы
 |  |  |  | 23 |  |  |  |  |  | SI2302A, UMW | 2 | VT1, VT3
 |  |  |  |  |  |  |  |  |  | Разъёмы
Подп. дата
 |  |  |  | 24 |  |  |  |  |  | PLS-2R тип D, Connfly | 1 | XP1
 |  |  |  | 25 |  |  |  |  |  | PLS-6R тип D, Connfly | 1 | XP2
 |  |  |  | 26 |  |  |  |  |  | USB Type-C 213716-0001, Ruichi | 1 | XS1
Инв. № дубл.
 |  |  |  |  |  |  |  |  |  | Резонаторы кварцевые
 |  |  |  | 29 |  |  |  |  |  | 12MHz SMD03225C4 | 1 | ZQ1
 |  |  |  | 30 |  |  |  |  |  | 32.768kHz SMD03215C2 | 1 | ZQ2
Взам. инв. №
 |  |  |  |  |  | Переменные данные |  |  |  | для исполнений
 |  |  |  |  |  |  |  |  |  | МГТУ.464415.001-00
Подп. и дата
 |  |  |  |  |  |  |  |  |  | Прочие изделия
 |  |  |  |  |  |  |  |  |  | Резисторы
 |  |  |  | 31 |  |  |  |  |  | Р1-8В-0,1-0 Ом+-10% Л-П-М | 1 | R17
Инв. № подл.
 |  |  |  |  |  |  |  |  | МГТУ.469335.001 |  |  |  | Лист
 |  |  |  |  |  |  |  |  |  |  |  |  | 3
 | Изм. |  | Лист |  | № докум. |  | Подп. | Дата
 |  |  |  |  |  |  |  |  | Копировал | Формат А4

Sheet: С Л4
 | Формат | Зона |  | Поз. |  | Обозначение |  |  |  | Наименование | Кол. | Приме- чание
 |  |  |  |  |  | Переменные данные |  |  |  | для исполнений
 |  |  |  |  |  |  |  |  |  | МГТУ.464415.001-01
 |  |  |  |  |  |  |  |  |  | Прочие изделия
 |  |  |  |  |  |  |  |  |  | Фотоэлементы
 |  |  |  | 32 |  |  |  |  |  | SFH213FA, Osram | 1 | BL1
 |  |  |  | 33 |  |  |  |  |  | TSOP4836, Vishay | 1 | BL2
 |  |  |  |  |  |  |  |  |  | Конденсаторы
 |  |  |  | 2 |  |  |  |  |  | 04025U1CAT2A 1пФ+-0,25пФ | 1 | C27*
 |  |  |  |  |  |  |  |  |  | 50В NP0, AVX Corporation
 |  |  |  | 34 |  |  |  |  |  | К10-90-1608-6,3В-680пФ+-10%-Н30 | 1 | C22
 |  |  |  | 6 |  |  |  |  |  | К10-90-1608-10В-100нФ+-10%-Н30 | 2 | C6,C7
Подп. дата
 |  |  |  |  |  |  |  |  |  | ШУКР.673511.002 ТУ
 |  |  |  |  |  |  |  |  |  | Микросхемы
 |  |  |  | 35 |  |  |  |  |  | MCP6001RT-I/OT | 1 | DA1
Инв. № дубл.
 |  |  |  |  |  |  |  |  |  | Microchip Technology
 |  |  |  |  |  |  |  |  |  | Резисторы
Взам. инв. № |  |  |  | 36 |  |  |  |  |  | Р1-8В-0,1-100 Ом+-10% Л-П-М | 1 | R4,R5
 |  |  |  | 15 |  |  |  |  |  | Р1-8В-0,1-1 кОм+-10% Л-П-М | 1 | R8
 |  |  |  | 18 |  |  |  |  |  | Р1-8В-0,1-100 кОм+-10% Л-П-М | 2 | R15
 |  |  |  |  |  |  |  |  |  | ОЖО.467.164 ТУ
Подп. и дата
 |  |  |  |  |  |  |  |  |  | Выключатели кнопочные
 |  |  |  | 37 |  |  |  |  |  | KLS7-TS6601-5.0-180 | 1 | SB2
 |  |  |  |  |  |  |  |  |  | KLS Electronics
Инв. № подл.
 |  |  |  |  |  |  |  |  | МГТУ.469335.001 |  |  |  | Лист
 |  |  |  |  |  |  |  |  |  |  |  |  | 4
 | Изм. |  | Лист |  | № докум. |  | Подп. | Дата
 |  |  |  |  |  |  |  |  | Копировал | Формат А4

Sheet: С Л5
 | Формат | Зона |  | Поз. |  | Обозначение |  |  |  | Наименование | Кол. | Приме- чание
 |  |  |  |  |  |  |  |  |  | Диоды
 |  |  |  | 38 |  |  |  |  |  | ESDA5V3L, STMicroelectronics | 1 | VD3
 |  |  |  |  |  |  |  |  |  | МГТУ.464415.001-02
 |  |  |  |  |  |  |  |  |  | Прочие изделия
 |  |  |  |  |  |  |  |  |  | Резисторы
 |  |  |  | 39 |  |  |  |  |  | Р1-8В-0,1-10 Ом+-10% Л-П-М | 1 | R16
 |  |  |  |  |  |  |  |  |  | ОЖО.467.164 ТУ
 |  |  |  |  |  |  |  |  |  | Выключатели кнопочные
 |  |  |  | 37 |  |  |  |  |  | KLS7-TS6601-5.0-180 | 1 | SB2
 |  |  |  |  |  |  |  |  |  | KLS Electronics
Подп. дата
 |  |  |  |  |  |  |  |  |  | Диоды
 |  |  |  | 38 |  |  |  |  |  | ESDA5V3L, STMicroelectronics | 1 | VD3
 |  |  |  | 40 |  |  |  |  |  | TSAL6200, Vishay | 1 | VD4
Инв. № дубл.
 |  |  |  |  |  |  |  |  |  | Транзисторы
 |  |  |  | 23 |  |  |  |  |  | SI2302A, UMV | 1 | VT2
Взам. инв. №
Подп. и дата
Инв. № подл.
 |  |  |  |  |  |  |  |  | МГТУ.469335.001 |  |  |  | Лист
 |  |  |  |  |  |  |  |  |  |  |  |  | 5
 | Изм. |  | Лист |  | № докум. |  | Подп. | Дата
 |  |  |  |  |  |  |  |  | Копировал | Формат А4

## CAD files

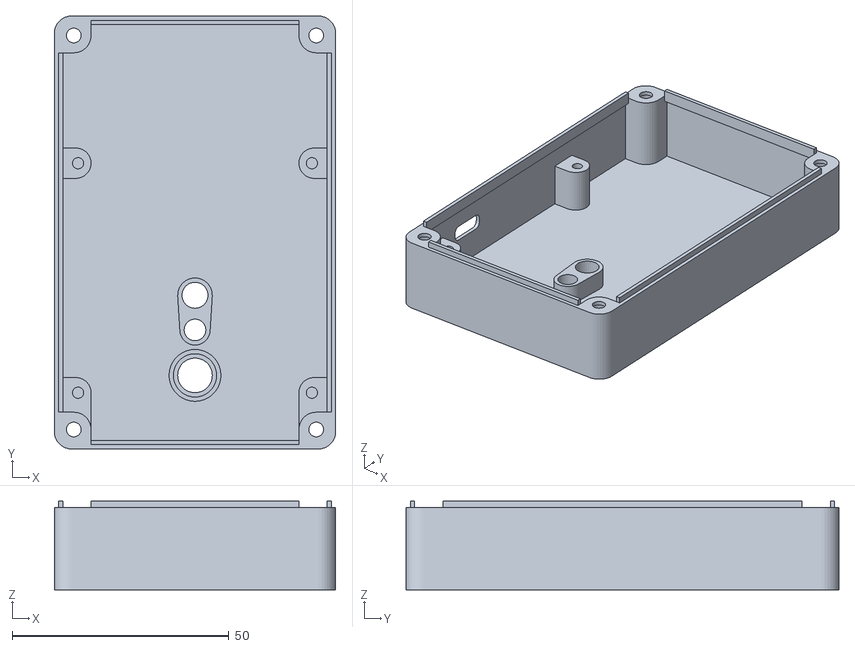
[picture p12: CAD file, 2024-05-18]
Bagryanets_3d/STL/МГТУ.741344.001-02_МД.STL
65.0 x 100.0 x 20.5

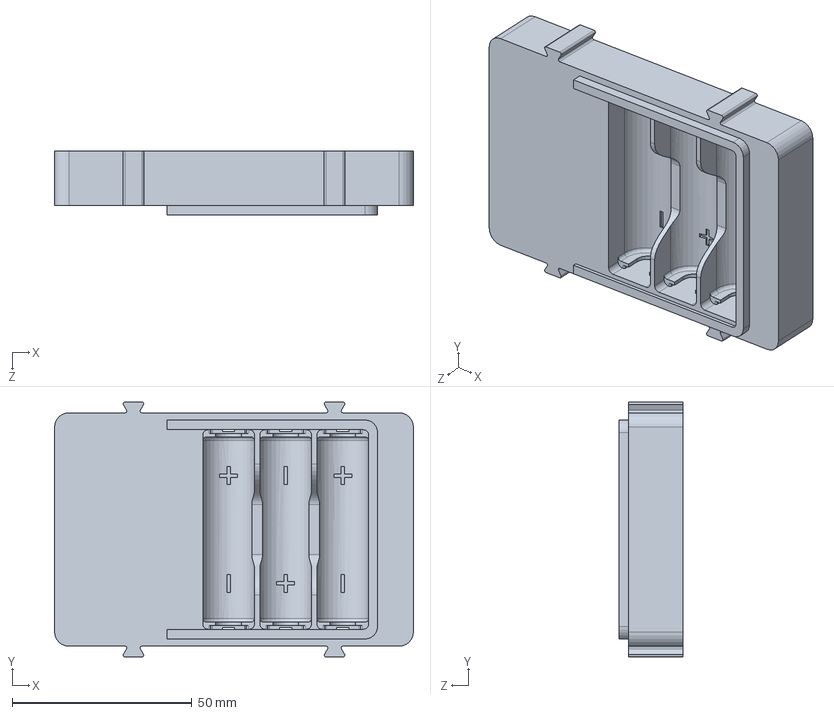
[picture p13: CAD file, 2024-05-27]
Bagryanets_3d/МГТУ.731146.001 Корпус.SLDPRT
100.0 x 71.0 x 18.0 mm

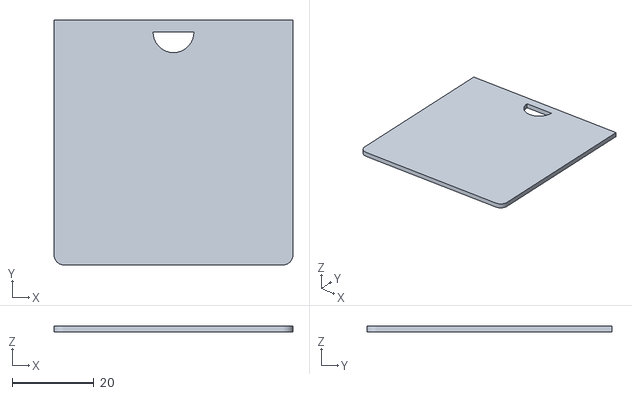
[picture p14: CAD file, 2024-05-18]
Bagryanets_3d/STL/МГТУ.741316.001_МД.STL
58.5 x 60.0 x 1.50

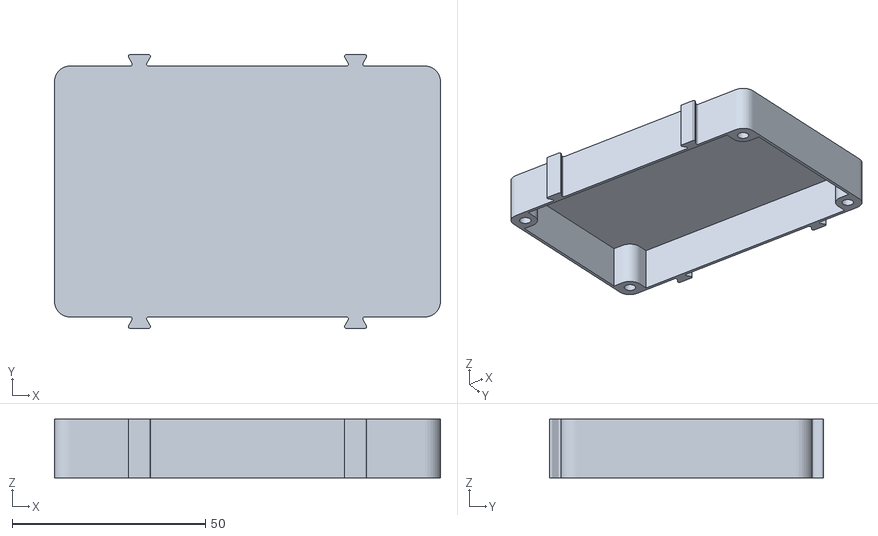
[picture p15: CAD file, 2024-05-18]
Bagryanets_3d/STL/МГТУ.731146.001-00_МД.STL
100.0 x 71.0 x 15.2

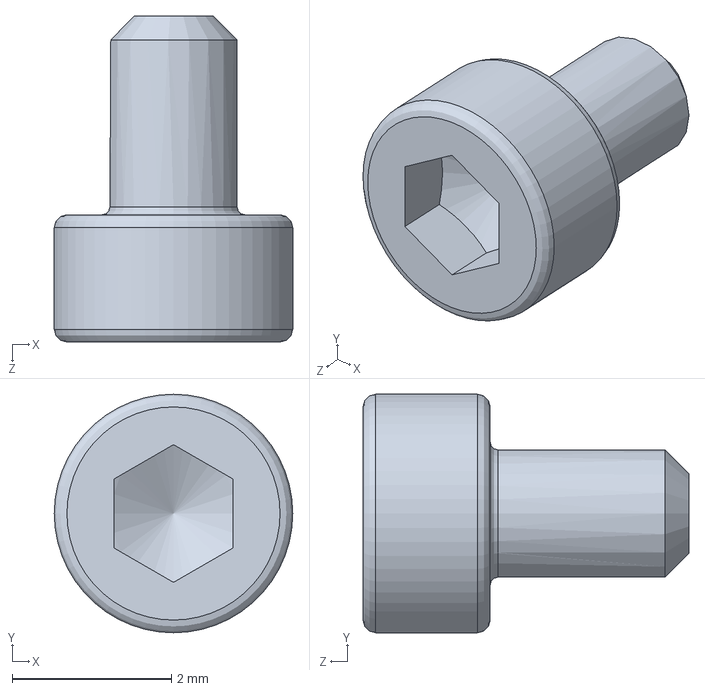
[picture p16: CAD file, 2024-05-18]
Bagryanets_3d/ГОСТ Р ИСО 4762-2012.SLDPRT
3.00 x 3.00 x 4.10 mm

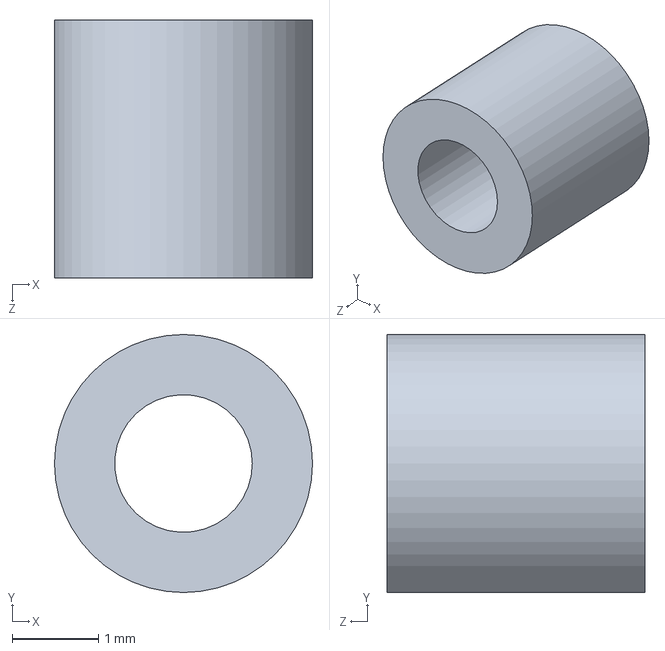
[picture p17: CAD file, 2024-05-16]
Bagryanets_3d/Вставка вплавляемая М2х3х3.SLDPRT
3.00 x 3.00 x 3.00 mm

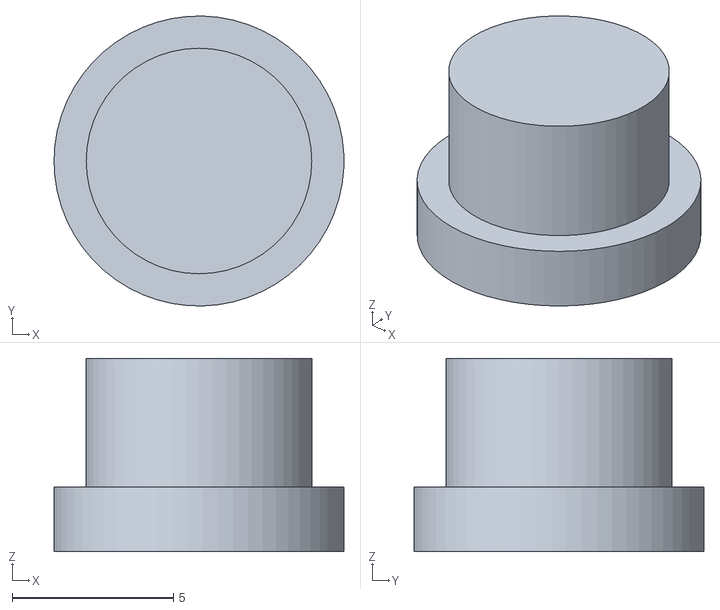
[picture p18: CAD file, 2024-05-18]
Bagryanets_3d/STL/МГТУ.713621.001_МД.STL
9.00 x 9.00 x 6.00

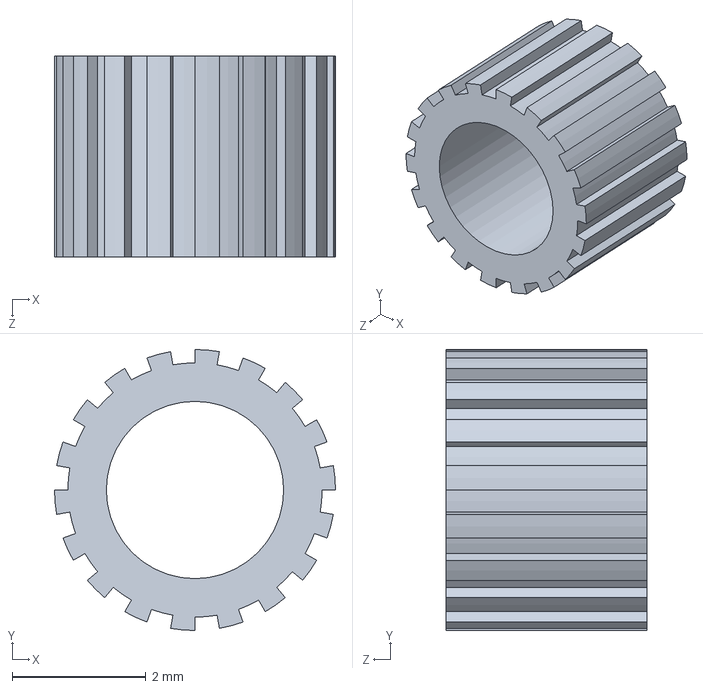
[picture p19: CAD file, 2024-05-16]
Bagryanets_3d/Вставка вплавляемая М3х3х4.2.SLDPRT
4.20 x 4.20 x 3.00 mm

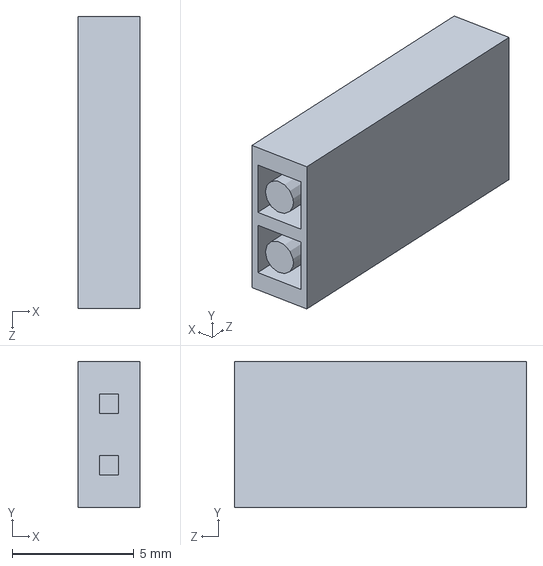
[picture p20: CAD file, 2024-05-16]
Bagryanets_3d/Розетка на кабель.SLDPRT
2.54 x 6.00 x 12.0 mm

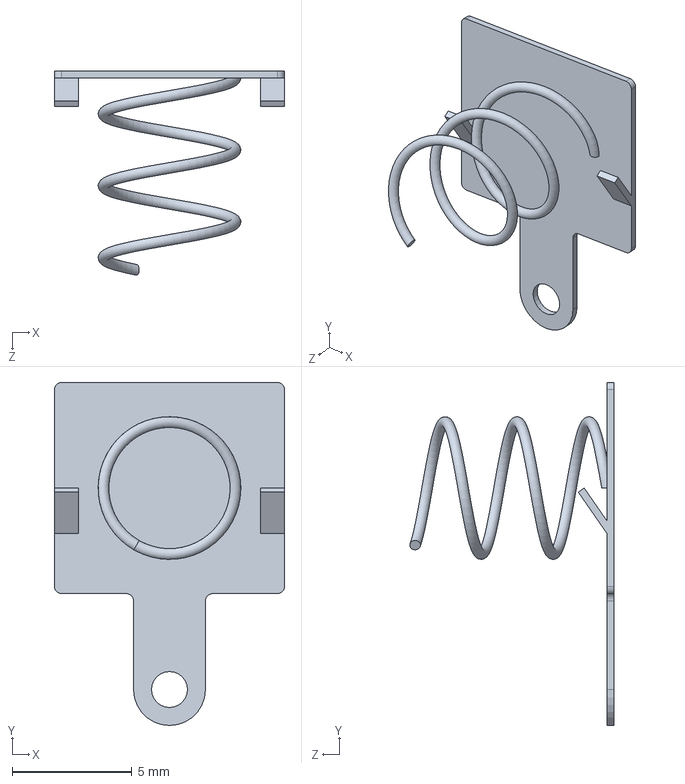
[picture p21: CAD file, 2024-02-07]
Bagryanets_3d/Контакт АА минус.SLDPRT
9.60 x 14.3 x 8.53 mm

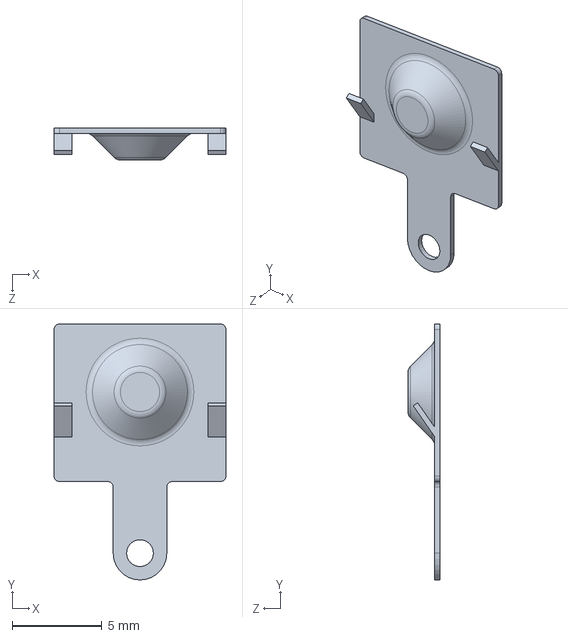
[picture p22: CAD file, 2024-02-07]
Bagryanets_3d/Контакт АА плюс.SLDPRT
9.60 x 14.3 x 1.80 mm

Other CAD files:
Bagryanets_3d/МГТУ.741344.001 Крышка.SLDPRT
Bagryanets_3d/STL/МГТУ.741344.001-01_МД.STL
Bagryanets_3d/МГТУ.741316.001 Крышка задвижная.SLDPRT
Bagryanets_3d/STL/МГТУ.731146.001-01_МД.STL
Bagryanets_3d/STL/МГТУ.741344.001-00_МД.STL
Bagryanets_3d/МГТУ.713621.001 Кнопка.SLDPRT

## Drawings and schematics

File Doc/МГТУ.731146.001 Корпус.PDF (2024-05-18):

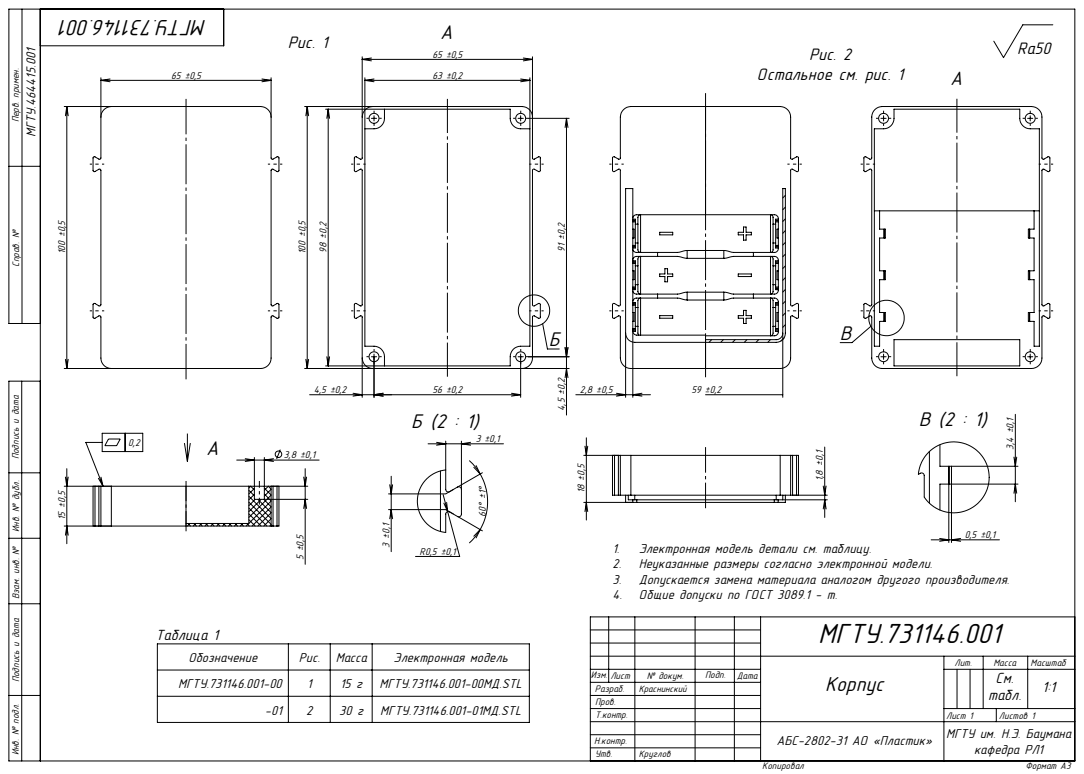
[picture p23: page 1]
Ðèñ. 1; Òàáëèöà 1; МГТУ.731146.001-00; МГТУ.731146.001-00МД.STL; МГТУ.731146.001-01МД.STL; Êîïèðîâàë; Ôîðìàò À3; Èçì. Ëèñò; ¹ äîêóì.; Ïîäï.; Äàòà

Ðèñ. 2
Îñòàëüíîå ñì. ðèñ. 1

Ñïðàâ. ¹ Ïåðâ. ïðèìåí. Ïîäïèñü è äàòà Èíâ. ¹ äóáë. Âçàì. èíâ. ¹ Ïîäïèñü è äàòà Èíâ. ¹ ïîäë.

1. Ýëåêòðîííàÿ ìîäåëü äåòàëè ñì. òàáëèöó.
2. Íåóêàçàííûå ðàçìåðû ñîãëàñíî ýëåêòðîííîé ìîäåëè.
3. Äîïóñêàåòñÿ çàìåíà ìàòåðèàëà àíàëîãîì äðóãîãî ïðîèçâîäèòåëÿ.
4. Îáùèå äîïóñêè ïî ÃÎÑÒ 3089.1 - m.

ÌÃÒÓ.731146.001

Обозначение | Рис. | Масса | Электронная модель

Êîðïóñ | Ëèò. | Ìàññà | Ìàñøòàá

Ò.êîíòð. | | Ëèñò 1 | Ëèñòîâ 1

ÀÁÑ-2802-31 ÀÎ «Ïëàñòèê» | ÌÃÒÓ èì. Í.Ý. Áàóìàíà êàôåäðà ÐË1

Í.êîíòð.
Óòâ. | Êðóãëîâ

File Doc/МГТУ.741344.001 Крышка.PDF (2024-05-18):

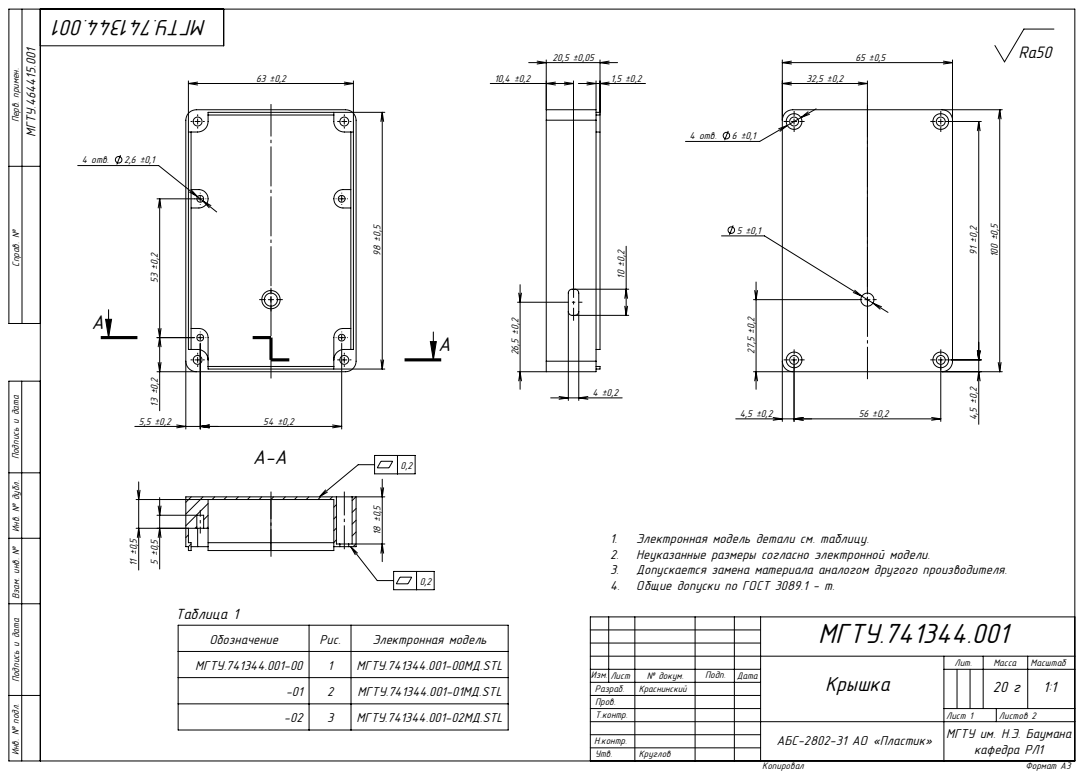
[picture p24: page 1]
4 отв. 6 ±0,1; 4 отв. 2,6 ±0,1; Òàáëèöà 1; Êîïèðîâàë; Ôîðìàò À3

Ñïðàâ. ¹ Ïåðâ. ïðèìåí. Ïîäïèñü è äàòà Èíâ. ¹ äóáë. Âçàì. èíâ. ¹ Ïîäïèñü è äàòà Èíâ. ¹ ïîäë.

1. Ýëåêòðîííàÿ ìîäåëü äåòàëè ñì. òàáëèöó.
2. Íåóêàçàííûå ðàçìåðû ñîãëàñíî ýëåêòðîííîé ìîäåëè.
3. Äîïóñêàåòñÿ çàìåíà ìàòåðèàëà àíàëîãîì äðóãîãî ïðîèçâîäèòåëÿ.
4. Îáùèå äîïóñêè ïî ÃÎÑÒ 3089.1 - m.

ÌÃÒÓ.741344.001

Обозначение | Рис. | Электронная модель
МГТУ.741344.001-00 | 1 | МГТУ.741344.001-00МД.STL

Êðûøêà | Ëèò. | Ìàññà | Ìàñøòàá

Èçì. Ëèñò | ¹ äîêóì. | Ïîäï. | Äàòà | | | | | 20 ã | 1:1
Ðàçðàá. | Êðàñíèíñêèé
Ïðîâ.
Ò.êîíòð. | | | | Ëèñò 1 | Ëèñòîâ 2

-01 | 2 | МГТУ.741344.001-01МД.STL
-02 | 3 | МГТУ.741344.001-02МД.STL

ÀÁÑ-2802-31 ÀÎ «Ïëàñòèê» | ÌÃÒÓ èì. Í.Ý. Áàóìàíà êàôåäðà ÐË1

Í.êîíòð.
Óòâ. | Êðóãëîâ

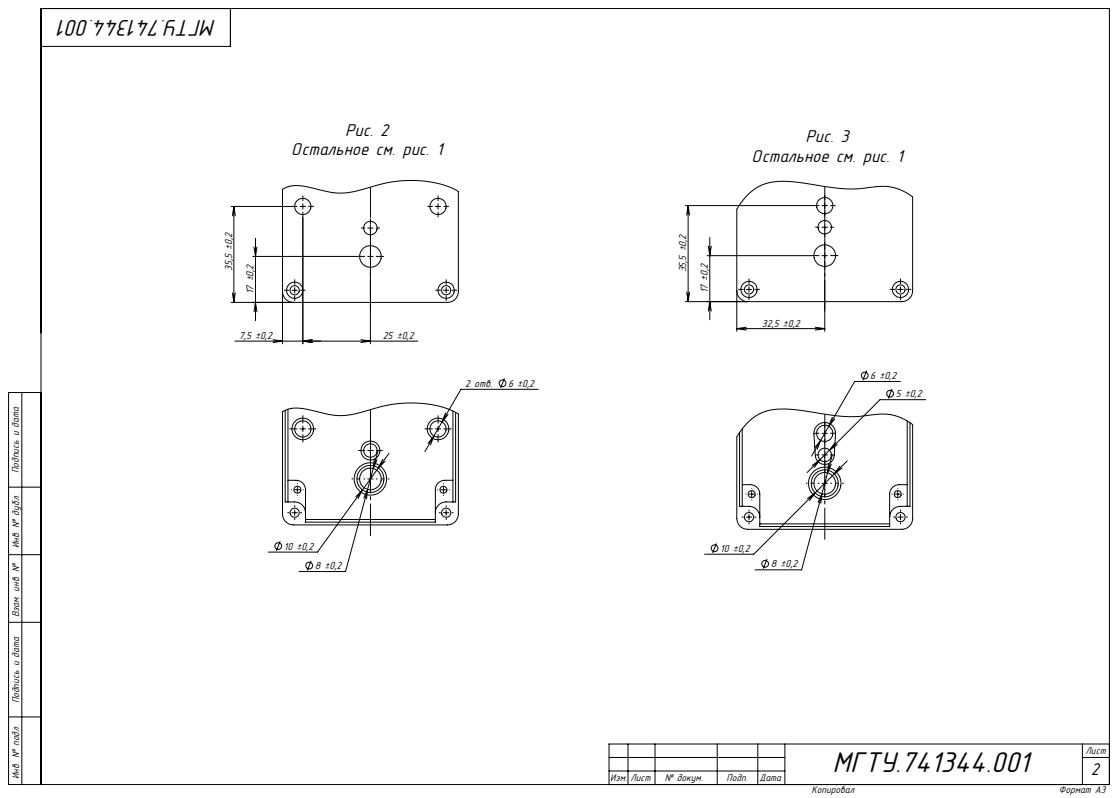
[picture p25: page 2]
2 отв. 6 ±0,2; Êîïèðîâàë; Ôîðìàò À3; Èçì. Ëèñò; ¹ äîêóì.; Ïîäï.; Äàòà

Ðèñ. 2
Îñòàëüíîå ñì. ðèñ. 1

Ðèñ. 3

Ïîäïèñü è äàòà Èíâ. ¹ äóáë. Âçàì. èíâ. ¹ Ïîäïèñü è äàòà Èíâ. ¹ ïîäë.

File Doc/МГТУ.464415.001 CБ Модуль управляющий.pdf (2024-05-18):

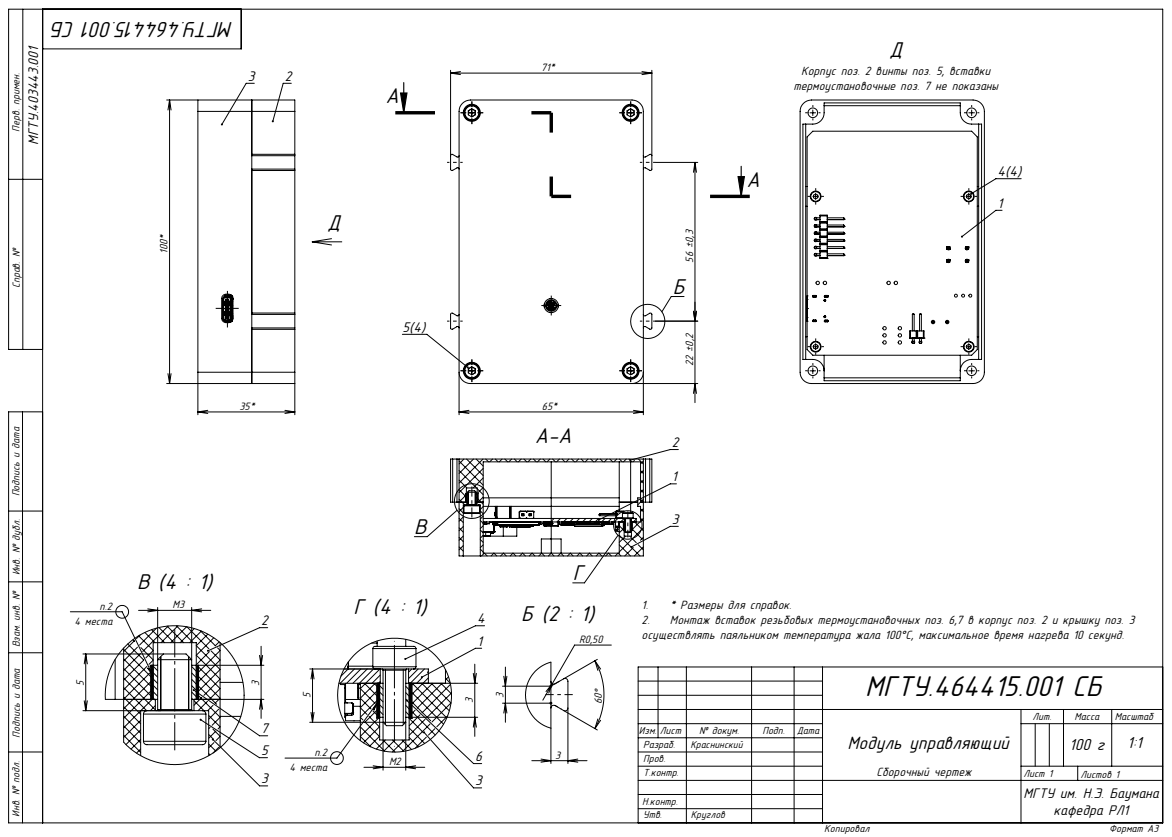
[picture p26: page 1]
4 места; Êîïèðîâàë; Ôîðìàò À3; Èçì. Ëèñò; ¹ äîêóì.; Ïîäï.; Äàòà

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

Корпус поз. 2 винты поз. 5, вставки
термоустановочные поз. 7 не показаны

1. * Размеры для справок.
2. Монтаж вставок резьбовых термоустановочных поз. 6,7 в корпус поз. 2 и крышку поз. 3
осуществлять паяльником температура жала 100°C, максимальное время нагрева 10 секунд.

ÌÃÒÓ.464415.001 ÑÁ

Ìîäóëü óïðàâëÿþùèé Ñáîðî÷íûé ÷åðòåæ | Ëèò. | Ìàññà | Ìàñøòàá

Ðàçðàá. | Êðàñíèíñêèé
Ïðîâ.
Ò.êîíòð. | | Ëèñò 1 | Ëèñòîâ 1

ÌÃÒÓ èì. Í.Ý. Áàóìàíà êàôåäðà ÐË1

Í.êîíòð.
Óòâ. | Êðóãëîâ

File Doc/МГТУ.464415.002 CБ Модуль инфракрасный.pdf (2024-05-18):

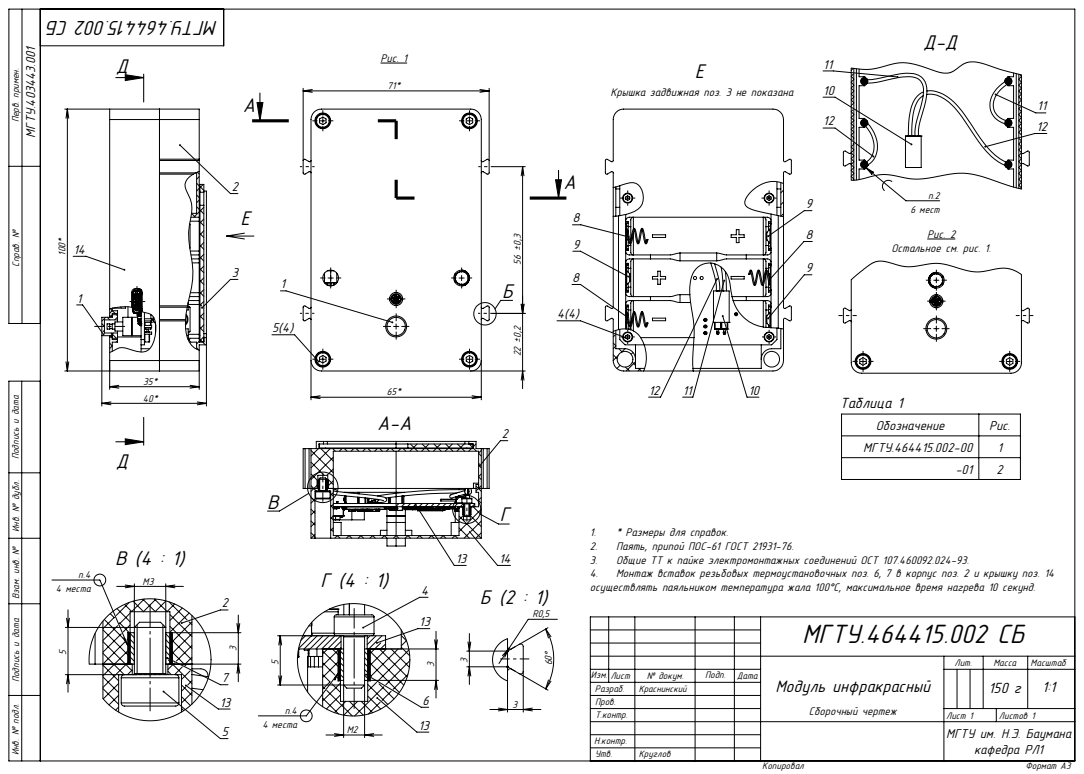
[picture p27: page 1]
Рис. 1; 4 места; 6 мест; Òàáëèöà 1; Êîïèðîâàë; Ôîðìàò À3

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

Крышка задвижная поз. 3 не показана

Рис. 2
Остальное см. рис. 1.

Обозначение | Рис.
МГТУ.464415.002-00 | 1

1. * Размеры для справок.
2. Паять, припой ПОС-61 ГОСТ 21931-76.
3. Общие ТТ к пайке электромонтажных соединений ОСТ 107.460092.024-93.
4. Монтаж вставок резьбовых термоустановочных поз. 6, 7 в корпус поз. 2 и крышку поз. 14
осуществлять паяльником температура жала 100°C, максимальное время нагрева 10 секунд.

ÌÃÒÓ.464415.002 ÑÁ

Ìîäóëü èíôðàêðàñíûé Ñáîðî÷íûé ÷åðòåæ | Ëèò. | Ìàññà | Ìàñøòàá

Èçì. Ëèñò | ¹ äîêóì. | Ïîäï. | Äàòà | | | | | 150 г | 1:1
Ðàçðàá. | Êðàñíèíñêèé
Ïðîâ.
Ò.êîíòð. | | | | Ëèñò 1 | Ëèñòîâ 1

ÌÃÒÓ èì. Í.Ý. Áàóìàíà êàôåäðà ÐË1

Í.êîíòð.
Óòâ. | Êðóãëîâ

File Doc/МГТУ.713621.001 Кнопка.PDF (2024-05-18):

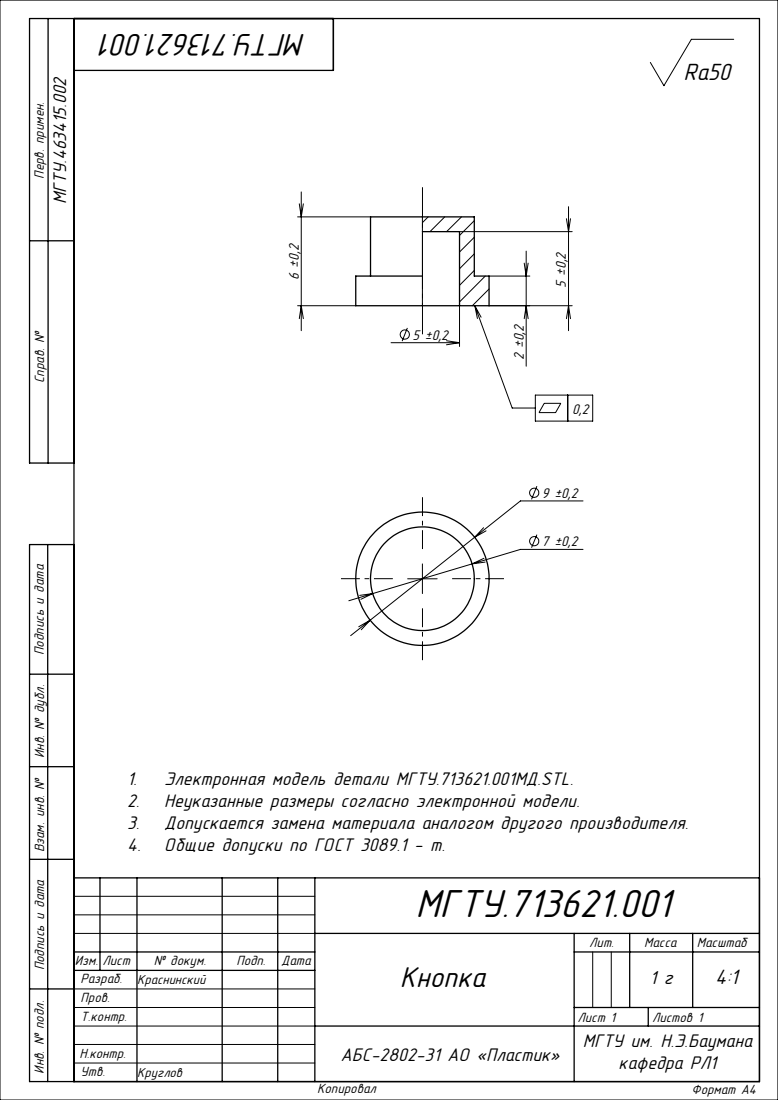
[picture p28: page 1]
Êîïèðîâàë; Ôîðìàò À4

Ñïðàâ. ¹ Ïåðâ. ïðèìåí.

Ïîäïèñü è äàòà Èíâ. ¹ äóáë. Âçàì. èíâ. ¹ Ïîäïèñü è äàòà Èíâ. ¹ ïîäë.

1. Ýëåêòðîííàÿ ìîäåëü äåòàëè ÌÃÒÓ.713621.001ÌÄ.STL.
2. Íåóêàçàííûå ðàçìåðû ñîãëàñíî ýëåêòðîííîé ìîäåëè.
3. Äîïóñêàåòñÿ çàìåíà ìàòåðèàëà àíàëîãîì äðóãîãî ïðîèçâîäèòåëÿ.
4. Îáùèå äîïóñêè ïî ÃÎÑÒ 3089.1 - m.

ÌÃÒÓ.713621.001

Кнопка | Ëèò. | Ìàññà | Ìàñøòàá

Èçì. Ëèñò | ¹ äîêóì. | Ïîäï. | Äàòà | | | | | 1 ã | 4:1
Ðàçðàá. | Êðàñíèíñêèé
Ïðîâ.
Ò.êîíòð. | | | | Ëèñò 1 | Ëèñòîâ 1

АБС-2802-31 АО «Пластик» | ÌÃÒÓ èì. Í.Ý.Áàóìàíà êàôåäðà ÐË1

Í.êîíòð.
Óòâ. | Êðóãëîâ

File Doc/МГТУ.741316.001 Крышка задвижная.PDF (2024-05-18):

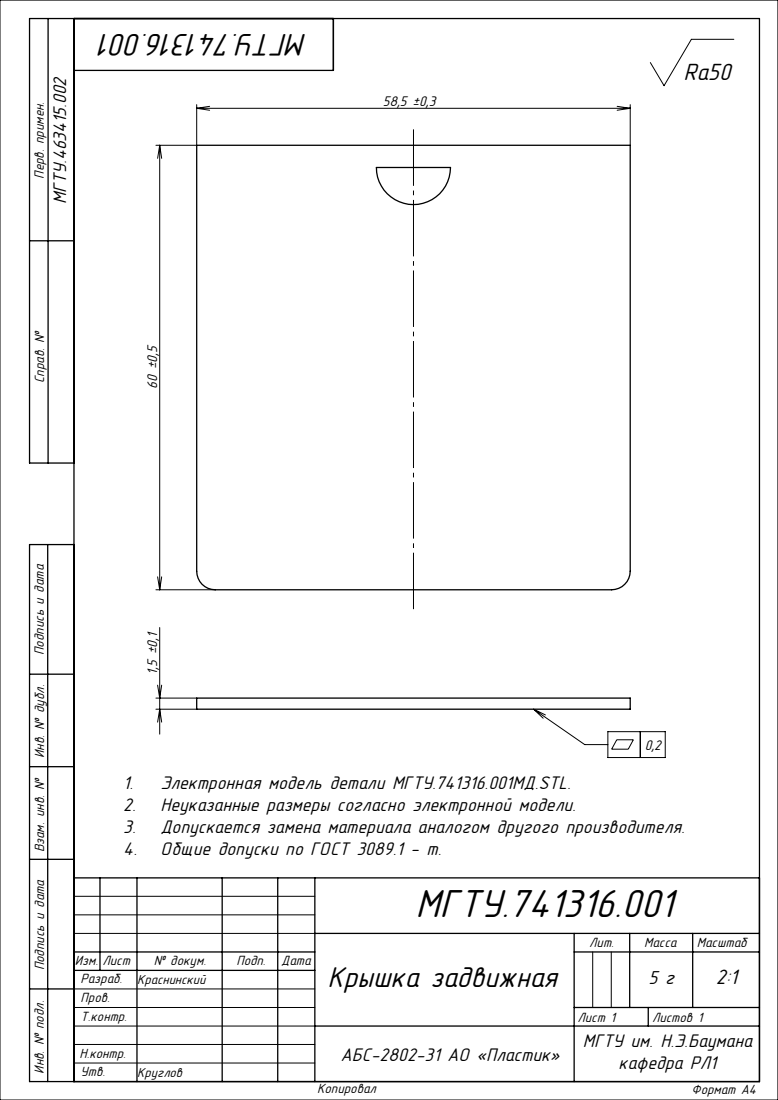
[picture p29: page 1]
Êîïèðîâàë; Ôîðìàò À4

Ñïðàâ. ¹ Ïåðâ. ïðèìåí.

Ïîäïèñü è äàòà Èíâ. ¹ äóáë. Âçàì. èíâ. ¹ Ïîäïèñü è äàòà Èíâ. ¹ ïîäë.

1. Ýëåêòðîííàÿ ìîäåëü äåòàëè ÌÃÒÓ.741316.001ÌÄ.STL.
2. Íåóêàçàííûå ðàçìåðû ñîãëàñíî ýëåêòðîííîé ìîäåëè.
3. Äîïóñêàåòñÿ çàìåíà ìàòåðèàëà àíàëîãîì äðóãîãî ïðîèçâîäèòåëÿ.
4. Îáùèå äîïóñêè ïî ÃÎÑÒ 3089.1 - m.

ÌÃÒÓ.741316.001

Крышка задвижная | Ëèò. | Ìàññà | Ìàñøòàá

Èçì. Ëèñò | ¹ äîêóì. | Ïîäï. | Äàòà | | | | | 5 ã | 2:1
Ðàçðàá. | Êðàñíèíñêèé
Ïðîâ.
Ò.êîíòð. | | | | Ëèñò 1 | Ëèñòîâ 1

АБС-2802-31 АО «Пластик» | ÌÃÒÓ èì. Í.Ý.Áàóìàíà êàôåäðà ÐË1

Í.êîíòð.
Óòâ. | Êðóãëîâ

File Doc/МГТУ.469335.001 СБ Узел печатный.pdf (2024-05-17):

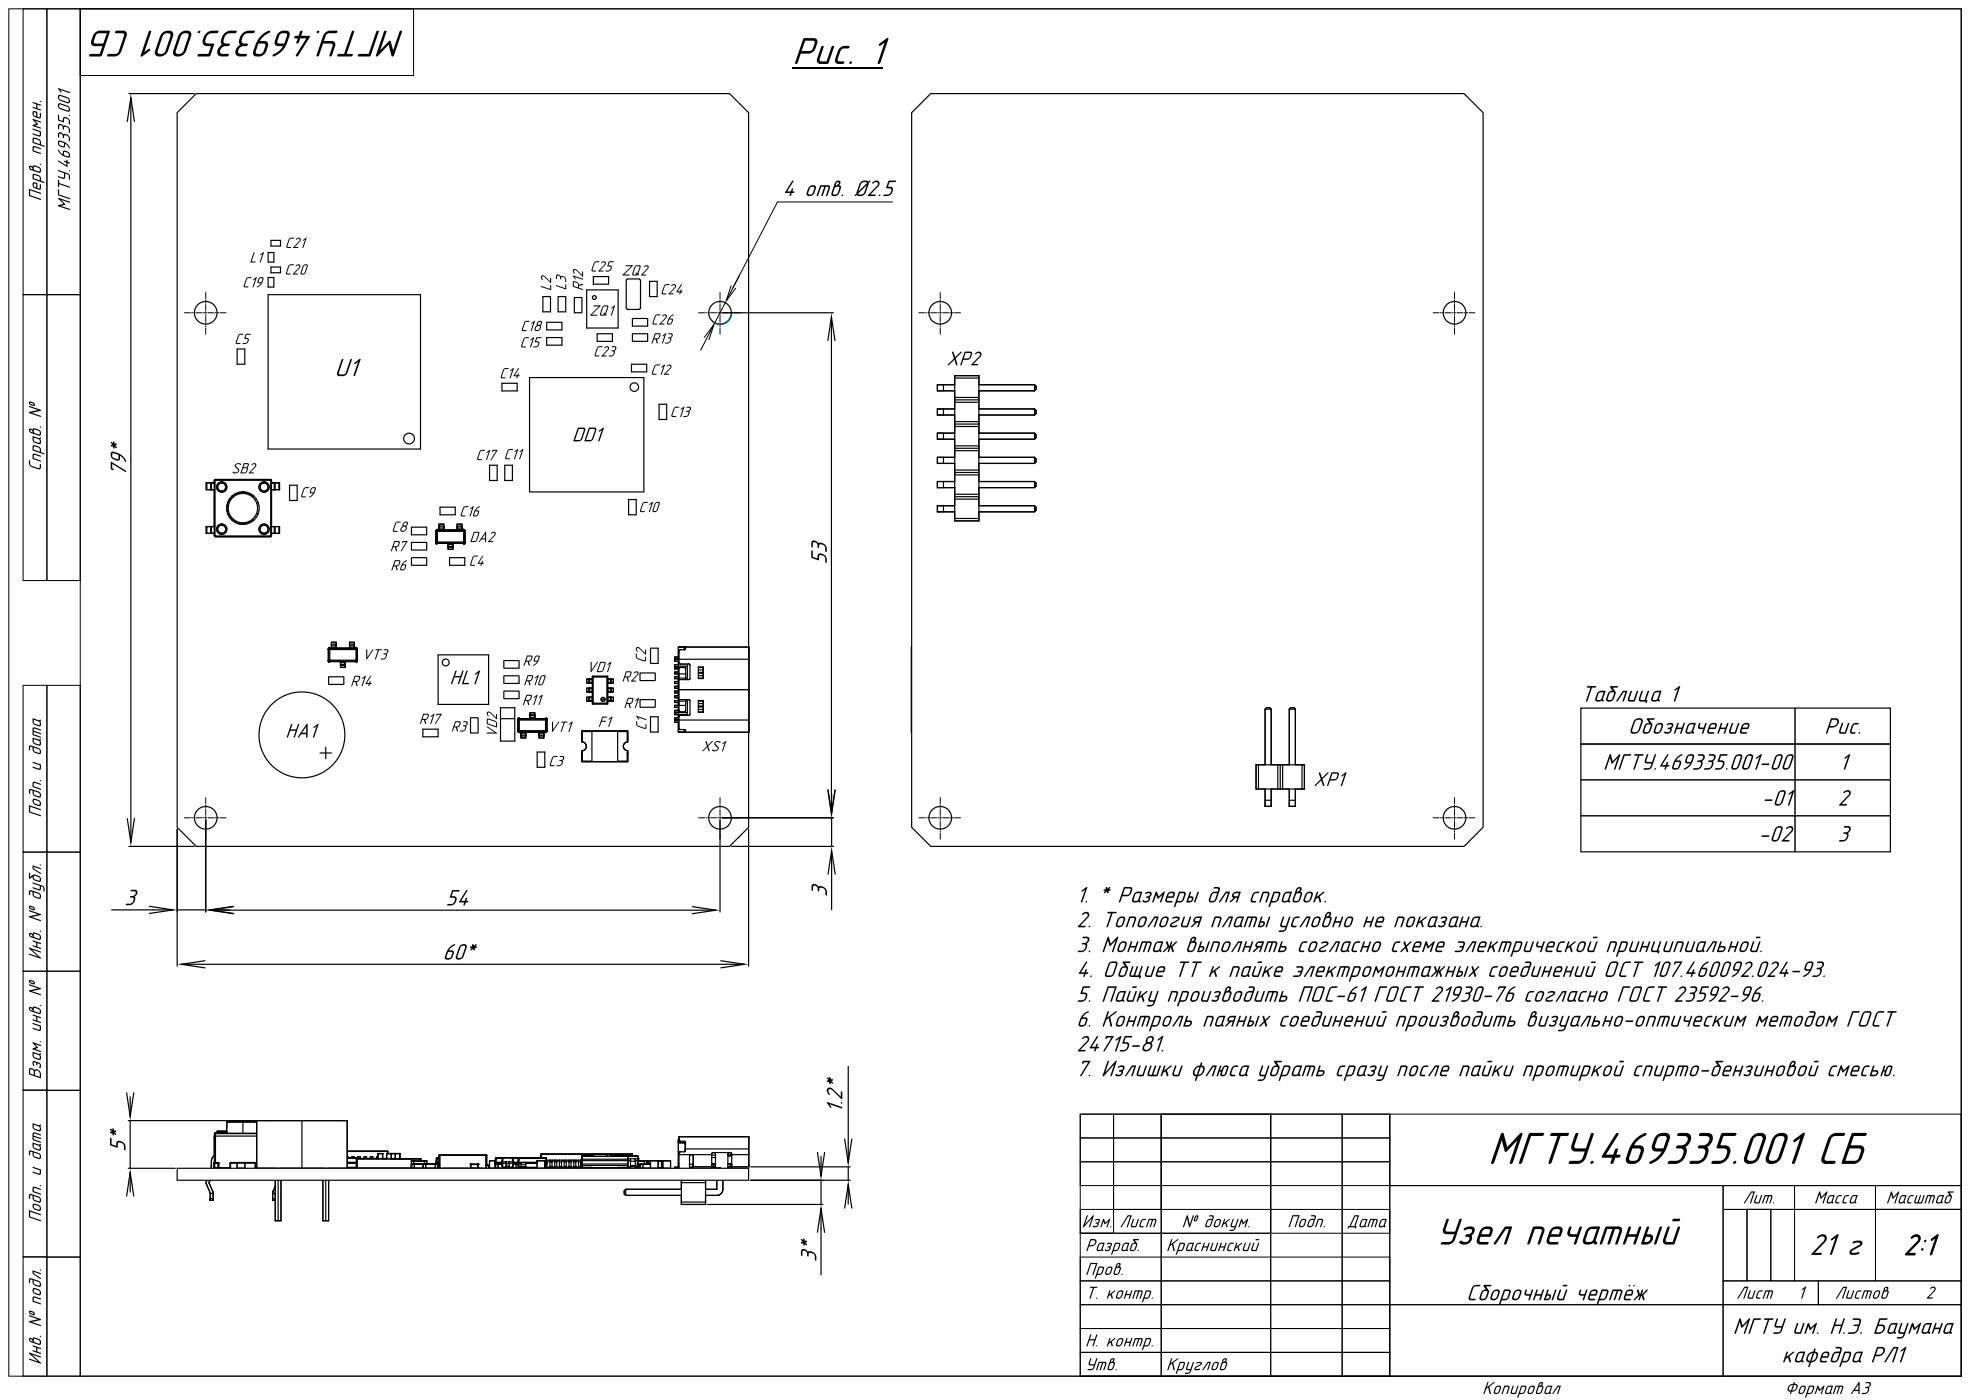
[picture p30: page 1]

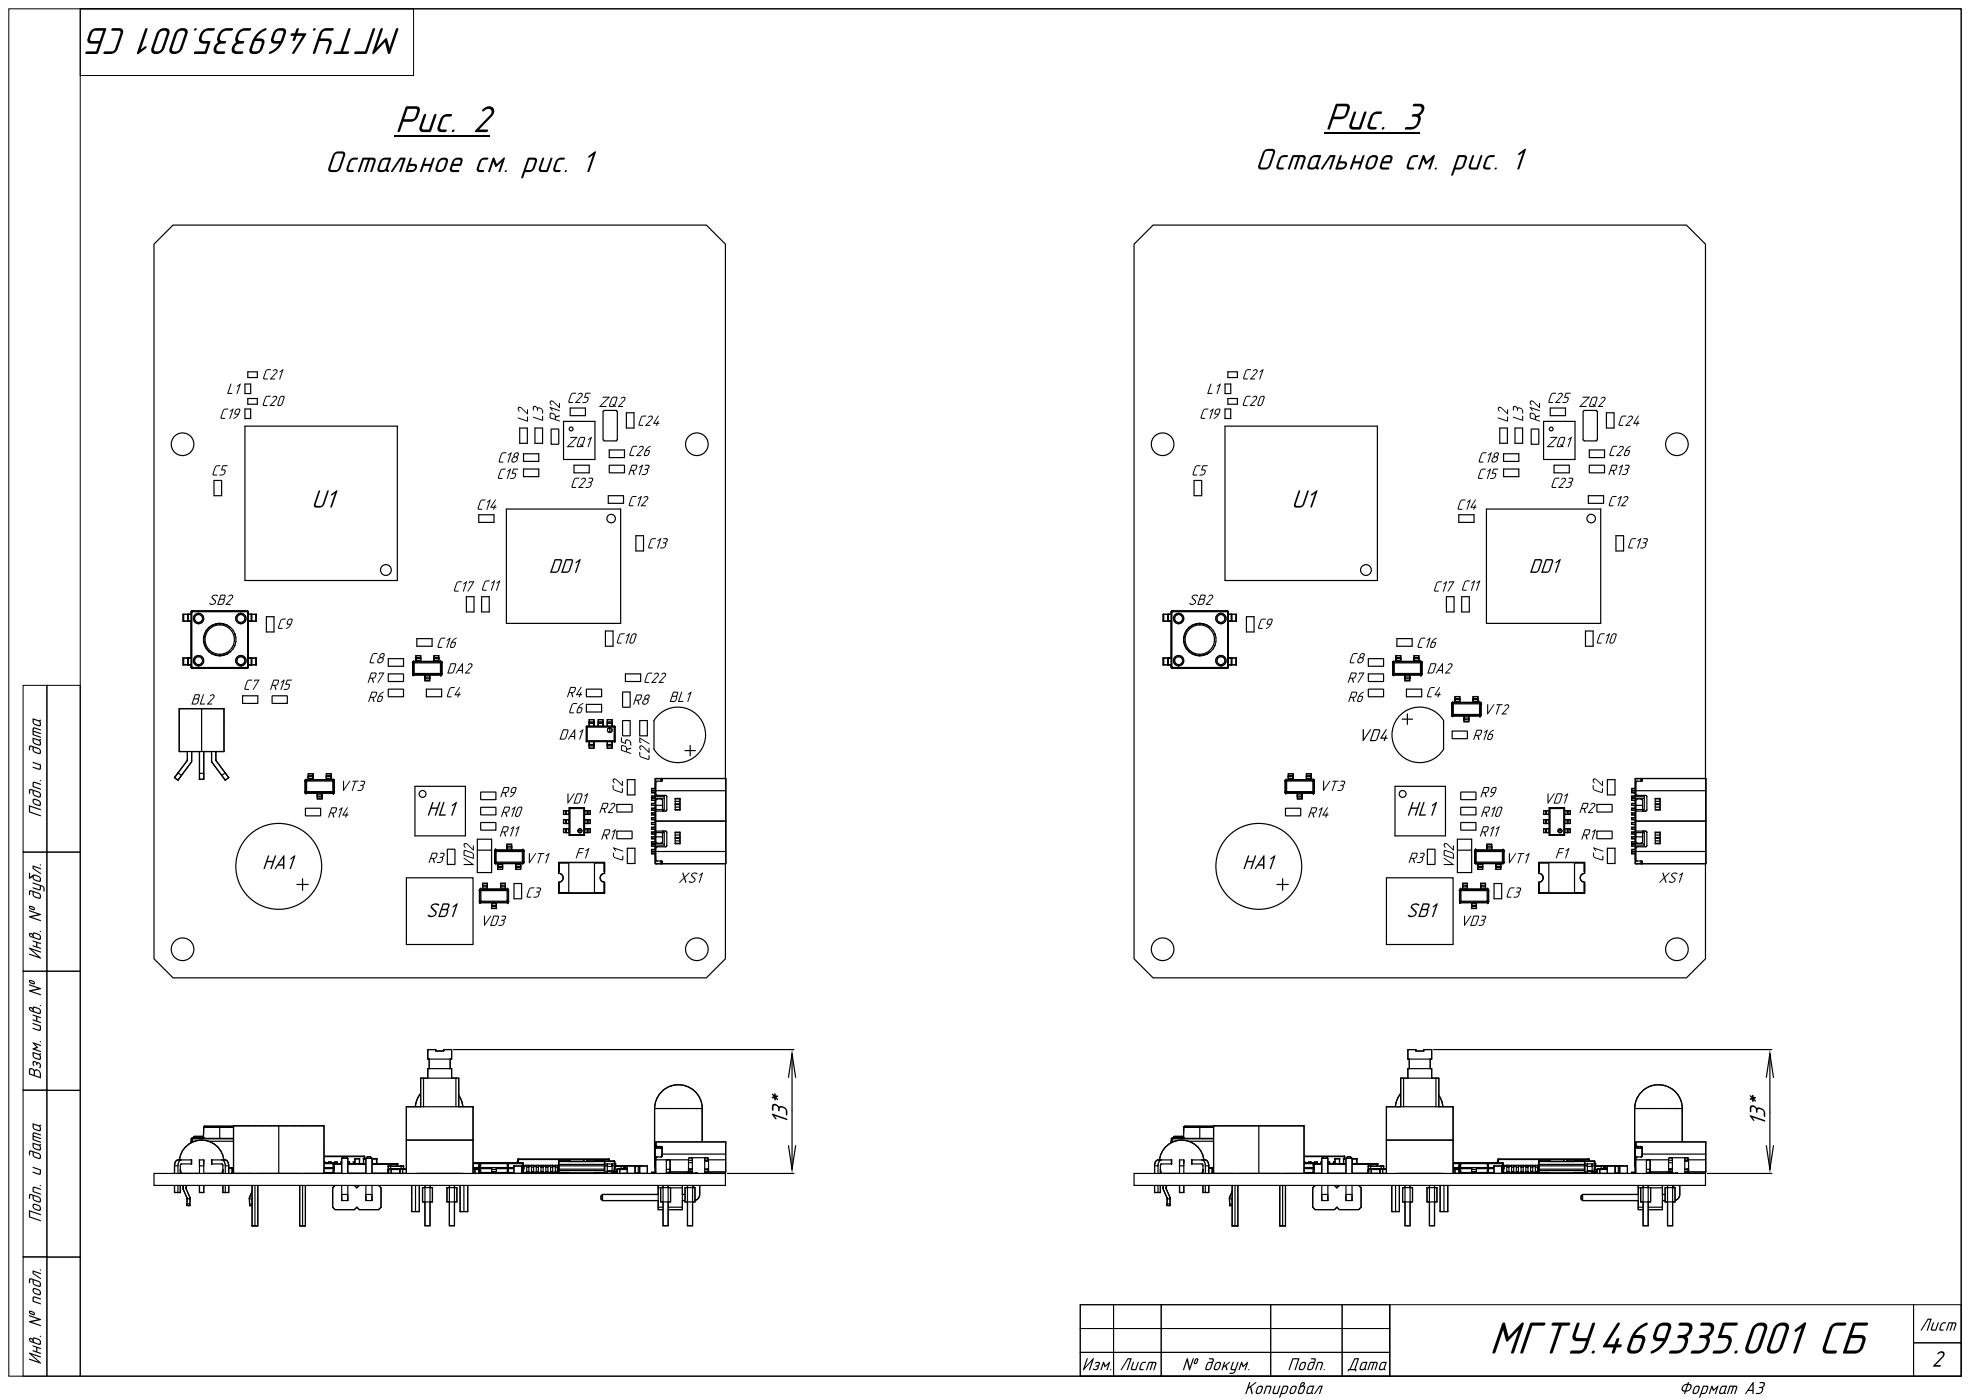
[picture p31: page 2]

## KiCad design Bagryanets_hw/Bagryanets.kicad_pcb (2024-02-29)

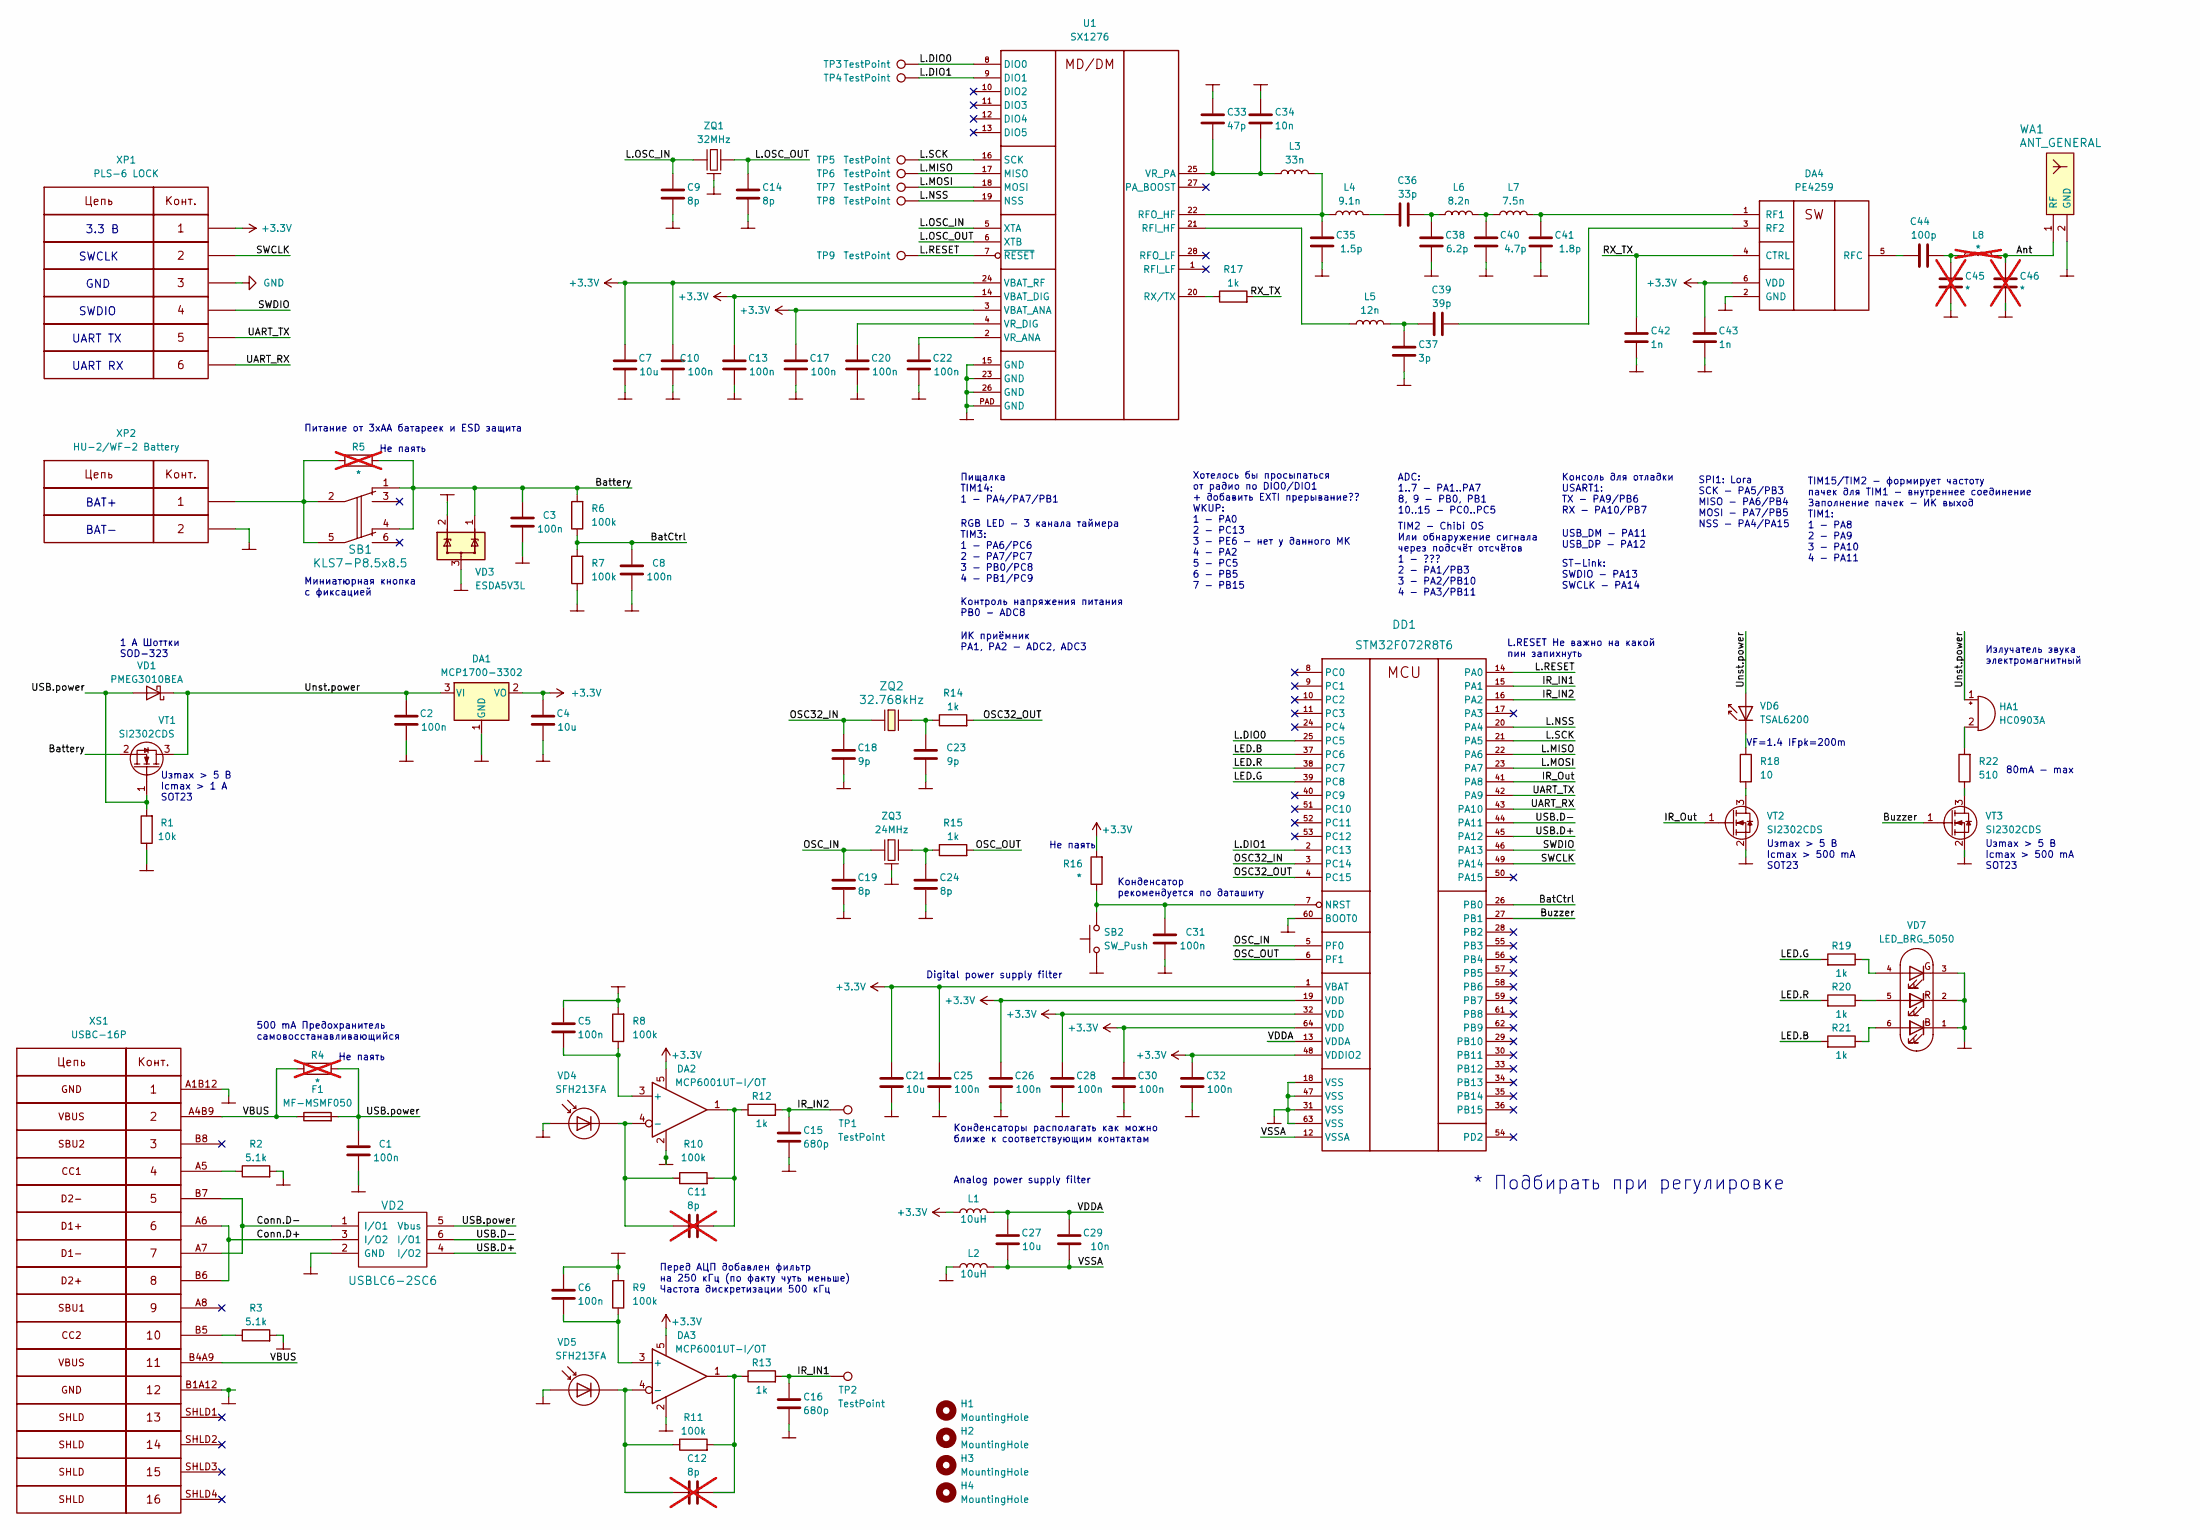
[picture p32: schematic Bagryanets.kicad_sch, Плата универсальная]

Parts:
C1, C2, C3, C5, C6, C8, C10, C13, C17, C20, C22, C25, C26, C28, C30, C31, C32: 100n; CAP_0402
C4, C7, C21, C27: 10u; CAP_0603
C9, C14, C19, C24: 8p; CAP_0402
C11, C12: 8p; CAP_0402; not fitted
C15, C16: 680p; CAP_0402
C18, C23: 9p; CAP_0402
C29, C34: 10n; CAP_0402
C33: 47p; CAP_0402
C35: 1.5p; CAP_0402
C36: 33p; CAP_0402
C37: 3p; CAP_0402
C38: 6.2p; CAP_0402
C39: 39p; CAP_0402
C40: 4.7p; CAP_0402
C41: 1.8p; CAP_0402
C42, C43: 1n; CAP_0402
C44: 100p; CAP_0402
C45, C46: *; CAP_0402; not fitted
DA1: MCP1700-3302; SOT23-3
DA2, DA3: MCP6001UT-I/OT; SOT23-5
DA4: PE4259; SC70
DD1: STM32F072R8T6; LQFP64
F1: MF-MSMF050; Fuse_1812_4532Metric_Pad1.30x3.40mm_HandSolder
H1, H2, H3, H4: MountingHole; MountingHole_2.5mm
HA1: HC0903A; MagneticBuzzer_CUI_CST-931RP-A
L1, L2: 10uH; IND_0805
L3: 33n; IND_0402
L4: 9.1n; IND_0402
L5: 12n; IND_0402
L6: 8.2n; IND_0402
L7: 7.5n; IND_0402
L8: *; IND_0402; not fitted
R1: 10k; RES_0603
R2, R3: 5.1k; RES_0603
R4, R5: *; RES_0402; not fitted
R6, R7, R8, R9, R10, R11: 100k; RES_0603
R12, R13, R14, R15, R19, R20, R21: 1k; RES_0603
R16: *; RES_0603
R17: 1k; RES_0402
R18: 10; RES_0402
R22: 510; RES_0402
SB1: KLS7-P8.5x8.5
SB2: SW_Push; SW_PUSH_6mm
TP1, TP2, TP3, TP4, TP5, TP6, TP7, TP8, TP9: TestPoint; TESTPOINT_1MM
U1: SX1276; QFN-28_EP_6x6_Pitch0.65mm
VD1: PMEG3010BEA; SOD323
VD2: USBLC6-2SC6; SOT23-6
VD3: ESDA5V3L; SOT-23
VD4, VD5: SFH213FA; LED_D5.0mm
VD6: TSAL6200; LED_D5.0mm_Clear
VD7: LED_BRG_5050; LED_RGB_5050-6
VT1, VT2, VT3: SI2302CDS; SOT23-3
WA1: ANT_GENERAL; Antenna_868_Bagryanets
XP1: PLS-6 LOCK; PinHeader_1x06_P2.54mm_Horizontal
XP2: HU-2/WF-2 Battery; PinHeader_1x02_P2.54mm_Horizontal
XS1: USBC-16P; USBC_10PF-074
ZQ1: 32MHz; 03225C4
ZQ2: 32.768kHz; Crystal_SMD_3215-2Pin_3.2x1.5mm
ZQ3: 24MHz; 03225C4

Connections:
+3V3: C4.2, C7.2, C10.2, C13.2, C17.2, C21.2, C25.2, C26.2, C28.2, C30.2, C32.2, C43.1, DA1.2 (VO), DA2.5, DA3.5, DA4.6 (VDD), DD1.1 (VBAT), DD1.19 (VDD), DD1.32 (VDD), DD1.48 (VDDIO2), DD1.64 (VDD), L1.1, R16.2, U1.3 (VBAT_ANA), U1.14 (VBAT_DIG), U1.24 (VBAT_RF), XP1.1
/Ant: C46.1, L8.2, WA1.1 (RF)
/BatCtrl: C8.2, DD1.26 (PB0), R6.1, R7.2
/Battery: C3.2, R5.2, R6.2, SB1.1, SB1.4, VD3.1 (IO1), VT1.2 (S)
/Buzzer: DD1.27 (PB1), VT3.1 (G)
/Conn.D+: VD2.3 (I/O2), XS1.A6 (DP1), XS1.B6 (DP2)
/Conn.D-: VD2.1 (I/O1), XS1.A7 (DN1), XS1.B7 (DN2)
/IR_IN1: C16.1, DD1.15 (PA1), R13.2, TP2.1
/IR_IN2: C15.1, DD1.16 (PA2), R12.2, TP1.1
/IR_Out: DD1.41 (PA8), VT2.1 (G)
/L.DIO0: DD1.25 (PC5), TP3.1, U1.8 (DIO0)
/L.DIO1: DD1.2 (PC13), TP4.1, U1.9 (DIO1)
/L.MISO: DD1.22 (PA6), TP6.1, U1.17 (MISO)
/L.MOSI: DD1.23 (PA7), TP7.1, U1.18 (MOSI)
/L.NSS: DD1.20 (PA4), TP8.1, U1.19 (NSS)
/L.OSC_IN: C9.1, U1.5 (XTA), ZQ1.1
/L.OSC_OUT: C14.1, U1.6 (XTB), ZQ1.2
/L.RESET: DD1.14 (PA0), TP9.1, U1.7 (~RESET)
/L.SCK: DD1.21 (PA5), TP5.1, U1.16 (SCK)
/LED.B: DD1.37 (PC6), R21.2
/LED.G: DD1.39 (PC8), R19.2
/LED.R: DD1.38 (PC7), R20.2
/OSC32_IN: C18.2, DD1.3 (PC14), ZQ2.1
/OSC32_OUT: DD1.4 (PC15), R14.2
/OSC_IN: C19.2, DD1.5 (PF0), ZQ3.1
/OSC_OUT: DD1.6 (PF1), R15.2
/RX_TX: C42.1, DA4.4 (CTRL), R17.2
/SWCLK: DD1.49 (PA14), XP1.2
/SWDIO: DD1.46 (PA13), XP1.4
/UART_RX: DD1.43 (PA10), XP1.6
/UART_TX: DD1.42 (PA9), XP1.5
/USB.D+: DD1.45 (PA12), VD2.4 (I/O2)
/USB.D-: DD1.44 (PA11), VD2.6 (I/O1)
/USB.power: C1.2, F1.2, R1.2, R4.2, VD1.A, VD2.5 (Vbus), VT1.1 (G)
/Unst.power: C2.2, DA1.3 (VI), HA1.1 (-), VD1.C, VD6.2 (A), VT1.3 (D)
/VBUS: F1.1, R4.1, XS1.A4B9 (VBUS), XS1.B4A9 (VBUS)
/VDDA: C27.2, C29.2, DD1.13 (VDDA), L1.2
/VSSA: C27.1, C29.1, DD1.12 (VSSA), L2.2
unnamed: C11.1, DA2.1, R10.2, R12.1
unnamed: C12.1, DA3.1, R11.2, R13.1
unnamed: C23.2, R14.1, ZQ2.2
unnamed: C24.2, R15.1, ZQ3.2
unnamed: C36.1, L4.2
unnamed: C36.2, C38.2, L6.1
unnamed: C37.1, C39.1, L5.2
unnamed: C40.2, L6.2, L7.1
unnamed: C44.2, C45.1, L8.1
unnamed: C5.2, DA2.3 (+), R8.1
unnamed: C11.2, DA2.4 (-), R10.1, VD4.1 (K)
unnamed: C6.2, DA3.3 (+), R9.1
unnamed: C12.2, DA3.4 (-), R11.1, VD5.1 (K)
unnamed: C41.2, DA4.1 (RF1), L7.2
unnamed: C39.2, DA4.3 (RF2)
unnamed: C44.1, DA4.5 (RFC)
unnamed: C31.2, DD1.7 (NRST), R16.1, SB2.2
unnamed: HA1.2 (+), R22.2
unnamed: R5.1, SB1.2, SB1.5, XP2.1
unnamed: L5.1, U1.21 (RFI_HF)
unnamed: C35.2, L3.2, L4.1, U1.22 (RFO_HF)
unnamed: R17.1, U1.20 (RX/TX)
unnamed: C22.2, U1.2 (VR_ANA)
unnamed: C20.2, U1.4 (VR_DIG)
unnamed: C33.2, C34.2, L3.1, U1.25 (VR_PA)
unnamed: R18.1, VD6.1 (K)
unnamed: R19.1, VD7.4 (BA)
unnamed: R20.1, VD7.5 (GA)
unnamed: R21.1, VD7.6 (RA)
unnamed: R18.2, VT2.3 (D)
unnamed: R22.1, VT3.3 (D)
unnamed: R2.1, XS1.A5 (CC1)
unnamed: R3.1, XS1.B5 (CC2)

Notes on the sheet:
GND
80mA - max
Перед АЦП добавлен фильтр на 250 кГц (по факту чуть меньше) Частота дискретизации 500 кГц
Uзmax > 5 В Iсmax > 500 mА SOT23
SWDIO
Контроль напряжения питания PB0 - ADC8
500 mA Предохранитель самовосстанавливающийся
TIM15/TIM2 - формирует частоту пачек для TIM1 - внутреннее соединение Заполнение пачек - ИК выход TIM1: 1 - PA8 2 - PA9 3 - PA10 4 - PA11
Не паять
Uзmax > 5 В Iсmax > 1 А SOT23
L.RESET Не важно на какой пин запихнуть
ИК приёмник PA1, PA2 - ADC2, ADC3
Излучатель звука электромагнитный
TIM2 - Chibi OS Или обнаружение сигнала через подсчёт отсчётов 1 - ??? 2 - PA1/PB3 3 - PA2/PB10 4 - PA3/PB11
BAT-
Analog power supply filter
RGB LED - 3 канала таймера TIM3: 1 - PA6/PC6 2 - PA7/PC7 3 - PB0/PC8 4 - PB1/PC9
3.3 В
UART TX
USB_DM - PA11 USB_DP - PA12
* Подбирать при регулировке
BAT+
Миниатюрная кнопка с фиксацией
Консоль для отладки USART1: TX - PA9/PB6 RX - PA10/PB7
Хотелось бы просыпаться от радио по DIO0/DIO1 + добавить EXTI прерывание?? WKUP: 1 - PA0 2 - PC13 3 - PE6 - нет у данного МК 4 - PA2 5 - PC5 6 - PB5 7 - PB15
Пищалка TIM14: 1 - PA4/PA7/PB1
Digital power supply filter
Питание от 3хАА батареек и ESD защита
Конденсатор рекомендуется по даташиту
VF=1.4 IFpk=200m
ADC: 1..7 - PA1..PA7 8, 9 - PB0, PB1 10..15 - PC0..PC5
ST-Link: SWDIO - PA13 SWCLK - PA14
1 А Шоттки SOD-323
SWCLK
UART RX
Конденсаторы располагать как можно ближе к соответствующим контактам
SPI1: Lora SCK - PA5/PB3 MISO - PA6/PB4 MOSI - PA7/PB5 NSS - PA4/PA15

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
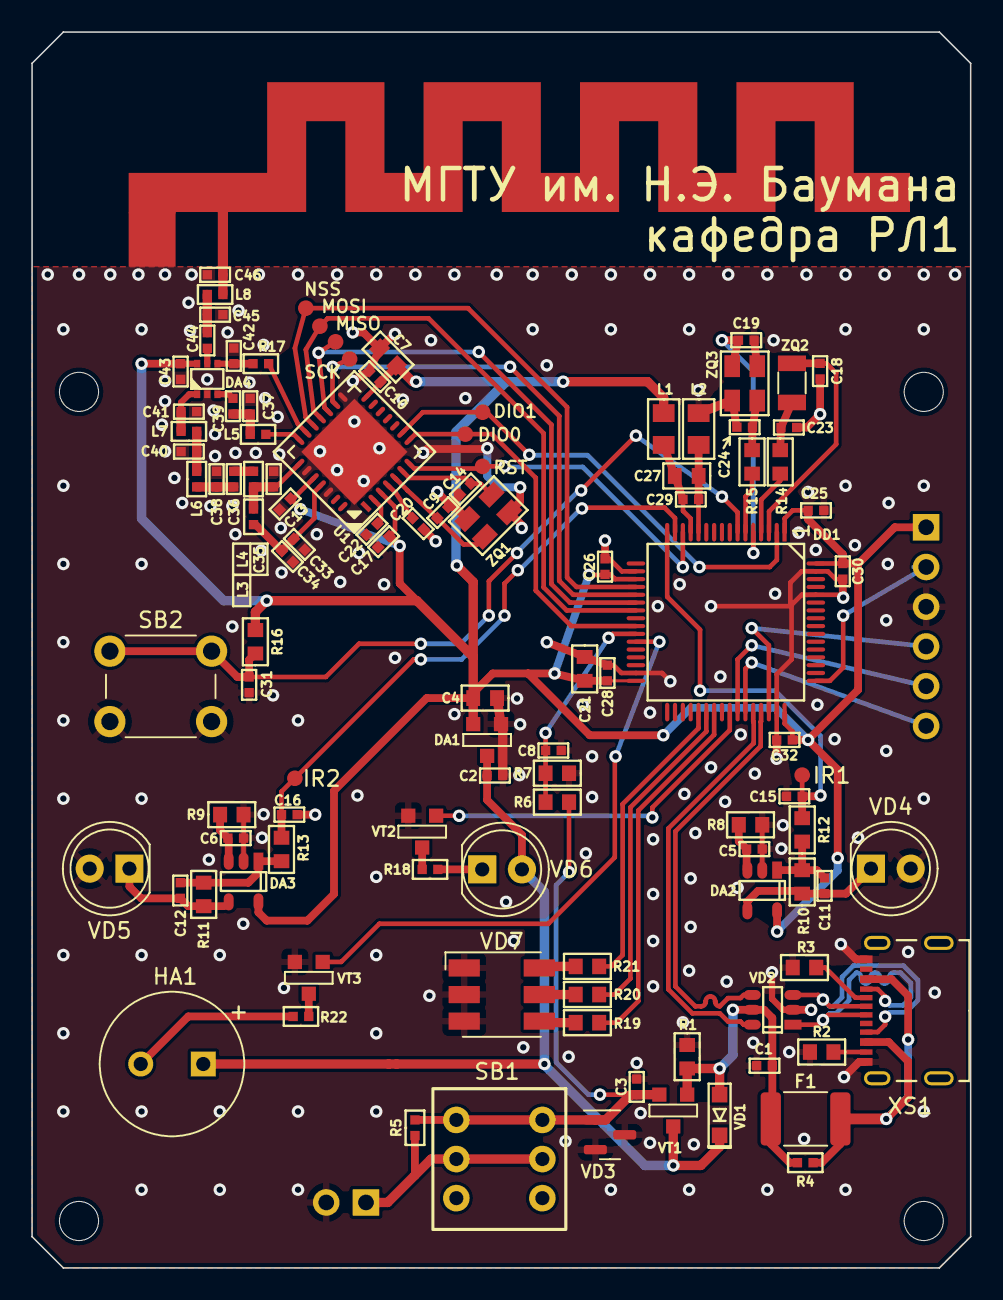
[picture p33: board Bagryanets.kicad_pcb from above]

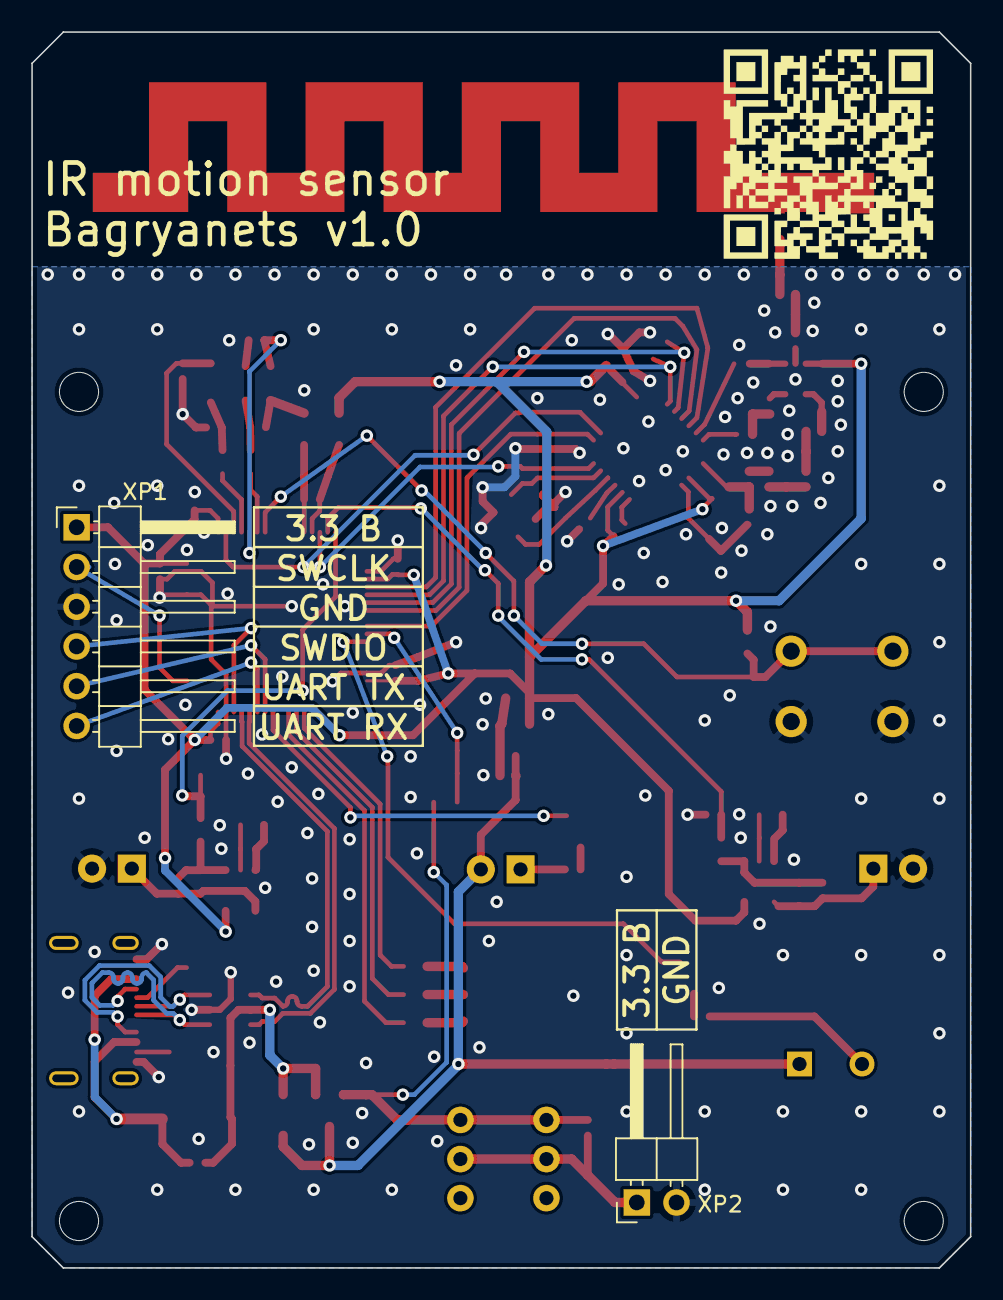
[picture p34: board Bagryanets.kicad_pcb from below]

Board: 2 copper layers, 60.0 x 79.0 mm, 116 parts (2 on the bottom side), 72 nets.

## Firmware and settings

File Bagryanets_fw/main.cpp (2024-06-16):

/*
 * main.cpp
 *
 *  Created on: 2024.02.08
 *      Author: Kais Lissera
 */

#include <stm32f0xx.h>
//
#include <stdint.h>
#include <math.h> // abs(x)
//
#include <rcc_F072.h>
#include <gpio_F072.h>
#include <tim_F072.h>
#include <interface_F072.h>
#include <adc_F072.h>

#include <board.h>

#include <FreeRTOS.h>
#include <lib.h>
#include <task.h>

//RTOS tasks declarations and priorities
/////////////////////////////////////////////////////////////////////
#define BLINK_TASK_PRIORITY 1
#define CLI_TASK_PRIORITY 1

#define UART_IRQ_PRIORITY configSTM_MAX_SYSCALL_INTERRUPT_PRIORITY
#define DMA_IRQ_PRIORITY configSTM_MAX_SYSCALL_INTERRUPT_PRIORITY

TaskHandle_t BlinkBlueTaskHandle;
void BlinkBlueTask(void *pvParametrs);

TaskHandle_t CliTaskHandle;
void CliTask(void *pvParametrs);

// Peripheral declaration
/////////////////////////////////////////////////////////////////////

// Debug UART shell
#define UART_BUFFER_SIZE 128
Uart_t UartCmd;
DmaChannel_t DmaChannel2 = {.Channel = DMA1_Channel2, .Number = 2, .Irq = DMA1_Channel2_3_IRQn};
DmaChannel_t DmaChannel3 = {.Channel = DMA1_Channel3, .Number = 2, .Irq = DMA1_Channel2_3_IRQn};
uint8_t CmdTxBuffer[UART_BUFFER_SIZE];
uint8_t CmdRxBuffer[UART_BUFFER_SIZE];
DmaTx_t CmdTxDma(&DmaChannel2, CmdTxBuffer, UART_BUFFER_SIZE);
DmaRx_t CmdRxDma(&DmaChannel3, CmdRxBuffer, UART_BUFFER_SIZE);
Cli_t CmdCli(&CmdTxDma, &CmdRxDma);

// ADC
#define ADC_BUFFER_SIZE 512
Timer_t AdcTrigger;
DmaChannel_t DmaChannel1 = {.Channel = DMA1_Channel1, .Number = 1, .Irq = DMA1_Channel1_IRQn};
uint8_t AdcRxBuffer[ADC_BUFFER_SIZE];
DmaRx_t AdcRxDma(&DmaChannel1, AdcRxBuffer, ADC_BUFFER_SIZE);

// IR transmitter
Timer_t IrCarrierTimer;
Timer_t IrEncoderTimer;

//IRQ Handlers
/////////////////////////////////////////////////////////////////////
extern "C"{
	void USART1_IRQHandler(){
		UartCmd.IrqHandler(); // Interrupt on character match
	}

	void DMA1_Channel2_3_IRQHandler(){
		CmdTxDma.IrqHandler(); // Interrupt on DMA transfer complete
	}

	void HardFault_Handler(){
	}
}

//Main and RTOS tasks
/////////////////////////////////////////////////////////////////////

void BlinkBlueTask(void *pvParameters){
//	uint32_t brigthness = 0;
	while(1){
//		UartCmdCli.Printf("[SYS] Blink blue task\n\r");
		vTaskDelay(pdMS_TO_TICKS(500));
	}
}

#define DECIMATOR_SIZE 64 // Must be degree of 2
#define MAXIMUM_LENGTH 16*1024 // Approximately 5 seconds

// Peak filter
class IirPeak_t{
public:
	int32_t a0;
	int32_t b1;
	int32_t b2;
	int32_t Output[2] = {0, 0}; // Previous outputs
	IirPeak_t(int32_t _a0, int32_t _b1, int32_t _b2){
		a0 = _a0; b1 = _b1; b2 = _b2;
	}

	// Not working
	void CalculateCoefficients(uint32_t f0, uint32_t fd, uint32_t bandWidth){
		// Calculation and normalization
		b1 = ceil(2*exp(-M_PI*bandWidth/fd)*cos(2*M_PI*f0/fd) * 256);
		b2 = ceil(-exp(-2*M_PI*bandWidth/fd) * 256);
		a0 = ceil((1-exp(-2*M_PI*bandWidth/fd)) * 256);
	}

	inline int32_t GetCurrentAbsOutput(uint32_t CurrentInput){
		int32_t temp = Output[1];
		Output[1] = Output[0];
		Output[0] = CurrentInput*a0 + Output[1]*b1 + temp*b2;
		Output[0] = Output[0] >> 8;
		return abs(Output[0]);
	}
};

void CliTask(void *pvParameters){
	IirPeak_t CarrierFilter(30, 211, -240);
	CmdCli.Printf("[SYS] Filter coefficients a0 = %d, b1 = %d, b2 = %d\n\r",
			CarrierFilter.a0, CarrierFilter.b1, CarrierFilter.b2);

	uint32_t DecimatorAccumulator = 0;
	uint32_t DecimatorCounter = 0;

	uint32_t max1 = 0;
	uint32_t max2 = 0;
	uint32_t max = 0;
	uint32_t max1counter = 0;
	uint32_t max2counter = MAXIMUM_LENGTH >> 1;

	uint32_t temp = 0;
	uint32_t gain = 1;
	AdcTrigger.StartCount();
	while(1){
		while(AdcRxDma.GetNumberOfBytesReady()){
			// Auto gain
			temp = AdcRxDma.ReadChar();
			if (temp > max1)
				max1 = temp;
			if (temp > max2)
				max2 = temp;
			// Iir peak filter for carrier frequency
			DecimatorAccumulator += CarrierFilter.GetCurrentAbsOutput(temp*gain);
			DecimatorCounter++;
			if (DecimatorCounter == DECIMATOR_SIZE){
				temp = DecimatorAccumulator / DECIMATOR_SIZE;
				DecimatorAccumulator = 0;
				DecimatorCounter = 0;
				// Auto gain gain update
				if (max1 > max2)
					max = max1;
				else
					max = max2;

				if (max*gain > 256)
					gain = gain >> 1;
				else if ((max*gain < 128) and (gain < 32))
					gain = gain << 1;

				max1counter++;
				max2counter++;
				if (max1counter == MAXIMUM_LENGTH){
					max1 = 0;
					max1counter = 0;
				}
				if (max2counter == MAXIMUM_LENGTH){
					max2 = 0;
					max2counter = 0;
				}

				CmdCli.Printf("%d  gain=%d\n\r", temp, gain, max);
				if (temp > 32)
					gpio::ActivatePin(LED_R);
				else
					gpio::DeactivatePin(LED_R);
			}
		}
	}
}

int main() {
	rcc::ResetAll();
	rcc::DisableAllClocks();
#ifdef USE_BOOTLOADER
	//Move interrupt vector table to RAM
	__disable_irq();
//	volatile uint32_t *VTable = (volatile uint32_t*)0x20000000;
//	for (uint32_t i = 0; i < 48; i++){
//	VTable[i] = *(volatile uint32_t*)(0x8002000 + i*4);
//	}

	for (uint32_t i = 0; i < 48; i++){
		volatile uint32_t* pRamTable = (uint32_t*)(0x20000000 + i*4);
		*pRamTable = *(volatile uint32_t*)(0x8002000 + i*4);
	}
	rcc::EnableClkSYSCFGCOMP();
	SYSCFG->CFGR1 = 0b11;
	__enable_irq();
#endif

	// Clock setup
	flash::SetFlashLatency(1);
	rcc::EnableHSE();
	rcc::SetupPLL(pllSrcHsePrediv, 16, 4);
	rcc::EnablePLL();
	rcc::SwitchSysClk(sysClkPll);

	uint32_t coreClockHz = rcc::GetCurrentSystemClock();
	uint32_t ahbClockHz = rcc::GetCurrentAHBClock(coreClockHz);
	uint32_t apbClockHz = rcc::GetCurrentAPBClock(ahbClockHz);
	uint32_t timClockHz = rcc::GetCurrentTimersClock(apbClockHz);

	// Enable peripheral clocks
	rcc::EnableClkAHB(RCC_AHBENR_GPIOCEN);
	rcc::EnableClkAHB(RCC_AHBENR_GPIOBEN);
	rcc::EnableClkAHB(RCC_AHBENR_GPIOAEN);
	rcc::EnableClkAHB(RCC_AHBENR_DMA1EN);

	rcc::EnableClkAPB1(RCC_APB1ENR_TIM2EN);
	rcc::EnableClkAPB1(RCC_APB1ENR_TIM14EN);

	rcc::EnableClkAPB2(RCC_APB2ENR_USART1EN);
	rcc::EnableClkAPB2(RCC_APB2ENR_ADCEN);
	rcc::EnableClkAPB2(RCC_APB2ENR_TIM1EN);
	rcc::EnableClkAPB2(RCC_APB2ENR_TIM15EN);

	// RGB LED setup
	gpio::SetupPin(LED_B, PullAir, GeneralOutput);
	gpio::SetupPin(LED_G, PullAir, GeneralOutput);
	gpio::SetupPin(LED_R, PullAir, GeneralOutput);

	UartCmd.Init(USART1, apbClockHz, 115200);
	gpio::SetupPin(PA9, PullAir, AlternateFunction, AF1);
	gpio::SetupPin(PA9, PullAir, AlternateFunction, AF1);
	UartCmd.EnableCharMatch('\r', USART1_IRQn ,UART_IRQ_PRIORITY);
	UartCmd.EnableDmaRequest(USART_CR3_DMAT | USART_CR3_DMAR);
	UartCmd.Enable();

	CmdTxDma.Init((uint32_t)&USART1->TDR);
	CmdRxDma.Init((uint32_t)&USART1->RDR);
	CmdRxDma.Start();

	// Timer for ADC
	// 1 MHz timer frequency, 200 kHz trigger frequency
	AdcTrigger.Init(TIM15, timClockHz, 3000000, 15-1, UpCounter);
	AdcTrigger.SetMasterMode(triggerOnUpdate);

	// ADC setup
	rcc::EnableHSI14();
	adc::Init(adcClkHsi14, adcResolution8bit, adcTriggerTim15Trgo, adcSample7_5Clk);
	adc::Calibrate();
	gpio::SetupPin(ADC_IR_1, PullAir, Analog); // ADC1 pin
//	gpio::SetupPin(ADC_IR_2, PullAir, Analog); // ADC2 pin - not used
	adc::SelectChannel(1); // Using only IR channel 1
	adc::Enable();
	adc::EnableDmaRequest(); // ADC on DMA channel 1
	adc::Start();

	// ADC DMA setup
	AdcRxDma.Init((uint32_t)&ADC1->DR);
	AdcRxDma.Start();

	//IR LED setup
	IrCarrierTimer.Init(TIM1, timClockHz, 360000, 10-1, UpCounter);
	IrCarrierTimer.ConfigureChannel(LED_IR, AF2, 1, outputComparePWM1);
	IrCarrierTimer.LoadCompareValue(1, 5);
	IrCarrierTimer.SetChannelAbility(1, Enable);
	IrCarrierTimer.SetSlaveMode(slaveModeTrigger, Itr1);
	IrCarrierTimer.SetOnePulseMode(32);
	IrCarrierTimer.StartCount();

	IrEncoderTimer.Init(TIM2, timClockHz, 360000, 10*64-1, UpCounter);
	IrEncoderTimer.SetMasterMode(triggerOnUpdate);
	IrEncoderTimer.StartCount();

	// Buzzer
	gpio::SetupPin(PB1, PullAir, GeneralOutput);
	gpio::DeactivatePin(PB1);

	xTaskCreate(&CliTask, "CLI", 256, NULL,
			CLI_TASK_PRIORITY, &CliTaskHandle);

	CmdCli.Printf("[SYS] Starting sheduler\n\r");
	vTaskStartScheduler();

	while(1);
}

//Main and FreeRTOS hooks
/////////////////////////////////////////////////////////////////////
void vApplicationMallocFailedHook(){
	CmdCli.Printf("[ERR] Malloc failed\n\r");
}

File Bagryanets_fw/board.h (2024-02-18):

/*
 * board.h
 *
 *  Created on: Feb 6, 2024
 *      Author: KONSTANTIN
 */

#ifndef BOARD_H_
#define BOARD_H_

//#define USE_SYSTICK_DELAY 1
#define HSE_FREQ_HZ 12000000

//ADC channels
#define ADC_IR_1 	PA1
#define ADC_IR_2 	PA2
#define ADC_BAT 	PB0

#define ADC_DMA_RX	DMA1_Channel1, (uint32_t)&ADC1->DR

// RGB led
#define LED_G	PC6
#define LED_R	PC7
#define LED_B	PC8
// IR led
#define LED_IR 	PA8

// UART shell parameters
#define UART_PARAMS		USART1, PA9, PA10, AF1, 115200
#define UART_DMA_TX		DMA1_Channel2, (uint32_t)&USART1->TDR
#define UART_DMA_RX		DMA1_Channel3, (uint32_t)&USART1->RDR

#endif /* BOARD_H_ */

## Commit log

2023-09-05 Renamed some files
    [Bagryanets.kicad_pcb, Bagryanets.kicad_sch]
2023-09-06 Updated schematic
    [Bagryanets.kicad_pcb, Bagryanets.kicad_sch]
2023-09-28 Added analog power supply filter
    [Bagryanets.kicad_sch]
2023-10-14 Added casing
    [Back-Back.SLDPRT, Back_Case.SLDPRT, Bagryanets-ass-v2.SLDASM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]
2023-10-31 PCB wiring, updated casing
    [Back.SLDPRT, Bagryanets-ass-v2.SLDASM, Bagryanets.kicad_pcb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]
2023-11-14 Added LSE clock, USB protection, battery monitoring to schematic, PCB rewiring, cover update
    [Back.SLDPRT, Bagryanets-ass-v2.SLDASM, Bagryanets.kicad_pcb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]
2023-11-19 Minor PCB changes
    [Bagryanets.kicad_pcb]
2023-11-19 GOST designators
    [Bagryanets.kicad_pcb, Bagryanets.kicad_sch]
2023-11-19 Added STL
    [Back_Cover.STL, Bagryanets.kicad_pcb, Bagryanets.kicad_sch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]
2024-01-08 Added bom, small schematic changes
    [Bagryanets.kicad_pcb, Bagryanets.kicad_sch, Bom_links.xlsx]
2024-01-27 CST files added to gitignore
    [Bagryanets-ass-v2.SLDASM]
2024-01-27 .gitignore fixed
    [Bagryanets-B_Cu.gbl, Bagryanets-B_Mask.gbs, Bagryanets-B_Silkscreen.gbo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]
2024-02-06 Adapting firmware for stm32f072r8t6
2024-02-07 Updated button and USB
    [Back-Back.SLDPRT, Back.SLDPRT, BackCover.SLDPRT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]
2024-02-08 Test firmware version
    [BackCover.SLDPRT, Bagryanets_assembly - BackCover-1.STL, Bagryanets_assembly.SLDASM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]
2024-02-18 Add ADC control
2024-02-29 Schematic update, IR amplifier working
    [Bagryanets.kicad_pcb, Bagryanets.kicad_sch]
2024-03-02 Casing with melt insert nuts
    [Back.SLDPRT, BackCover.SLDPRT, Bagryanets_assembly - Back-1.STL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]
2024-03-03 Cover fix
    [Back.SLDPRT, BackCover.SLDPRT, Bagryanets_assembly - Back-1.STL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]
2024-03-05 Bootloader not working
    [Back.SLDPRT, BackCover.SLDPRT, Bagryanets_assembly - Back-1.STL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]
2024-03-10 printf fix
2024-04-09 Altium schematic
    [Bagryanets-PcbLib.PcbLib, Bagryanets-Schlib.SchLib, Bagryanets.PcbDoc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]
2024-04-10 gitignore fix
    [Bagryanets-Schlib.SchLib, Bagryanets.PrjPcb, Bagryanets.SchDoc]
2024-04-14 Schematic update
    [Bagryanets-Schlib.SchLib, Bagryanets.SchDoc]
2024-04-21 Altium schematic ready
    [Bagryanets-PcbLib.PcbLib, Bagryanets-Schlib.SchLib, Bagryanets.PcbDoc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]
2024-04-23 PcbLib update
    [Bagryanets-PcbLib.PcbLib, Bagryanets-Schlib.SchLib, Bagryanets.PcbDoc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]
2024-04-24 begin PCB routing
    [Bagryanets-PcbLib.PcbLib, Bagryanets-Schlib.SchLib, Bagryanets.PcbDoc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]
2024-04-29 PCB wired
    [Bagryanets-PcbLib.PcbLib, Bagryanets-Schlib.SchLib, Bagryanets.PrjPcb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]
2024-05-07 Assembly drawing
    [Bagryanets-PcbLib.PcbLib, Bagryanets.PrjPcb]
2024-05-07 PCB drawing
    [Bagryanets-PcbLib.PcbLib, Bagryanets.PrjPcb]
2024-05-11 Schematic documentation
    [Bagryanets-Schlib.SchLib, Bagryanets.PrjPcb, Bagryanets.SchDoc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]
2024-05-16 Assembly drawings
    [Back.SLDPRT, BackCover.SLDPRT, Bagryanets-PcbLib.PcbLib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]
2024-05-17 Assembly drawings and specifications
    [Bagryanets-PcbLib.PcbLib, Bagryanets.PrjPcb, Bagryanets.SchDoc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]
2024-05-18 Added parts drawings
    [Bagryanets_assembly - Back-1.STL, Bagryanets_assembly - BackCover-1.STL, Bagryanets_assembly - BatteryCover-1.STL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]
2024-05-27 Сделаны дополнительные части ВКР
    [МГТУ.464415.001 Модуль управляющий.xlsm, МГТУ.464415.002 Модуль инфракрасный.xlsm, МГТУ.731146.001 Корпус.SLDPRT]
